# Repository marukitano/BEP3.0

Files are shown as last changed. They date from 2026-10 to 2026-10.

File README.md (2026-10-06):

# BEP3.0

**BEP3.0** is an electronics interface for classic BMW K-series motorcycles.

It was developed to make replacing the original instrument cluster ("Brotbox")
with an aftermarket speedometer easier while keeping the original wiring loom
as intact and reversible as possible.

This repository contains the **production and manufacturing files** for the
BEP3.0.

> **License notice:** The files in this repository may be copied, modified and
> used to build a BEP3.0 for **private, non-commercial purposes**.
> **Commercial use is prohibited.**
>
> The commercial right to sell BEP3.0 units is reserved exclusively to
> **Marcus Knop**. Third-party commercial manufacturing or sales require his
> explicit written permission.

## Supported motorcycles

The BEP3.0 was designed for the classic BMW K-series, including:

- BMW K75
- BMW K100
- BMW K1
- BMW K1100

Compatibility with a particular aftermarket instrument depends on the signals
and inputs supported by that instrument.

## What is in this repository?

The repository contains the files used to produce the BEP3.0 hardware, including
PCB/manufacturing data and related production files.

The files are published so that the project can be studied, preserved, repaired
and rebuilt by private users.

## License

### Allowed

- ✅ View and study the files
- ✅ Copy the files for private, non-commercial use
- ✅ Modify the files for private, non-commercial use
- ✅ Build your own BEP3.0 for private, non-commercial use
- ✅ Have a board manufactured for your own private, non-commercial use
- ✅ Share the files non-commercially if the license and attribution remain

### Not allowed

- ❌ Sell BEP3.0 units
- ❌ Sell bare PCBs based on the BEP3.0 design
- ❌ Sell kits based on the BEP3.0 design
- ❌ Offer paid manufacturing or assembly based on these files
- ❌ Use the BEP3.0 design, or substantial parts of it, in another commercial product
- ❌ Use the files for crowdfunding, pre-orders or other commercial fundraising

**All commercial rights remain reserved by Marcus Knop.**

Only Marcus Knop may offer BEP3.0 products for commercial sale. Commercial
manufacturing by third parties is only permitted with his explicit written
permission.

See [LICENSE](LICENSE) for the complete license terms.

> Because commercial use is restricted, this project is **source-available for
> private/non-commercial use** rather than open source in the OSI/open-hardware
> sense.

## Project page

More information about the BEP3.0:

https://maru-labs.com/portfolio/bep3-0-5/

## Contributions and issues

If you discover an error in the production files or documentation, please open
an issue before manufacturing a board.

## Disclaimer

The files are provided **as-is**, without warranty.

If you manufacture hardware from these files, you are responsible for checking
the design, component choices, manufacturing data, electrical safety and
suitability for your intended use.

---

**BEP3.0 / Maru Labs**  
Copyright © Marcus Knop

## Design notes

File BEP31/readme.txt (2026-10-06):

Hoi Fip

das einzige, was ich noch "mehr" habe ist die leiterbahn beim Blinker korrigieren, damit wir nichtmehr kratzen müssen. ansosnten hast du schon alles abgedeckt mit deiner liste.

Gruss Maru

Von: Philipp Gisler <pmgisler@gmx.ch>
Gesendet: Sonntag, 23. Oktober 2016 18:04
An: marcus.knop@outlook.com
Betreff: BEP änderungen brauche feedback
 
Hoi Marcus,
 
bin am layouten . kannst du mir deine Liste der Korrekturen noch schicken (asap)?
 
meine Änderungen umfassen:
1. die mittleren beiden Schrauben sollen keinen Kontakt auf Masse machen köönen
2. 78L10 footprint ändern und Masseverbindung herstellen die fehlte
3. Den Tiny switch footprint ändern dass man ihn auf die Platine runterlöten kann. IM 2. Schritt kommt er unter den BMW Stecker
4. Choke per default disabled
5. Bulb Test per default disabled
 
6. Reserve geht neu auf choke ODER einen switch unterhalb BMW Stecker zum Umschalten der Funktion (Reserve/Balkenanzeige) auf den Ausgang wie bisher (diese 2. Variante wird vom Platz vermutlich etwas eng)
7. neue Tachoschaltung gemäss BMW Original
8. einige Dioden auf Schottky Typ SS12 wechseln
9. Mosfet BSS138 am N Ausgang statt Darlington Array Ausgang
 
Gibt es sonst footprints die schlecht lötbar sind oder komische Beschriftungen?
 
Gruss
Philipp

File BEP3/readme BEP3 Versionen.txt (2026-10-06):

BEP3_RPM war ein erster Entwurf. Hier wird der BAR Graph Ausgang auf einen Lötpunkt gesetzt 
und der Reserve Ausgang ist wie bisher auf der Wago

BEP3_RPM_BAR wurde bei Seedstudion produziert. 
Hier wird die Idee umgesetzt, den BAR Graph Ausgang auf die Wago zu nehmen.
Achtung: dieses Layout hat Fehler:
1.10V Regler ist nicht auf GND verbunden
2. seitliche Schrauben berühren 12V und GND gleichzeitig.

BEP3_RPM_BAR_multi war bei Multi CB als Backup geplant, wurde aber nie bestellt. 
Der 78L10 Regler kann auf diesem Layout auch als Dreibein bestückt werden. Das Layout hat wohl auch Fehler

die komplette Historie befindet sich momentan im \Stücklisten Ordner

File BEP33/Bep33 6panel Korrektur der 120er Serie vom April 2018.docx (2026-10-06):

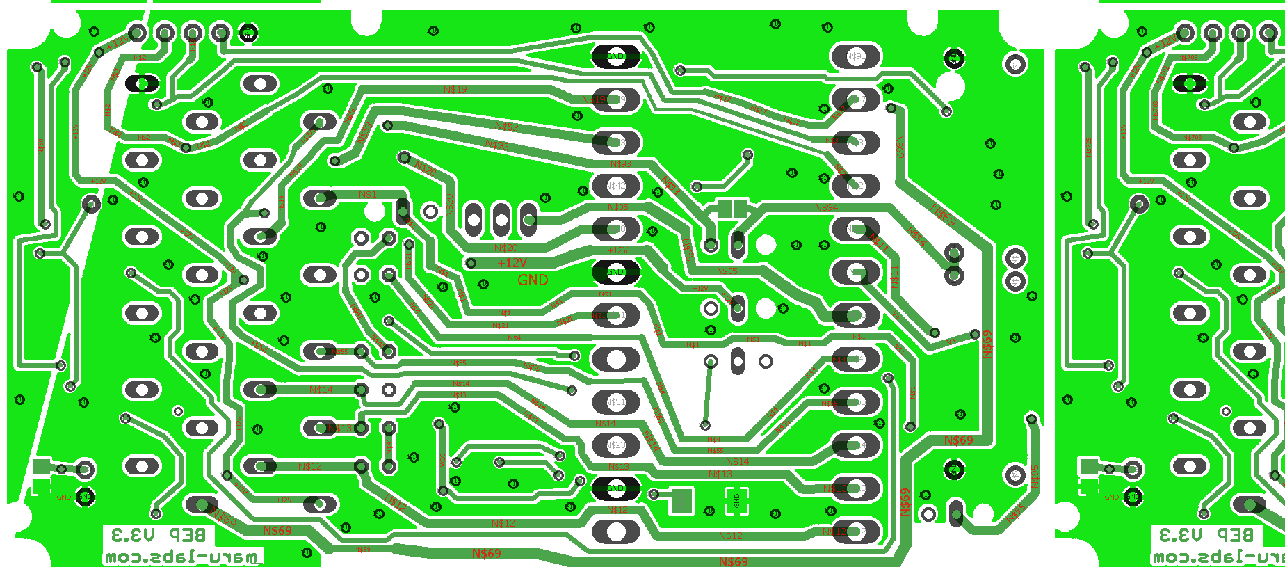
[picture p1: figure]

Hier mit Skalpell aufkratzen und Lötpunkt setzen. Es wird wohl auch ohne den Punkt funktionieren, würde das aber trotzdem tun zur Sicherheit und weil es hier sehr einfach ist

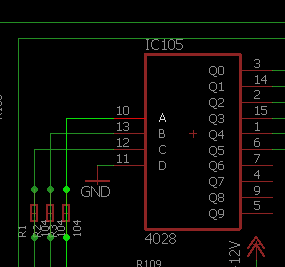
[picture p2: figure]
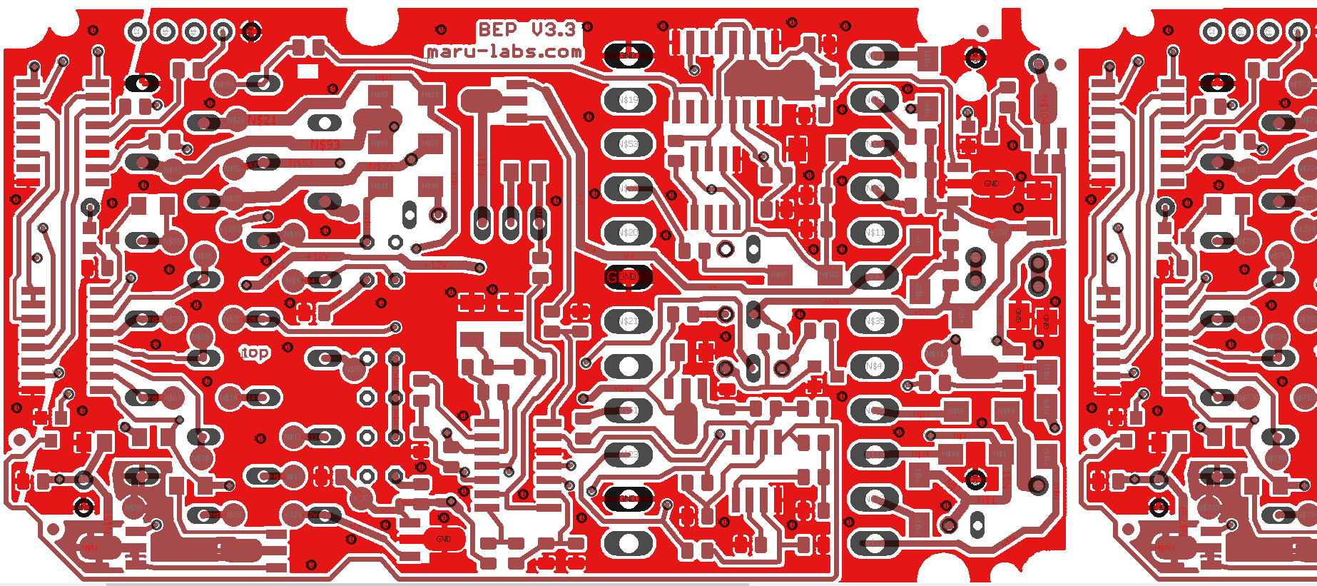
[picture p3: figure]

Das ist das Hauptproblem (pin 11):

Das Bein muss auf GND verbunden werden mit einem dünnen Draht. Wenn D nicht auf Masse ist, wird der BCD code um 2^3 zu viel dekodiert

Hier mit multimeter kurz checken ob das linke pad mit GND verbunden ist (es sollte eigentlich)→sonst würde stromquelle nicht laufen

Ev hier einen sicherheitsltötpunkt setzen, obwohl der Strom über das schwarze Pad fliessen sollte

Hier sieht man wie es orignal war

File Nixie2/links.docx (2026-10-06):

http://www.ebay.de/itm/QS30-1-Nixie-Rohren-NEU-Nanchang-V3-tube-tubes-Rohre-f-Uhr-Clock-NOS-ZM1022-/321815823694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

http://www.ebay.de/itm/new-13-pin-Nixie-Tube-Socket-for-GN4-ZM1020-B5092-B13B-PCB-monut-/391152356769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

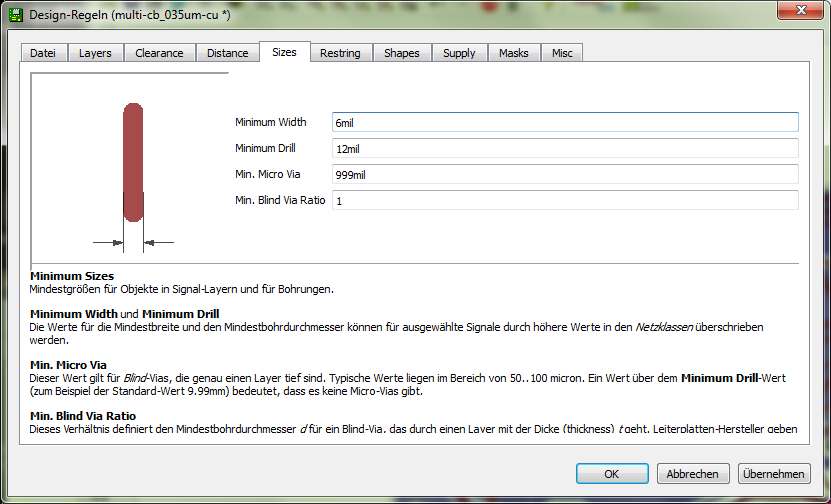
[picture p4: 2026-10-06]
design rules 2.png

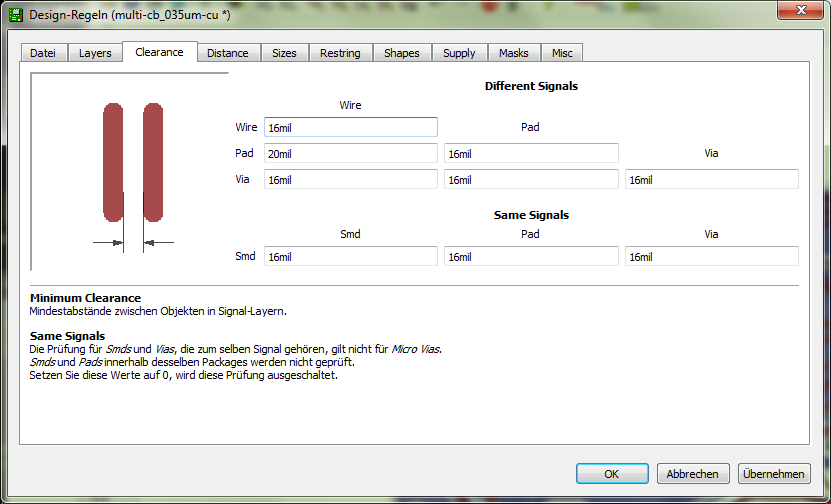
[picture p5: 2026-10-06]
design rules 1.png

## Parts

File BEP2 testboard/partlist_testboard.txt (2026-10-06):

Partlist

Exported from BMW_testboard.sch at 27.07.2015 17:11:16

EAGLE Version 6.4.0 Copyright (c) 1988-2013 CadSoft

Assembly variant: 

Part            Value          Device                   Package      Library             Sheet

öLDRUCK_SW2     TLLY4400       TLLY4400                 LED3MM       led                 1
12V             TPSPAD1-1.5MM  TPSPAD1-1.5MM            P1-13        testpin_BMW         1
12V_            TPSPAD1-1.5MM  TPSPAD1-1.5MM            P1-13        testpin_BMW         1
ABS_BLINK       TLLY4400       TLLY4400                 LED3MM       led                 1
BEIDE           TLLY4400       TLLY4400                 LED3MM       led                 1
BL              TPSPAD1-1.5MM  TPSPAD1-1.5MM            P1-13        testpin_BMW         1
BL-GR           TPSPAD1-1.5MM  TPSPAD1-1.5MM            P1-13        testpin_BMW         1
BL-RT           TPSPAD1-1.5MM  TPSPAD1-1.5MM            P1-13        testpin_BMW         1
BL-SW           TPSPAD1-1.5MM  TPSPAD1-1.5MM            P1-13        testpin_BMW         1
BR              TPSPAD1-1.5MM  TPSPAD1-1.5MM            P1-13        testpin_BMW         1
BR-GR           TPSPAD1-1.5MM  TPSPAD1-1.5MM            P1-13        testpin_BMW         1
BR-SW           TPSPAD1-1.5MM  TPSPAD1-1.5MM            P1-13        testpin_BMW         1
BR_             TPSPAD1-1.5MM  TPSPAD1-1.5MM            P1-13        testpin_BMW         1
C1              10u            C-EU025-024X044          C025-024X044 rcl                 1
C2              10u            C-EU025-024X044          C025-024X044 rcl                 1
C3              10n            C-EU025-024X044          C025-024X044 rcl                 1
CHOKE_SW1       TLLY4400       TLLY4400                 LED3MM       led                 1
DAUERPLUS       TLLY4400       TLLY4400                 LED3MM       led                 1
FERNLICHT_BLK   TLLY4400       TLLY4400                 LED3MM       led                 1
GANG_1          TLLY4400       TLLY4400                 LED3MM       led                 1
GANG_2          TLLY4400       TLLY4400                 LED3MM       led                 1
GANG_3          TLLY4400       TLLY4400                 LED3MM       led                 1
GANG_4          TLLY4400       TLLY4400                 LED3MM       led                 1
GANG_5          TLLY4400       TLLY4400                 LED3MM       led                 1
GB-SW           TPSPAD1-1.5MM  TPSPAD1-1.5MM            P1-13        testpin_BMW         1
GB-WS           TPSPAD1-1.5MM  TPSPAD1-1.5MM            P1-13        testpin_BMW         1
GE-BL           TPSPAD1-1.5MM  TPSPAD1-1.5MM            P1-13        testpin_BMW         1
GESCHW_WAGO_BLK TLLY4400       TLLY4400                 LED3MM       led                 1
GND_            TPSPAD1-1.5MM  TPSPAD1-1.5MM            P1-13        testpin_BMW         1
GR              TPSPAD1-1.5MM  TPSPAD1-1.5MM            P1-13        testpin_BMW         1
GR-SW           TPSPAD1-1.5MM  TPSPAD1-1.5MM            P1-13        testpin_BMW         1
IC1             4020N          4020N                    DIL16        40xx                1
IC2             NE555          NE555                    DIL-08       st-microelectronics 1
IC5             BTS141         BTS141                   TO220-3-45   optosonde_bruker    1
LADEKONTROL_BLK TLLY4400       TLLY4400                 LED3MM       led                 1
LAMPENTEST_SW4  TLLY4400       TLLY4400                 LED3MM       led                 1
LINKS           TLLY4400       TLLY4400                 LED3MM       led                 1
NEUTRAL         TLLY4400       TLLY4400                 LED3MM       led                 1
R1              390            R-EU_R0805               R0805        rcl                 1
R2              390            R-EU_R0805               R0805        rcl                 1
R3              390            R-EU_R0805               R0805        rcl                 1
R4              390            R-EU_R0805               R0805        rcl                 1
R5              390            R-EU_R0805               R0805        rcl                 1
R6              390            R-EU_R0805               R0805        rcl                 1
R7              390            R-EU_R0805               R0805        rcl                 1
R8              10k            R-EU_R0805               R0805        rcl                 1
R9              10k            R-EU_R0805               R0805        rcl                 1
R10             10k            R-EU_R0805               R0805        rcl                 1
R11             390            R-EU_R0805               R0805        rcl                 1
R12             10k            R-EU_R0805               R0805        rcl                 1
R13             10k            R-EU_0207/12             0207/12      rcl                 1
R14             20k            R-EU_0207/12             0207/12      rcl                 1
R15             390            R-EU_R0805               R0805        rcl                 1
R16             390            R-EU_R0805               R0805        rcl                 1
R17             10k            R-EU_R0805               R0805        rcl                 1
R18             390            R-EU_R0805               R0805        rcl                 1
R19             390            R-EU_R0805               R0805        rcl                 1
R20             390            R-EU_R0805               R0805        rcl                 1
R21             39             R-EU_0207/12             0207/12      rcl                 1
R22             100            R-EU_0207/12             0207/12      rcl                 1
R23             10k            R-EU_R0805               R0805        rcl                 1
R27             0              R-EU_0207/12             0207/12      rcl                 1
R28             390            R-EU_R0805               R0805        rcl                 1
R29             390            R-EU_R0805               R0805        rcl                 1
R30             390            R-EU_R0805               R0805        rcl                 1
R31             390            R-EU_R0805               R0805        rcl                 1
R32             10k            R-EU_0207/12             0207/12      rcl                 1
R33             10k            R-EU_0207/15             0207/15      rcl                 1
RECHT           TLLY4400       TLLY4400                 LED3MM       led                 1
S1              DTE6K          DTE6K                    DTE6K        switch              1
S2              DTE6K          DTE6K                    DTE6K        switch              1
S3              DTE6K          DTE6K                    DTE6K        switch              1
S4              DTE6K          DTE6K                    DTE6K        switch              1
START/NEUTRAL   TLLY4400       TLLY4400                 LED3MM       led                 1
SW-GR           TPSPAD1-1.5MM  TPSPAD1-1.5MM            P1-13        testpin_BMW         1
T1                             MMBTA42LT1-NPN-SOT23-BEC SOT23-BEC    transistor          1
T2                             MMBTA42LT1-NPN-SOT23-BEC SOT23-BEC    transistor          1
T3                             MMBTA42LT1-NPN-SOT23-BEC SOT23-BEC    transistor          1
TACHSIG_REL_BLK TLLY4400       TLLY4400                 LED3MM       led                 1
TANKGEB_SW1-4   TLLY4400       TLLY4400                 LED3MM       led                 1
TEMP...SW3      TLLY4400       TLLY4400                 LED3MM       led                 1
TP12            TPSPAD1-1.5MM  TPSPAD1-1.5MM            P1-13        testpin_BMW         1
TP13            TPSPAD1-1.5MM  TPSPAD1-1.5MM            P1-13        testpin_BMW         1
TP14            TPSPAD1-1.5MM  TPSPAD1-1.5MM            P1-13        testpin_BMW         1
TP15            TPSPAD1-1.5MM  TPSPAD1-1.5MM            P1-13        testpin_BMW         1
TP20            TPSPAD1-1.5MM  TPSPAD1-1.5MM            P1-13        testpin_BMW         1
TP27            TPSPAD1-1.5MM  TPSPAD1-1.5MM            P1-13        testpin_BMW         1
TP28            TPSPAD1-1.5MM  TPSPAD1-1.5MM            P1-13        testpin_BMW         1
TP29            TPSPAD1-1.5MM  TPSPAD1-1.5MM            P1-13        testpin_BMW         1
TP31            TPSPAD1-1.5MM  TPSPAD1-1.5MM            P1-13        testpin_BMW         1
TP32            TPSPAD1-1.5MM  TPSPAD1-1.5MM            P1-13        testpin_BMW         1
TP33            TPSPAD1-1.5MM  TPSPAD1-1.5MM            P1-13        testpin_BMW         1
TP34            TPSPAD1-1.5MM  TPSPAD1-1.5MM            P1-13        testpin_BMW         1
TP35            TPSPAD1-1.5MM  TPSPAD1-1.5MM            P1-13        testpin_BMW         1
TP36            TPSPAD1-1.5MM  TPSPAD1-1.5MM            P1-13        testpin_BMW         1
TP37            TPSPAD1-1.5MM  TPSPAD1-1.5MM            P1-13        testpin_BMW         1
TP38            TPSPAD1-1.5MM  TPSPAD1-1.5MM            P1-13        testpin_BMW         1
TP39            TPSPAD1-1.5MM  TPSPAD1-1.5MM            P1-13        testpin_BMW         1
TP40            TPSPAD1-1.5MM  TPSPAD1-1.5MM            P1-13        testpin_BMW         1
TP41            TPSPAD1-1.5MM  TPSPAD1-1.5MM            P1-13        testpin_BMW         1
TP42            TPSPAD1-1.5MM  TPSPAD1-1.5MM            P1-13        testpin_BMW         1
TP43            TPSPAD1-1.5MM  TPSPAD1-1.5MM            P1-13        testpin_BMW         1
TP44            TPSPAD1-1.5MM  TPSPAD1-1.5MM            P1-13        testpin_BMW         1
VI-SW           TPSPAD1-1.5MM  TPSPAD1-1.5MM            P1-13        testpin_BMW         1
VI-WS           TPSPAD1-1.5MM  TPSPAD1-1.5MM            P1-13        testpin_BMW         1
WARNLAMPE_SW4   TLLY4400       TLLY4400                 LED3MM       led                 1
WS              TPSPAD1-1.5MM  TPSPAD1-1.5MM            P1-13        testpin_BMW         1
WS-BL           TPSPAD1-1.5MM  TPSPAD1-1.5MM            P1-13        testpin_BMW         1
WS_             TPSPAD1-1.5MM  TPSPAD1-1.5MM            P1-13        testpin_BMW         1
ZüNDUNGSPLUS    TLLY4400       TLLY4400                 LED3MM       led                 1

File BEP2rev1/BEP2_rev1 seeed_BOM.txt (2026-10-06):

Bill of Material from BEP2_rev1 seeed.sch, 97 parts, as of 05.05.2016 11:49:22

Part		Description					Sheet
1		WAGO SREW CLAMP					1
2		WAGO SREW CLAMP					1
C1		CAPACITOR, European symbol			1
C2		302010183					1
C3		302010183					1
C4		302010165					1
C5		302010165					1
C6		CAPACITOR, European symbol			1
C7		CAPACITOR, European symbol			1
C8		302010146					1
D1		304010013					1
D2		304010013					1
D8		304010013					1
D10		304010013					1
D11		304010013					1
D12		304010013					1
D13		304010013					1
D14		304010013					1
D15		304010013					1
IC1		VOLTAGE REGULATOR				1
IC3		BCD to decimal DECODER				1
IC4		Positive VOLTAGE REGULATOR			1
IC6		DRIVER ARRAY					1
IC7		Low Power Low Offset Voltage Quad Comparators	1
J1		.100" (2.54mm) Center Header - 2 Pin		1
LED1		LED						1
LED2		LED						1
LED3		LED						1
LED4		LED						1
LED5		LED						1
LED6		LED						1
LED7		LED						1
Q1		305030010					1
Q2		305020006					1
Q3		 						1
R1		301010306					1
R2		301010361					1
R3		301010315					1
R4		301010319					1
R5		301010361					1
R6		301010361					1
R7		301010104					1
R8		301010104					1
R9		301010306					1
R10		301010196					1
R11		301010319					1
R12		301010196					1
R13		301010311					1
R14		301010196					1
R15		301010241					1
R16		301010361					1
R17		301010333					1
R18		301010405					1
R19		301010361					1
R20		301010405					1
R21		301010405					1
R22		RESISTOR, European symbol			1
R23		RESISTOR, European symbol			1
R24		RESISTOR, European symbol			1
R25		RESISTOR, European symbol			1
R26		RESISTOR, European symbol			1
R27		RESISTOR, European symbol			1
R28		RESISTOR, European symbol			1
R29		301010196					1
R30		301010196					1
R31		301010196					1
R32		RESISTOR, European symbol			1
R38		301010311					1
R39		RESISTOR, European symbol			1
T1		 						1
TACHO_BEL	TEST PIN					1
TP1		TEST PIN					1
TP2		TEST PIN					1
TP3		TEST PIN					1
TP4		TEST PIN					1
TP5		TEST PIN					1
TP6		TEST PIN					1
TP7		TEST PIN					1
TP8		TEST PIN					1
TP9		TEST PIN					1
TP10		TEST PIN					1
TP11		TEST PIN					1
TP12		TEST PIN					1
TP16		TEST PIN					1
TP17		TEST PIN					1
TP18		TEST PIN					1
TP19		TEST PIN					1
TP21		TEST PIN					1
TP22		TEST PIN					1
TP23		TEST PIN					1
TP24		TEST PIN					1
TP25		TEST PIN					1
TP26		TEST PIN					1
X1		BMW CONNECTOR					1
X2		.100" (2.54mm) Center Header - 2 Pin		1
X3		.100" (2.54mm) Center Header - 5 Pin		1
ZüNDSPULE	TEST PIN					1

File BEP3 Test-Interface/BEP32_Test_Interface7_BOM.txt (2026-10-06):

Stückliste exportiert aus D:/marulabs/Layout_Eagle/BEP3 Test-Interface/BEP32_Test_Interface7.sch am 18.02.2018 18:58

Part                        Value                Device                             Package          Description                                                             MF                   MPN      OC_FARNELL OC_NEWARK VALUE 
2.5VTOAD                                         1,6/0,9                            1,6/0,9          THROUGH-HOLE PAD                                                                                                                 
2.5VTOAD1                                        1,6/0,9                            1,6/0,9          THROUGH-HOLE PAD                                                                                                                 
2.5VTOAD2                                        1,6/0,9                            1,6/0,9          THROUGH-HOLE PAD                                                                                                                 
6V_OK_BOT                                        1,6/0,9                            1,6/0,9          THROUGH-HOLE PAD                                                                                                                 
6V_OK_TOP                                        1,6/0,9                            1,6/0,9          THROUGH-HOLE PAD                                                                                                                 
6V_VOLTAGE_BOT                                   1,6/0,9                            1,6/0,9          THROUGH-HOLE PAD                                                                                                                 
6V_VOLTAGE_TOP                                   1,6/0,9                            1,6/0,9          THROUGH-HOLE PAD                                                                                                                 
10V_OK_BOT                                       1,6/0,9                            1,6/0,9          THROUGH-HOLE PAD                                                                                                                 
10V_OK_TOP                                       1,6/0,9                            1,6/0,9          THROUGH-HOLE PAD                                                                                                                 
10V_VOLTAGE_BOT                                  1,6/0,9                            1,6/0,9          THROUGH-HOLE PAD                                                                                                                 
10V_VOLTAGE_TOP                                  1,6/0,9                            1,6/0,9          THROUGH-HOLE PAD                                                                                                                 
C1                          tbd                  C-EUC1206K                         C1206K           CAPACITOR, European symbol                                                                                                       
C2                          4.7uf                C-EU025_050-025X075                C025_050-025X075 CAPACITOR, European symbol                                                                                                       
C3                          100nF                C-EUC1206K                         C1206K           CAPACITOR, European symbol                                                                                                       
C4                          tbd                  C-EUC1206K                         C1206K           CAPACITOR, European symbol                                                                                                       
C5                          100nF                C-EUC1206K                         C1206K           CAPACITOR, European symbol                                                                                                       
CC_VOLTAGE_BOT                                   1,6/0,9                            1,6/0,9          THROUGH-HOLE PAD                                                                                                                 
CC_VOLTAGE_OK_BOT                                1,6/0,9                            1,6/0,9          THROUGH-HOLE PAD                                                                                                                 
CC_VOLTAGE_OK_TOP                                1,6/0,9                            1,6/0,9          THROUGH-HOLE PAD                                                                                                                 
CC_VOLTAGE_TOP                                   1,6/0,9                            1,6/0,9          THROUGH-HOLE PAD                                                                                                                 
D1                          1N4007               DIODE-GEN-PURPOSE-1KV-1A(DO-214AC) DO-214AC         304010013                                                                                    1N4007                        1N4007
D2                          4V7                  ZENER-DIODEF126-10                 F126Z10          Z-Diode                                                                                                                          
D3                          4V7                  ZENER-DIODEF126-10                 F126Z10          Z-Diode                                                                                                                          
D4                          1N4007               DIODE-GEN-PURPOSE-1KV-1A(DO-214AC) DO-214AC         304010013                                                                                    1N4007                        1N4007
DISABLE_MANUAL_BOT                               1,6/0,9                            1,6/0,9          THROUGH-HOLE PAD                                                                                                                 
DISABLE_MANUAL_TOP                               1,6/0,9                            1,6/0,9          THROUGH-HOLE PAD                                                                                                                 
IC1                         74HC595N             74HC595N                           DIL16            8-bit SHIFT REGISTER, output latch                                                                                               
IC3                         4532N                4532N                              DIL16            8-bit PRIORITY ENCODER                                                                                                           
IC5                         ULN2003              ULN2803A                           DIL18            DRIVER ARRAY                                                                                                                     
IC6                         74HC595N             74HC595N                           DIL16            8-bit SHIFT REGISTER, output latch                                                                                               
IC7                         ULN2003              ULN2803A                           DIL18            DRIVER ARRAY                                                                                                                     
IC8                         74HC165N             74HC165N                           DIL16            8-bit parallel load SHIFT REGISTER                                                                                               
IC9                         74HC165N             74HC165N                           DIL16            8-bit parallel load SHIFT REGISTER                                                                                               
IC10                        74HC165N             74HC165N                           DIL16            8-bit parallel load SHIFT REGISTER                                                                                               
IC11                        4046N                4046N                              DIL16            Micropower PLL                                                                                                                   
IC12                        4070N                4070N                              DIL14            Quad 2-input XOR                                                                                                                 
IC13                        LM358N               LM358N                             DIL08            OP AMP also LM158; LM258; LM2904                                                                                                 
IC14                        4053N                4053N                              DIL16            Triple 2-channel ANALOG MULTIPLEXER                                                                                              
IC15                        74HC132N             74HC132N                           DIL14            Quad 2-input NAND schmitt trigger                                                                                                
IC16                        LM358N               LM358N                             DIL08            OP AMP also LM158; LM258; LM2904                                                                                                 
IC18                        LM358N               LM358N                             DIL08            OP AMP also LM158; LM258; LM2904                                                                                                 
IC20                        4046N                4046N                              DIL16            Micropower PLL                                                                                                                   
IC21                        4070N                4070N                              DIL14            Quad 2-input XOR                                                                                                                 
JP1                                              JP2E                               JP2              JUMPER                                                                                                                           
JP2                                              JP2E                               JP2              JUMPER                                                                                                                           
JP3                                              JP2E                               JP2              JUMPER                                                                                                                           
JP4                                              JP1E                               JP1              JUMPER                                                                                                                           
JP5                                              JP1E                               JP1              JUMPER                                                                                                                           
LED_6V_HIGH                                      LED5MM                             LED5MM           LED                                                                                                                              
LED_6V_LOW                                       LED5MM                             LED5MM           LED                                                                                                                              
LED_6V_OK                                        LED5MM                             LED5MM           LED                                                                                                                              
LED_10V_HIGH                                     LED5MM                             LED5MM           LED                                                                                                                              
LED_10V_LOW                                      LED5MM                             LED5MM           LED                                                                                                                              
LED_10V_OK                                       LED5MM                             LED5MM           LED                                                                                                                              
LED_<                                            LED5MM                             LED5MM           LED                                                                                                                              
LED_<>                                           LED5MM                             LED5MM           LED                                                                                                                              
LED_>                                            LED5MM                             LED5MM           LED                                                                                                                              
LED_ABS                                          LED5MM                             LED5MM           LED                                                                                                                              
LED_ALT                                          LED5MM                             LED5MM           LED                                                                                                                              
LED_BT                                           LED5MM                             LED5MM           LED                                                                                                                              
LED_CC                                           LED5MM                             LED5MM           LED                                                                                                                              
LED_CC_HIGH                                      LED5MM                             LED5MM           LED                                                                                                                              
LED_CC_LOW                                       LED5MM                             LED5MM           LED                                                                                                                              
LED_CC_OK                                        LED5MM                             LED5MM           LED                                                                                                                              
LED_CHK                                          LED5MM                             LED5MM           LED                                                                                                                              
LED_DREHZAHL                                     LED5MM                             LED5MM           LED                                                                                                                              
LED_G1                                           LED5MM                             LED5MM           LED                                                                                                                              
LED_G2                                           LED5MM                             LED5MM           LED                                                                                                                              
LED_G3                                           LED5MM                             LED5MM           LED                                                                                                                              
LED_G4                                           LED5MM                             LED5MM           LED                                                                                                                              
LED_G5                                           LED5MM                             LED5MM           LED                                                                                                                              
LED_HIB                                          LED5MM                             LED5MM           LED                                                                                                                              
LED_N                                            LED5MM                             LED5MM           LED                                                                                                                              
LED_OIL                                          LED5MM                             LED5MM           LED                                                                                                                              
LED_RES                                          LED5MM                             LED5MM           LED                                                                                                                              
LED_SPD                                          LED5MM                             LED5MM           LED                                                                                                                              
LED_START                                        LED5MM                             LED5MM           LED                                                                                                                              
LED_SWP                                          LED5MM                             LED5MM           LED                                                                                                                              
LED_TMP                                          LED5MM                             LED5MM           LED                                                                                                                              
LED_WRN                                          LED5MM                             LED5MM           LED                                                                                                                              
PAD1                                             1,6/0,9                            1,6/0,9          THROUGH-HOLE PAD                                                                                                                 
PAD_2_RPM_FREQUENZZäHLER2                        1,6/0,9                            1,6/0,9          THROUGH-HOLE PAD                                                                                                                 
PAD_2_SPEED_FREQUENZZäHLER1                      1,6/0,9                            1,6/0,9          THROUGH-HOLE PAD                                                                                                                 
PAD_6V_TEST                                      1,6/0,9                            1,6/0,9          THROUGH-HOLE PAD                                                                                                                 
PAD_10V_TEST                                     1,6/0,9                            1,6/0,9          THROUGH-HOLE PAD                                                                                                                 
PAD_12V_IN                                       1,6/0,9                            1,6/0,9          THROUGH-HOLE PAD                                                                                                                 
PAD_GND                                          1,6/0,9                            1,6/0,9          THROUGH-HOLE PAD                                                                                                                 
PAD_RESERVE_SPANNUNG                             1,6/0,9                            1,6/0,9          THROUGH-HOLE PAD                                                                                                                 
Q1                          BSP452T1             BSP452T1                           SOT223                                                                                                                                            
Q2                          BSP452T1             BSP452T1                           SOT223                                                                                                                                            
Q3                          BSP452T1             BSP452T1                           SOT223                                                                                                                                            
Q4                          BSP452T1             BSP452T1                           SOT223                                                                                                                                            
Q5                          IRF540               IRF540                             TO220BV          HEXFET Power MOSFET                                                                                                              
Q6                          IRF540               IRF540                             TO220BV          HEXFET Power MOSFET                                                                                                              
Q7                          IRF540               IRF540                             TO220BV          HEXFET Power MOSFET                                                                                                              
Q8                          BC548                BC548                              TO92-EBC         NPN Transistor                                                                                                                   
Q9                          BSS138               BSS138                             SOT23            BSS138 N-Channel Logic Level Enhancement Mode Field Effect Transistor   Fairchild            BSS138   9845330    67R2009         
Q10                         BSS138               BSS138                             SOT23            BSS138 N-Channel Logic Level Enhancement Mode Field Effect Transistor   Fairchild            BSS138   9845330    67R2009         
Q12                         BSS138               BSS138                             SOT23            BSS138 N-Channel Logic Level Enhancement Mode Field Effect Transistor   Fairchild            BSS138   9845330    67R2009         
Q13                         BSS138               BSS138                             SOT23            BSS138 N-Channel Logic Level Enhancement Mode Field Effect Transistor   Fairchild            BSS138   9845330    67R2009         
R1                          100                  R-EU_0207/10                       0207/10          RESISTOR, European symbol                                                                                                        
R2                          39                   R-EU_0207/10                       0207/10          RESISTOR, European symbol                                                                                                        
R3                          10k                  R-EU_0207/10                       0207/10          RESISTOR, European symbol                                                                                                        
R4                          22k                  R-EU_0207/10                       0207/10          RESISTOR, European symbol                                                                                                        
R5                          100k                 R-EU_0207/10                       0207/10          RESISTOR, European symbol                                                                                                        
R6                          100k                 R-EU_0207/10                       0207/10          RESISTOR, European symbol                                                                                                        
R7                          2.2k                 R-EU_0207/10                       0207/10          RESISTOR, European symbol                                                                                                        
R11                         R_fmax               R-EU_0207/10                       0207/10          RESISTOR, European symbol                                                                                                        
R12                         R_fmin=inf           R-EU_0207/10                       0207/10          RESISTOR, European symbol                                                                                                        
R13                         100k                 R-EU_0207/10                       0207/10          RESISTOR, European symbol                                                                                                        
R14                         10k                  R-EU_0207/10                       0207/10          RESISTOR, European symbol                                                                                                        
R15                         39                   R-EU_0207/10                       0207/10          RESISTOR, European symbol                                                                                                        
R16                         1.05k                R-EU_0207/10                       0207/10          RESISTOR, European symbol                                                                                                        
R17                         210                  R-EU_0207/10                       0207/10          RESISTOR, European symbol                                                                                                        
R18                         10k                  R-EU_0207/10                       0207/10          RESISTOR, European symbol                                                                                                        
R19                         10k                  R-EU_0207/10                       0207/10          RESISTOR, European symbol                                                                                                        
R20                         10k                  R-EU_0207/10                       0207/10          RESISTOR, European symbol                                                                                                        
R21                         10k                  R-EU_0207/10                       0207/10          RESISTOR, European symbol                                                                                                        
R22                         10k                  R-EU_0207/10                       0207/10          RESISTOR, European symbol                                                                                                        
R23                         3k                   R-EU_0207/10                       0207/10          RESISTOR, European symbol                                                                                                        
R24                         1k                   R-EU_0207/10                       0207/10          RESISTOR, European symbol                                                                                                        
R25                         2.8k                 R-EU_0207/10                       0207/10          RESISTOR, European symbol                                                                                                        
R26                         2k                   R-EU_0207/10                       0207/10          RESISTOR, European symbol                                                                                                        
R30                         10k                  R-EU_0207/10                       0207/10          RESISTOR, European symbol                                                                                                        
R31                         10k                  R-EU_0207/10                       0207/10          RESISTOR, European symbol                                                                                                        
R32                         10k                  R-EU_0207/10                       0207/10          RESISTOR, European symbol                                                                                                        
R33                         10k                  R-EU_0207/10                       0207/10          RESISTOR, European symbol                                                                                                        
R34                         10k                  R-EU_0207/10                       0207/10          RESISTOR, European symbol
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

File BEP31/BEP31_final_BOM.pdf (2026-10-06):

Dimensionen:
Board: | 96mmx50mm. FR4 1.6mm, HASL verzinnt (lead free)
Stückzahl | 500 und 1000

BOM:
Qty | Value | Package | Device | Parts | Description MPN
6 100nF | C0805 | CERAMIC-100NF-50V-10%-X7R(0805) C4, C5, C7, C9, C10, C11 | 302010165 CC0805KRX7R9BB104
1 2.2nF | C0805 | CERAMIC-100NF-50V-10%-X7R(0805) C1 | 302010165 CC0805KRX7R9BB104
1 4.7u | C0805 | CERAMIC-4.7UF-25V-10%-X5R(0805) C8 | 302010146 CC0805KKX5R8BB475
2 100u | C1206 | CERAMIC-100UF-6.3V-20%-X5R(1206) C2, C3 | 302010183 GRM31CR60J107ME39L
6 1N4007 | DO-214AC | DIODE-GEN-PURPOSE-1KV-1A(DO-214AC) D1, D3, D8, D10, D11, D15 | 304010013 1N4007
| 4 1N5817 | DO-214AC | Schottky Diode | D2, D12, D13, D14 | 304010013
| 1 NE555D | SO08 | NE555D | IC5 | TIMER
| 1 LM2904 | SO08 | LM358D | IC10 | OP AMP also LM158; LM258; LM2904
| 1 LM339 | SO14 | LM339D | IC7 | Low Power Quad Comparators
| 1 4028 | SO16 | 4028D | IC3 | BCD to decimal DECODER
| 1 4538 | SO16 | 4538D | IC8 | Dual monostable MULTIVIBRATOR
| 1 ULN2004 | SO16 | ULN2004AD | IC6 | DRIVER ARRAY
2 J1 BSS-138 | SOT-23 | SMD-MOSFET-N-CH-50V-200MA-BSS138W-7-F(SOT-23) Q10, Q11 | 305030000 BSS138W-7-F
4 BA | SOT89 | PNP-TRANSISTOR_SOT89 Q1, Q2, Q7, Q8 | PNP TRANSISTOR
1 MY | SOT89 | NPN-TRANSISTOR_SOT89 Q9 | NPN TRANSISTOR
| 1 10V pos | SOT89 | 78L10 | IC2 | VOLTAGE REGULATOR
| 1 6V pos | SOT89 | 78L06 | IC1 | VOLTAGE REGULATOR
| 2 100 | R0805 | 10R | R3,R7 | 301010315 RC0805JR-07220RL
| 5 1002 | R0805 | 10k | R2, R5, R16, R19, R42 | 301010361 RC0805FR-0710KL
| 5 102 | R0805 | 1k | R13, R38, R43, R45, R46 | 301010311 RC0805JR-071KL
7 104 | R0805 | 100k | R10, R12, R22, R24, R29, R30, R31 301010361 RC0805FR-0710KL
| 2 1502 | R0805 | 15k | R6, R15 | 301010361 RC0805FR-0710KL
| 2 2201 | R0805 | 2k2 | R17, R23 | 301010333 RC0805JR-072K2L
| 5 2702 | R0805 | 27k | R8, R25, R44,R33,R34 | 301010306 RC0805JR-074K7L
| 3 4701 | R0805 | 4k7 | R1, R9, R32 | 301010306 RC0805JR-074K7L
| 3 13 | R1206 | 13R | R18, R20, R21 | 301010405 RC1206JR-0713RL
Optionale Teile
1 NUP4304SOT457_RSOT457R_PHILIPS | NUP4304SOT457_R U$3
| 1 SM6T | DO214AA | SM6T | D4 | Z DIODE
| 1 SM6T | DO214AA | SM6T | D5 | Z DIODE

BOM Zusammenfassung:
Anzahl Bauteile | Anzahl unterschiedliche Werte | Package | Anzahl Pads/Bauteil | totale Anzahl Pads
Resistors | 31 3 | 8 1 | 805 1206 | 2 2 | 62 6
Kond | 10 | 4 | 0805/1206 | 2 | 20
Diodes | 10 | 2 | DO-214AC | 2 | 20
IC | 2 1 3 | 2 1 3 | SO08 SO14 SO16 | 8 14 16 | 16 14 48
Transistors & Regler | 2 7 | 1 4 | SOT-23 SOT89 | 3 4 | 6 28
Total count | 69 | 26 | 8 | | 220
optional | 1 | 1 | SOT457 | 6 | 6
| 1 | 1 | DO214AA | 2 | 2
| 1 | 1 | DO214AA | 2 | 2
Total count | 3 | 3 | 2 | | 10

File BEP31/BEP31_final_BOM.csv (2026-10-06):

Qty | Value | Device | Package | Parts | Description | MF | MPN | OC_FARNELL | OC_NEWARK | TP | TP_SIGNAL_NAME | VALUE
2 |  | 2081-1132 | 12-PIN | 1, 2 | WAGO SREW CLAMP
2 |  | 78LXXSOT89_ROUND | SOT89_ROUND | IC2, IC9
1 |  | CON_BMWV2 | 24-PIN_V2 | X1 | BMW CONNECTOR
4 |  | JP2EJP2_SMALLPADS | JP2_SMALLPADS | JP1, JP2, JP3, JP4 | JUMPER
6 |  | LEDLD260 | LD260 | LED1, LED2, LED3, LED4, LED6, LED7 | LED
4 |  | PNP-TRANSISTOR_SOT89 | SOT89 | Q1, Q2, Q7, Q8 | PNP TRANSISTOR
1 | (1000) | SMD-RES-100R-5%-1/8W(0805) | R0805 | R11 | 301010319 |  | RC0805JR-07100RL |  |  |  |  | 100R
1 | (1002) | SMD-RES-4.7K-5%-1/8W(0805) | R0805 | R35 | 301010306 |  | RC0805JR-074K7L |  |  |  |  | 4.7K
1 | (101) | SMD-RES-100R-5%-1/8W(0805) | R0805 | R4 | 301010319 |  | RC0805JR-07100RL |  |  |  |  | 100R
1 | (101) | SMD-RES-2.2K-5%-1/8W(0805) | R0805 | R14 | 301010333 |  | RC0805JR-072K2L |  |  |  |  | 2.2K
1 | 100 | SMD-RES-2.2K-5%-1/8W(0805) | R0805 | R7 | 301010333 |  | RC0805JR-072K2L |  |  |  |  | 2.2K
1 | 100 | SMD-RES-220R-5%-1/8W(0805) | R0805 | R3 | 301010315 |  | RC0805JR-07220RL |  |  |  |  | 220R
5 | 1002 | SMD-RES-10K-1%-1/8W(0805) | R0805 | R2, R5, R16, R19, R42 | 301010361 |  | RC0805FR-0710KL |  |  |  |  | 10K
6 | 100nF | CERAMIC-100NF-50V-10%-X7R(0805) | C0805 | C4, C5, C7, C9, C10, C11 | 302010165 |  | CC0805KRX7R9BB104 |  |  |  |  | 100nf
2 | 100u | CERAMIC-100UF-6.3V-20%-X5R(1206) | C1206 | C2, C3 | 302010183 |  | GRM31CR60J107ME39L |  |  |  |  | 100uf
5 | 102 | SMD-RES-1K-5%-1/8W(0805) | R0805 | R13, R38, R43, R45, R46 | 301010311 |  | RC0805JR-071KL |  |  |  |  | 1K
7 | 104 | SMD-RES-10K-1%-1/8W(0805) | R0805 | R10, R12, R22, R24, R29, R30, R31 | 301010361 |  | RC0805FR-0710KL |  |  |  |  | 10K
3 | 13 | SMD-RES-13R-5%-1/4W(1206) | R1206 | R18, R20, R21 | 301010405 |  | RC1206JR-0713RL |  |  |  |  | 13R
2 | 1502 | SMD-RES-10K-1%-1/8W(0805) | R0805 | R6, R15 | 301010361 |  | RC0805FR-0710KL |  |  |  |  | 10K
6 | 1N4007 | DIODE-GEN-PURPOSE-1KV-1A(DO-214AC) | DO-214AC | D1, D3, D8, D10, D11, D15 | 304010013 |  | 1N4007 |  |  |  |  | 1N4007
4 | 1N4007 | DIODE-GEN-PURPOSE-1KV-1A(DO-214AC)DO-214AC/1206 | DO-214AC-1206MOUNT | D2, D12, D13, D14 | 304010013
1 | 2.2nF | CERAMIC-100NF-50V-10%-X7R(0805) | C0805 | C1 | 302010165 |  | CC0805KRX7R9BB104 |  |  |  |  | 100nf
1 | 22-23-2021 | 22-23-2021 | 22-23-2021 | X2 | .100 (2.54mm) Center Header - 2 Pin" | MOLEX | 22-23-2021 | 1462926 | 25C3832
1 | 22-23-2051 | 22-23-2051 | 22-23-2051 | X3 | .100 (2.54mm) Center Header - 5 Pin" | MOLEX | 22-23-2051 | 1462952 | 38C9178
2 | 2201 | SMD-RES-2.2K-5%-1/8W(0805) | R0805 | R17, R23 | 301010333 |  | RC0805JR-072K2L |  |  |  |  | 2.2K
1 | 2702 | SMD-RES-10K-1%-1/8W(0805) | R0805 | R33 | 301010361 |  | RC0805FR-0710KL |  |  |  |  | 10K
3 | 2702 | SMD-RES-4.7K-5%-1/8W(0805) | R0805 | R8, R25, R44 | 301010306 |  | RC0805JR-074K7L |  |  |  |  | 4.7K
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

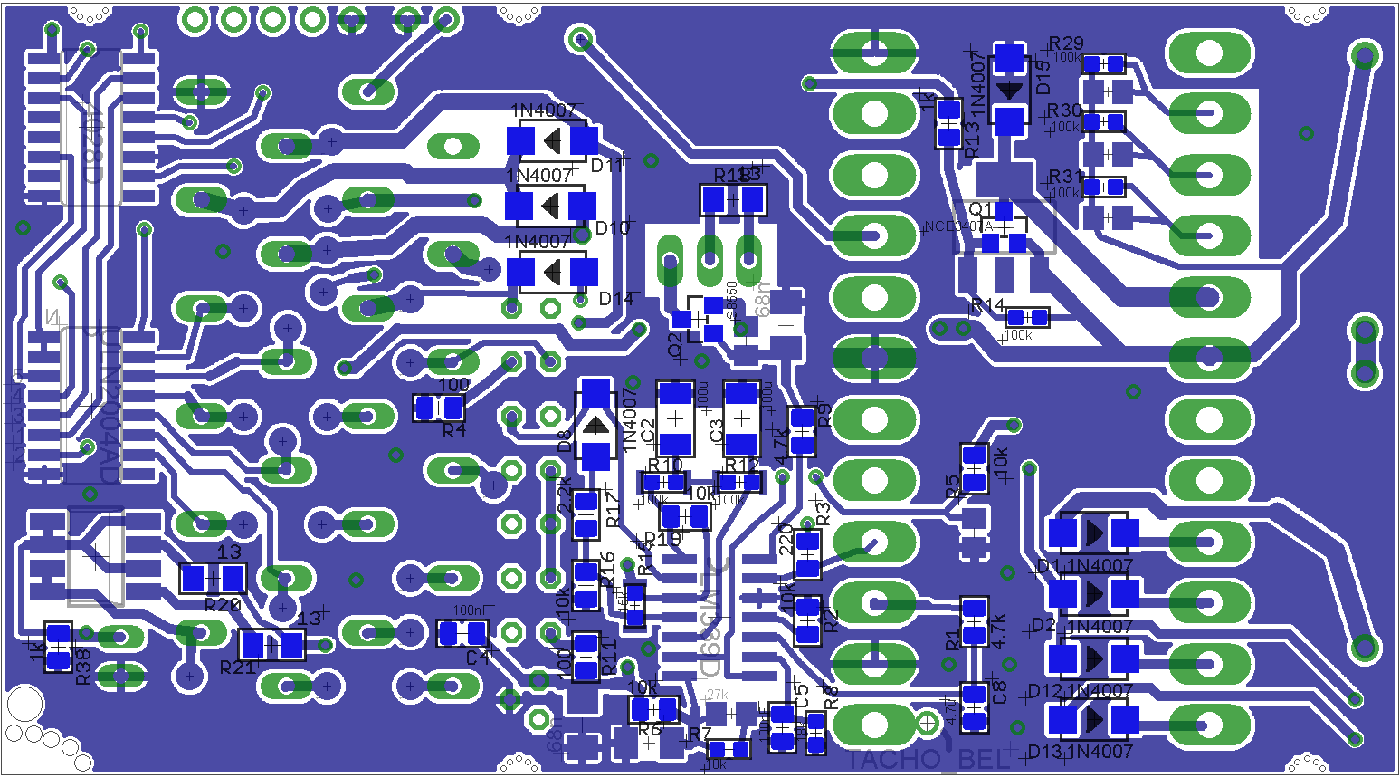
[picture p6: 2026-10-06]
BEP2rev1/Seeed Components Placements highlighted on Bottom.png

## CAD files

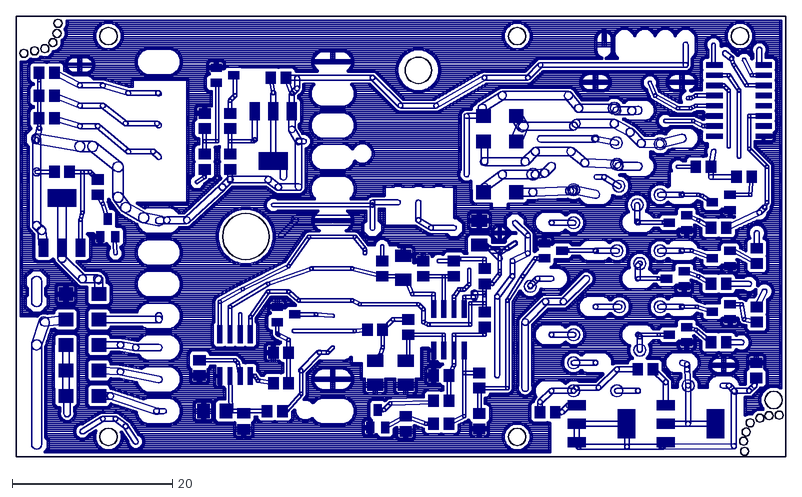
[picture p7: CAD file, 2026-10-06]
BEP2 final/dxf/BMW_final_Bottom_LeiterundGND_ohnepads.dxf
96.0 x 55.0

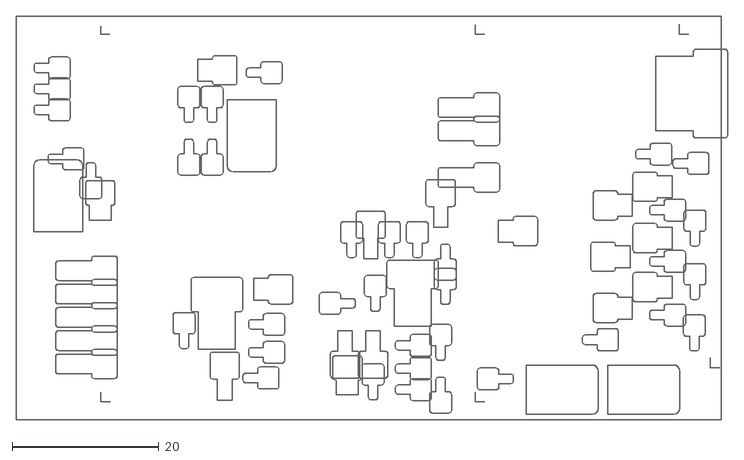
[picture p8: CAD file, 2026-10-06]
BEP2 FräsMaske/BMW_final.dxf
96.9 x 55.0

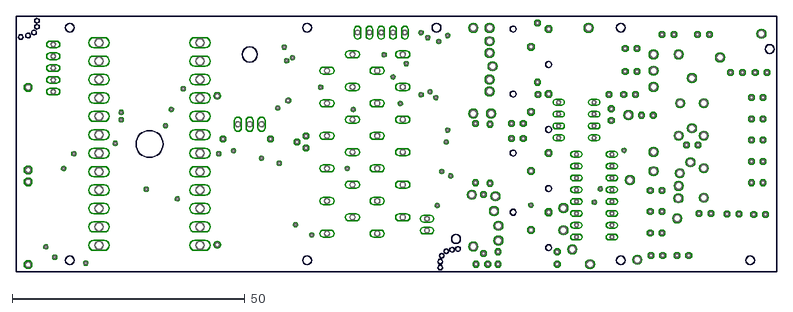
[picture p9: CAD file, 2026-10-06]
BEP2_prototyp_und_testboard/BMW_variante_holesandvias.dxf
163.4 x 55.0

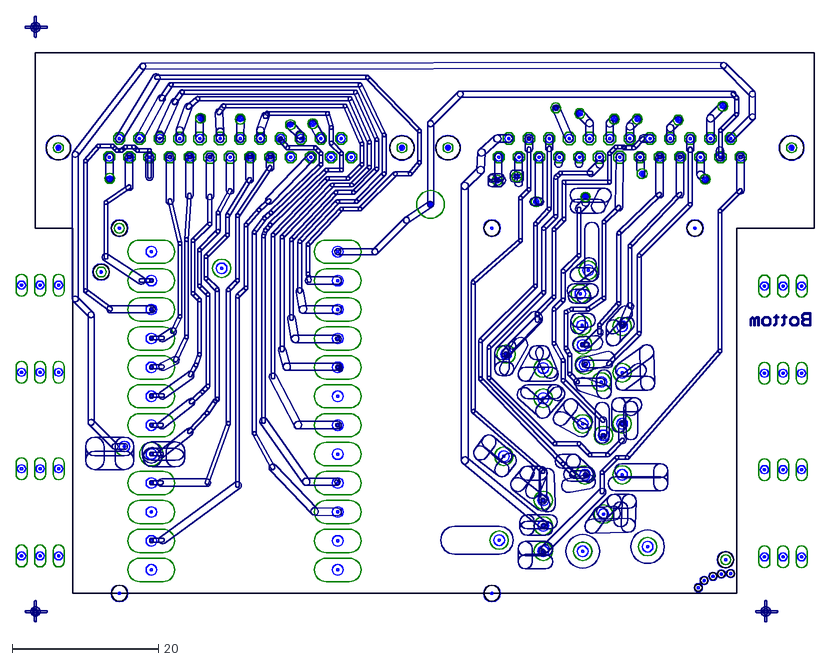
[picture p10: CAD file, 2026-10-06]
BEP3 Test-Interface/BEP31_Test_Interface4_bot.dxf
109.3 x 82.9

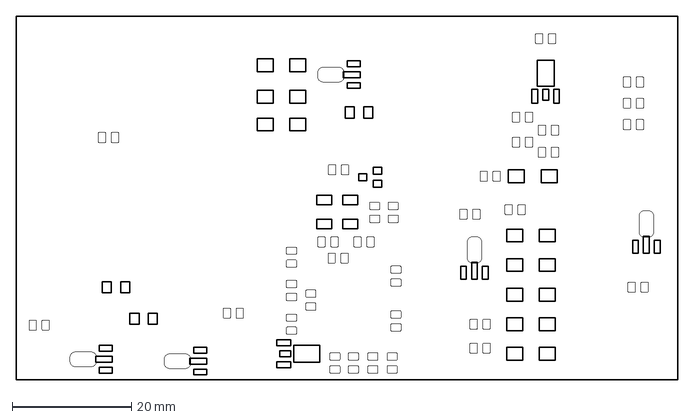
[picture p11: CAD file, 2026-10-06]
BEP3/BEP3 stencil no ICs.dxf
110.8 x 61.0 mm

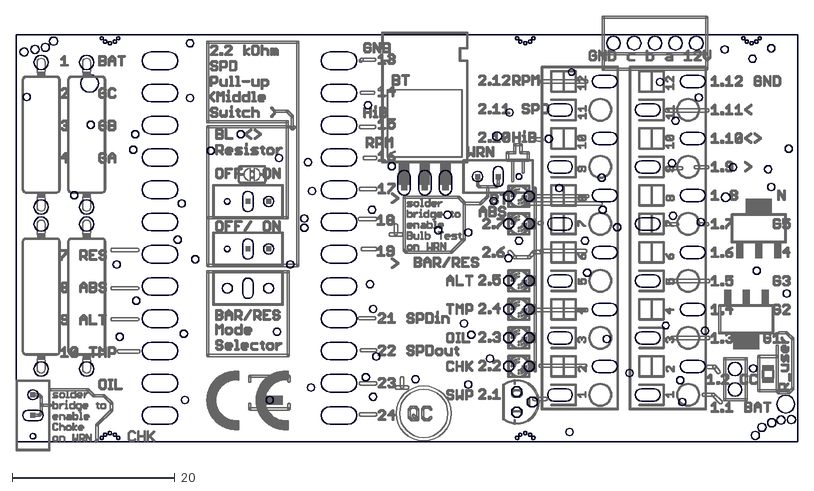
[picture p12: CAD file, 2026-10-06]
BEP31/BEP31_final_top_VorlageHalterung.dxf
96.0 x 53.3

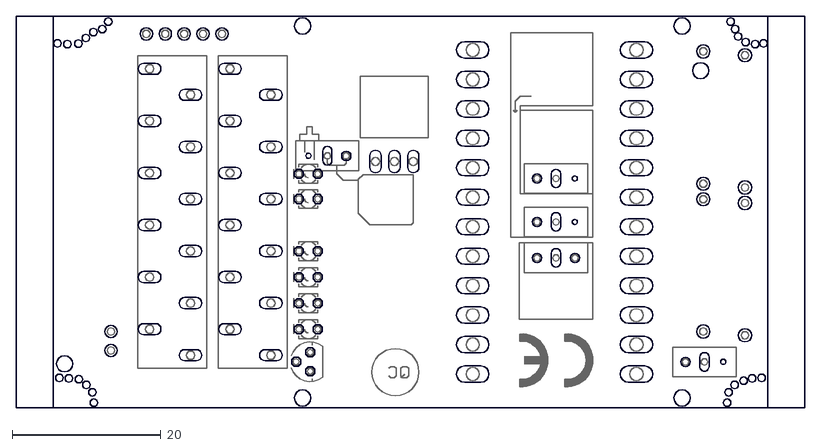
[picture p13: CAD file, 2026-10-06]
BEP32/BEP32_Schalterpositionen.dxf
106.0 x 52.6

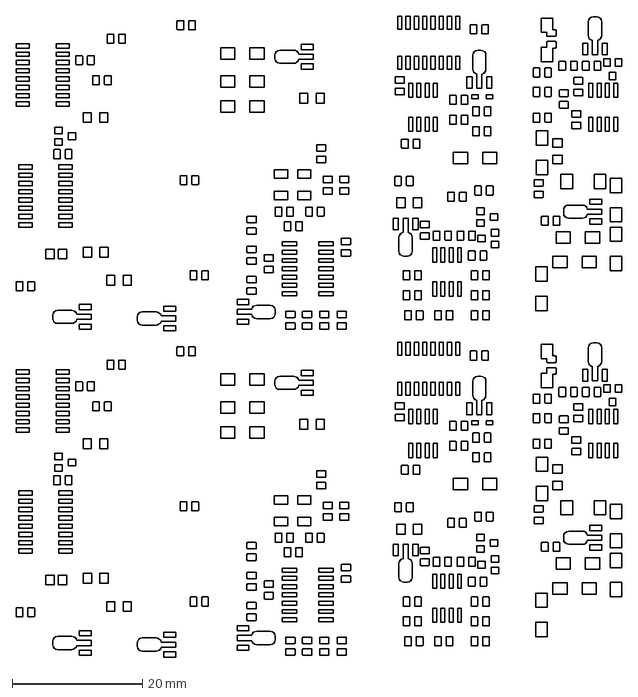
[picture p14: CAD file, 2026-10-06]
BEP33/BEP33_2panel_test_maske_bearb.dxf
92.9 x 98.3 mm

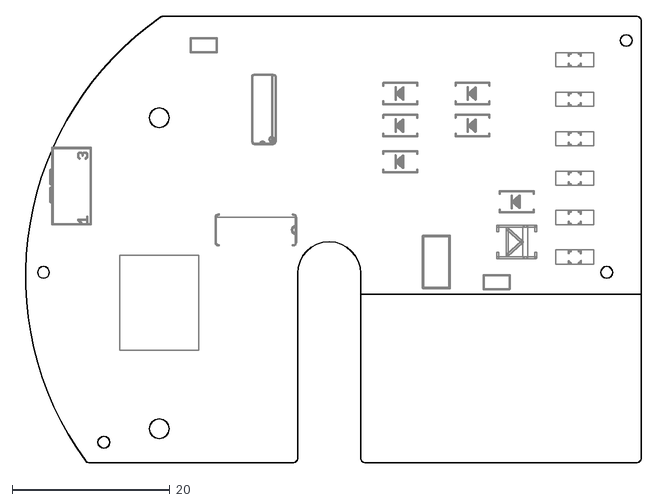
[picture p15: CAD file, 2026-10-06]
Brotbox original/Ganganzeige/Ganganzeige.dxf
79.1 x 56.5

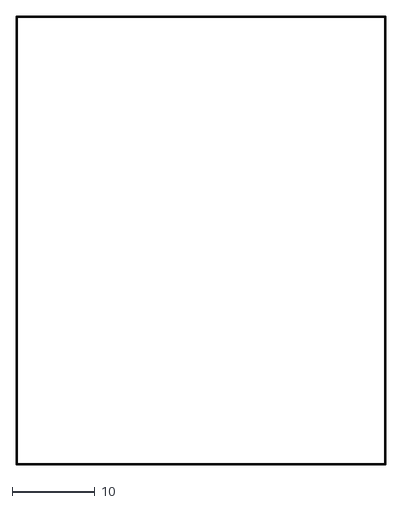
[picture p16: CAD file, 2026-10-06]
Nixie1_kicad/Ganganzeige-Edge_Cuts.dxf
44.6 x 54.1

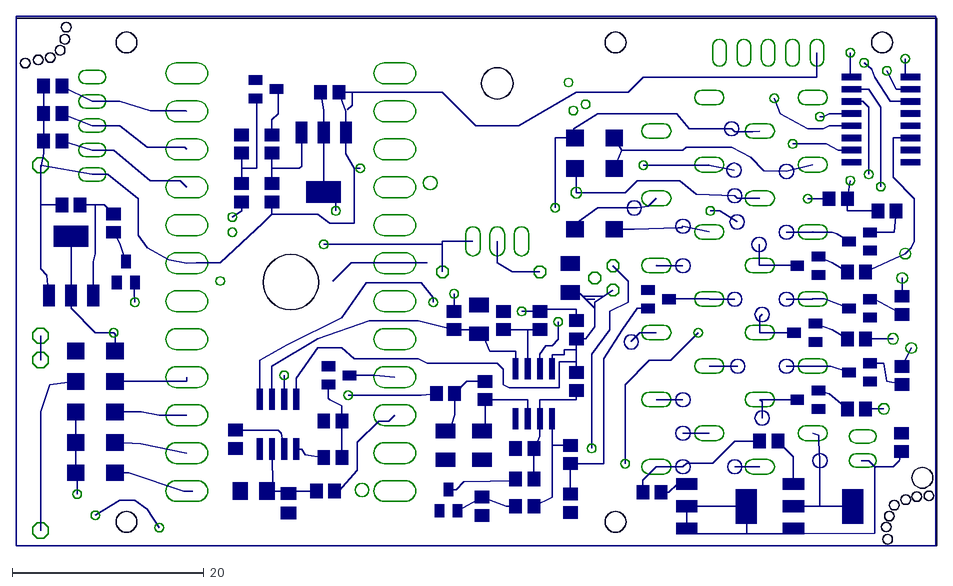
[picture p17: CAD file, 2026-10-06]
BEP2 final/dxf/BMW_final_bottom_ohneLinienbreite.dxf
96.0 x 55.2

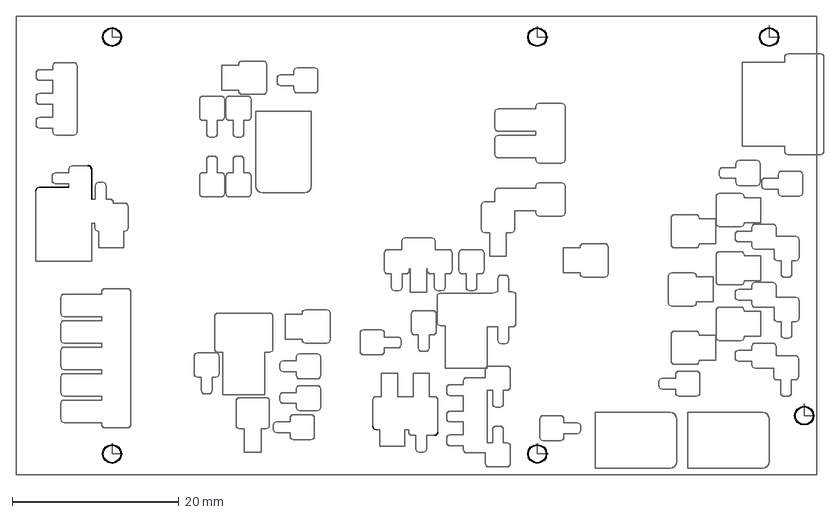
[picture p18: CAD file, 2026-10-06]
BEP2 FräsMaske/BMW_final_bearbeitet.dxf
96.9 x 55.0 mm

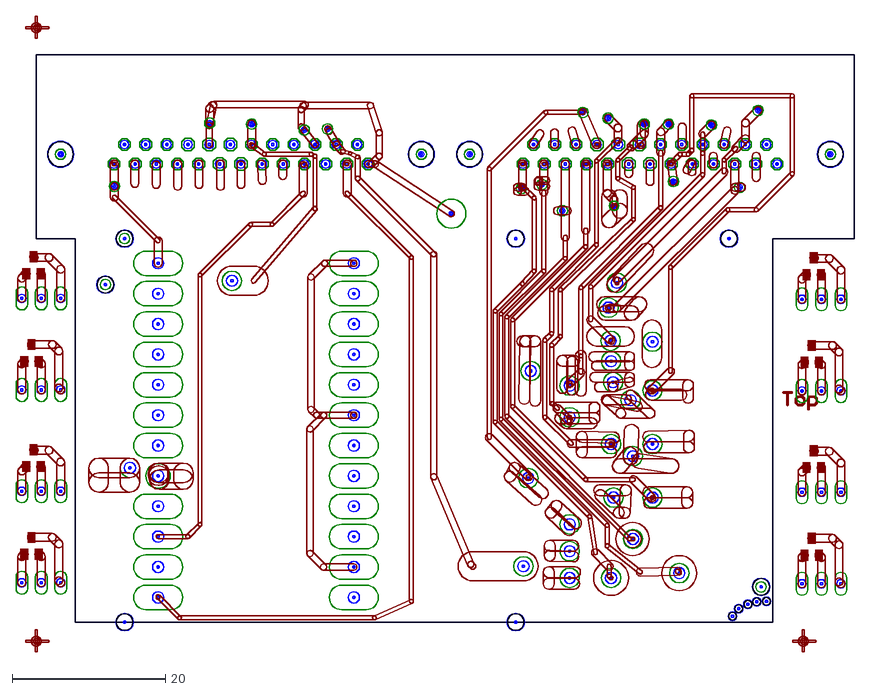
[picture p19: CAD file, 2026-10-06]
BEP3 Test-Interface/BEP31_Test_Interface4_top.dxf
109.3 x 82.9

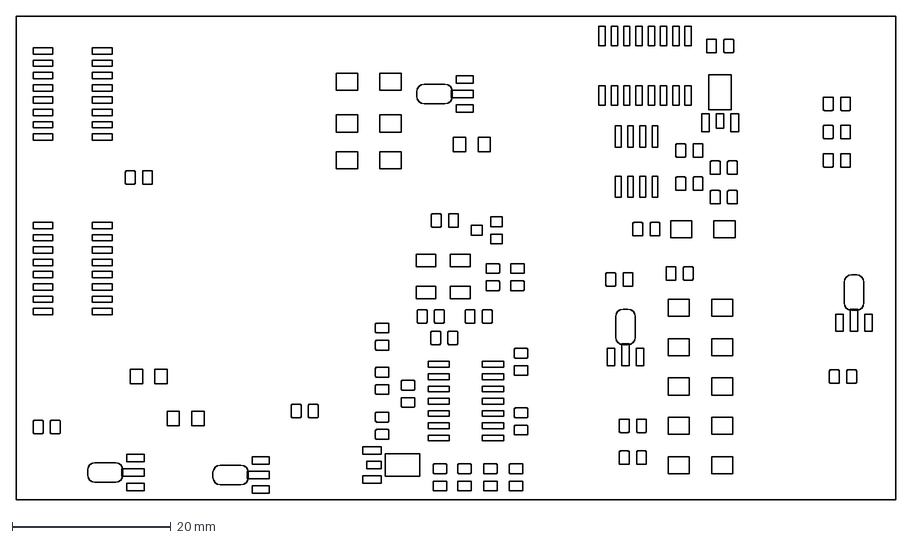
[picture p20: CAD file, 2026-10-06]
BEP3/BEP3 stencil with ICs.dxf
110.8 x 61.0 mm

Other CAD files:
BEP33/BEP33_2panel_test.dxf
Brotbox original/Ganganzeige/Ganganzeige_nutzen_maske.dxf
Nixie1_kicad/Ganganzeige-B_Cu.dxf
BEP2 final/dxf/BMW_final_Bohrlöcher.dxf
BEP2 final/dxf/BMW_final_bottom_MittelpunktederBauteile.dxf
BEP2 final/dxf/BMW_final_bottom_mitLinienbreite.dxf
BEP2 final/dxf/BMW_final_mitLinienbreite.dxf
BEP2 final/dxf/BMW_final_ohneLInienbreite.dxf
BEP2 final/dxf/BMW_final_pads.dxf
BEP2 final/dxf/BMW_final_vias.dxf
BEP2 final/dxf/BMW_final_vias_fläche anstatt drill.dxf
BEP3 Test-Interface/BEP3_Test_Interface2.dxf
BEP3 Test-Interface/BEP3_Test_Interface3.dxf
BEP3/BEP3_RPM_BAR.dxf
BEP33/BEP33_2panel_test_maske.dxf
BEP33/BEP33_2panel_test_plus Ganganzeige_maske_bearb.dxf
BEP33/Ganganzeige_maske_bearb .dxf
Brotbox original/Ganganzeige/Ganganzeige_nutzen_maske_bearb.dxf
Nixie1_kicad/Ganganzeige-B_Mask.dxf
Nixie1_kicad/Ganganzeige-F_Cu.dxf
Nixie1_kicad/Ganganzeige-F_Mask.dxf

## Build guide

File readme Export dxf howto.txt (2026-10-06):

Flächen nicht gefüllt, linienbreite verwenden, so geht der export nach dxf von einer Eagle Vorlage

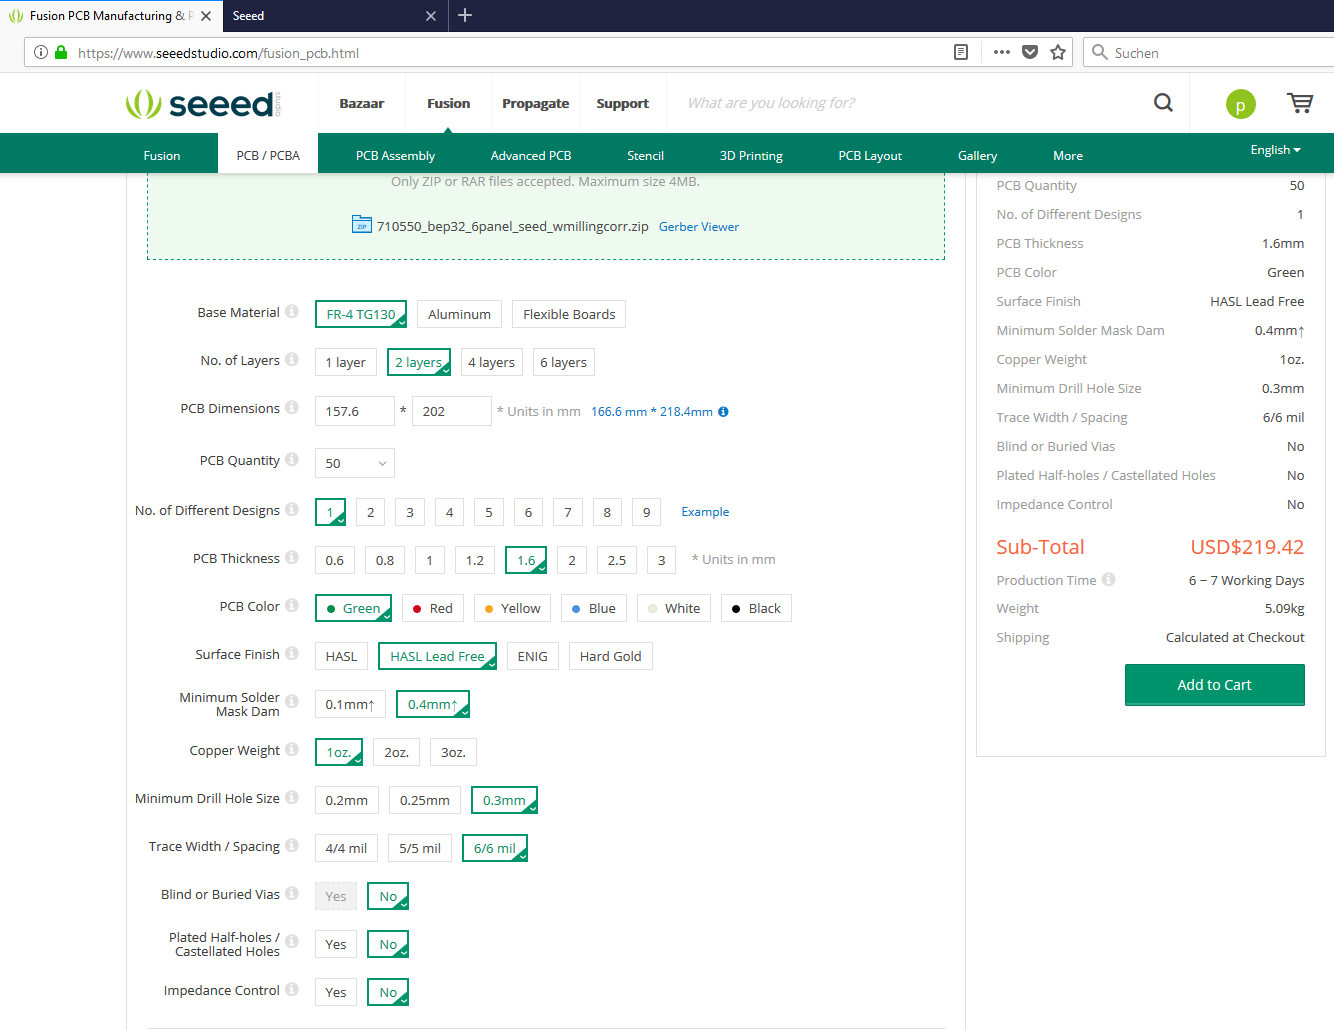
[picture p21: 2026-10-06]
BEP32/BEP32 how to order with seeedstudio.PNG

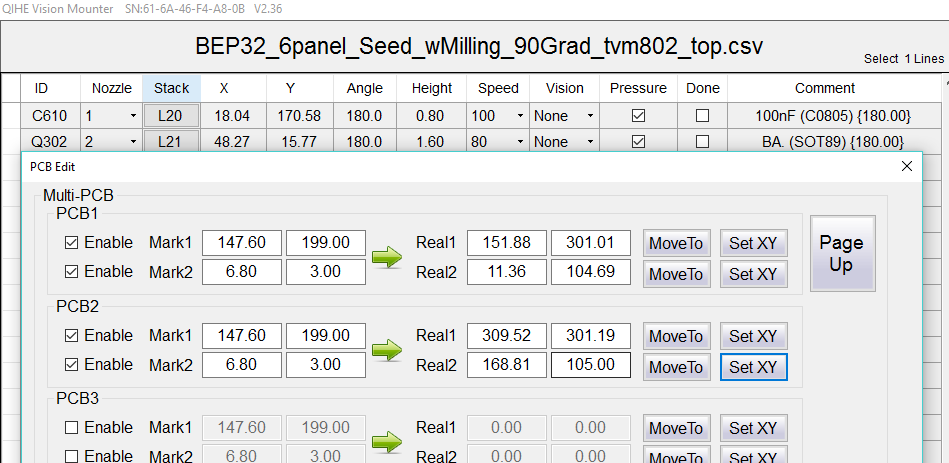
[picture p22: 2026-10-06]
BEP32/BEP32 6 panel Fiducial setup on TVM802B.PNG

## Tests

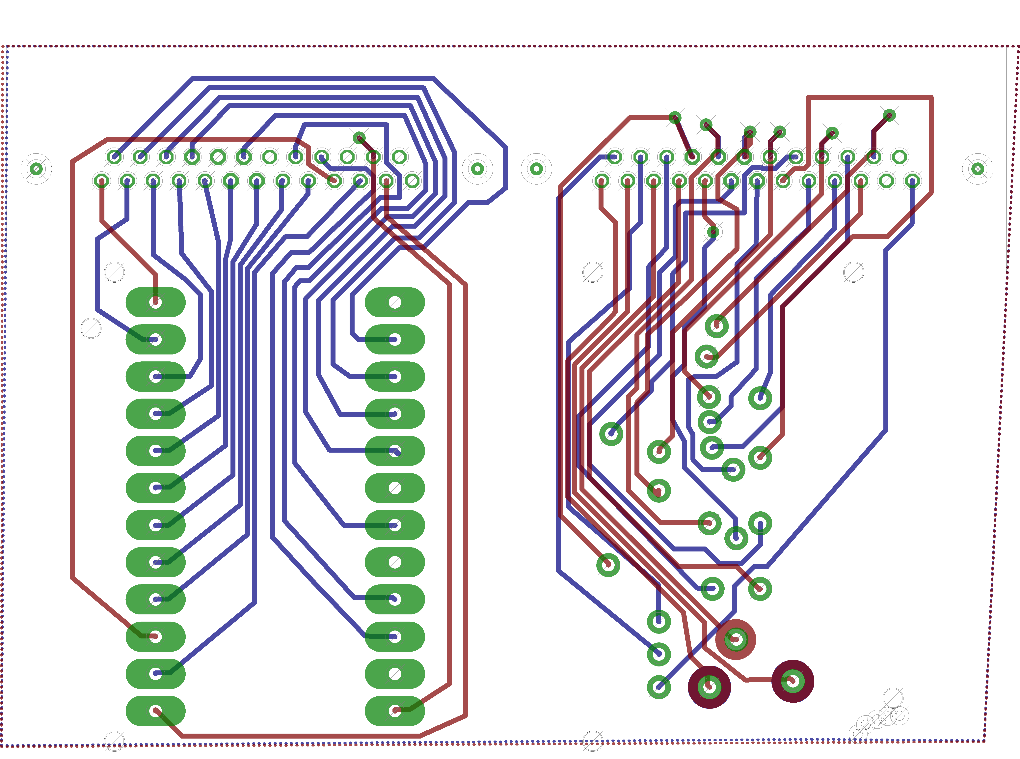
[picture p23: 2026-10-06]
BEP3 Test-Interface/Interface3.png

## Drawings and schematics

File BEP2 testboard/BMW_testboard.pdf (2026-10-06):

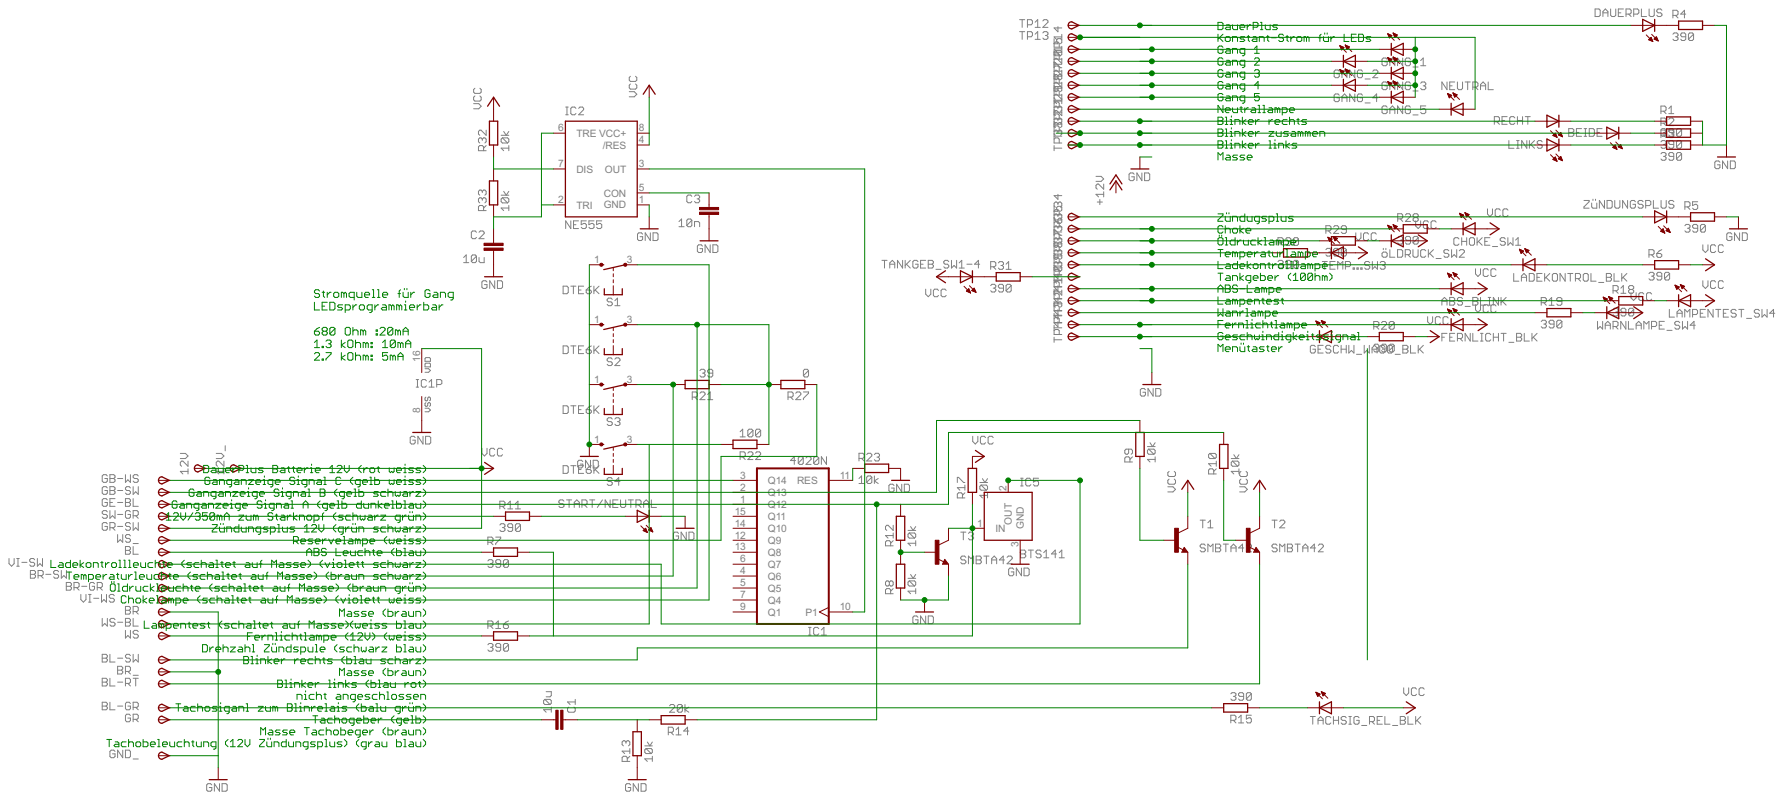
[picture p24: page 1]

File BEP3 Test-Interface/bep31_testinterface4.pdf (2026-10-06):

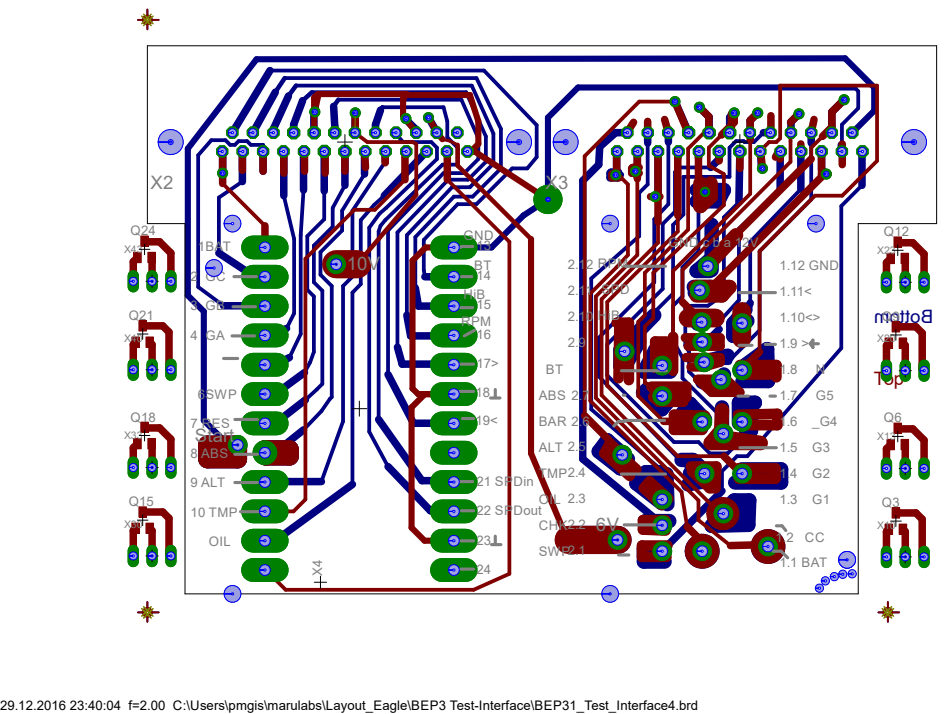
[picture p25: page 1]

29.12.2016 23:40:04 f=2.00 C:\Users\pmgis\marulabs\Layout_Eagle\BEP3 Test-Interface\BEP31_Test_Interface4.brd

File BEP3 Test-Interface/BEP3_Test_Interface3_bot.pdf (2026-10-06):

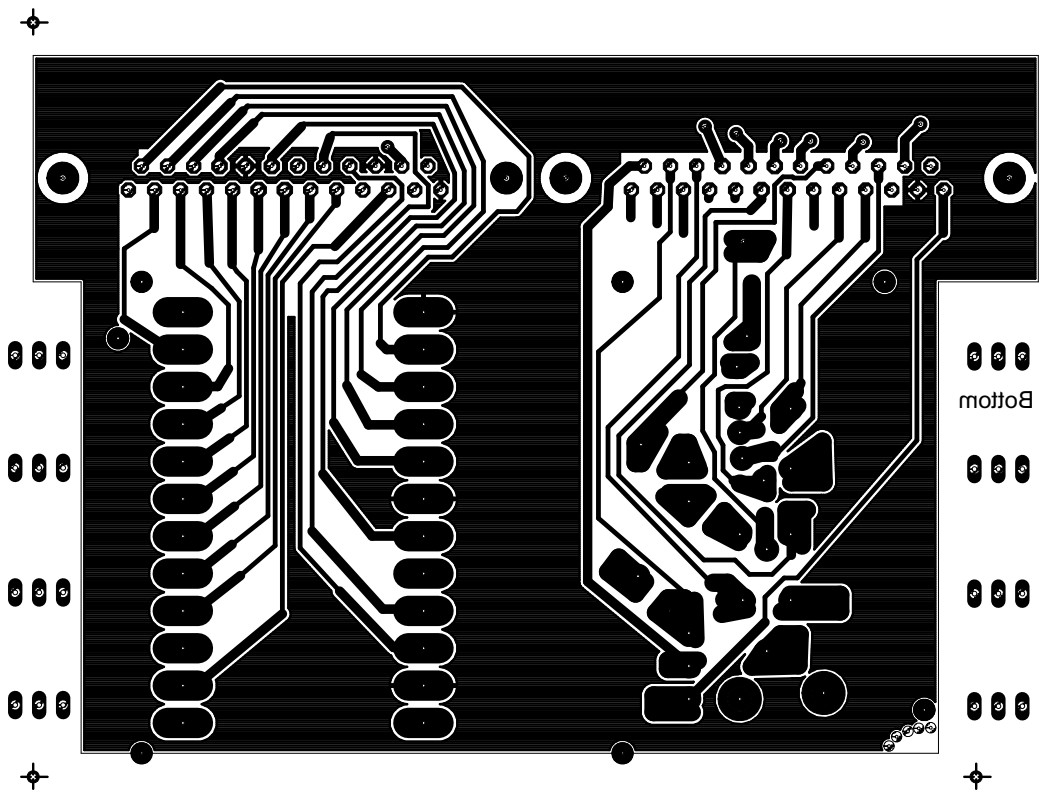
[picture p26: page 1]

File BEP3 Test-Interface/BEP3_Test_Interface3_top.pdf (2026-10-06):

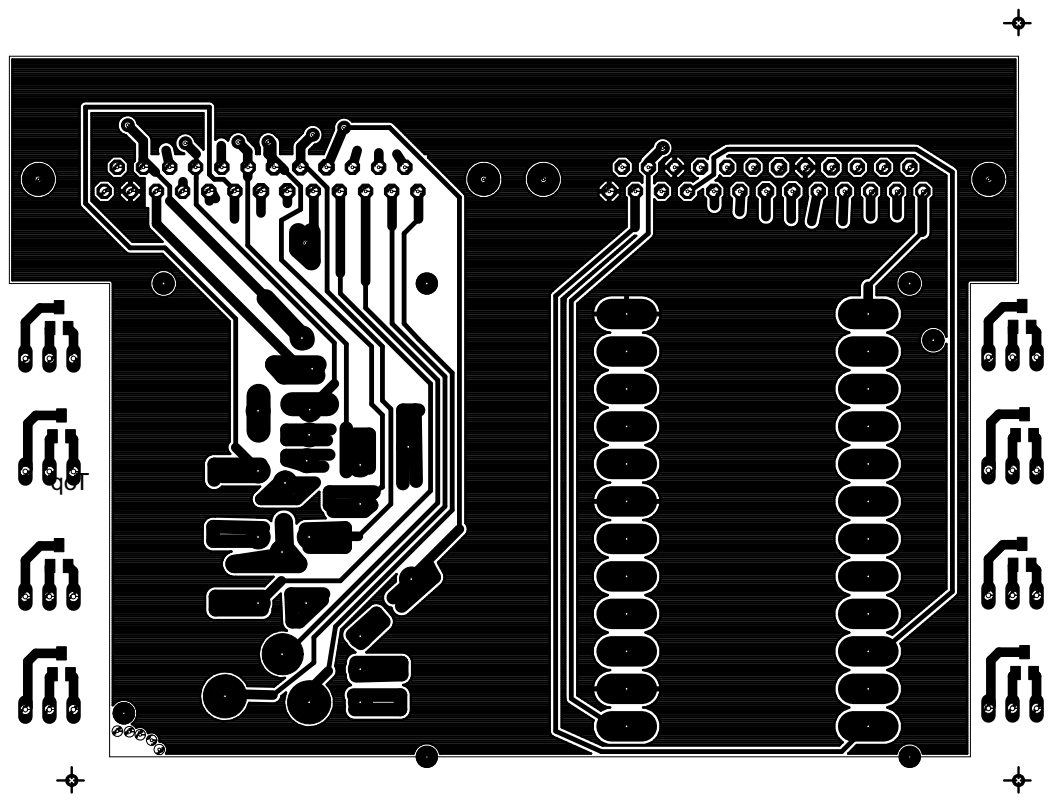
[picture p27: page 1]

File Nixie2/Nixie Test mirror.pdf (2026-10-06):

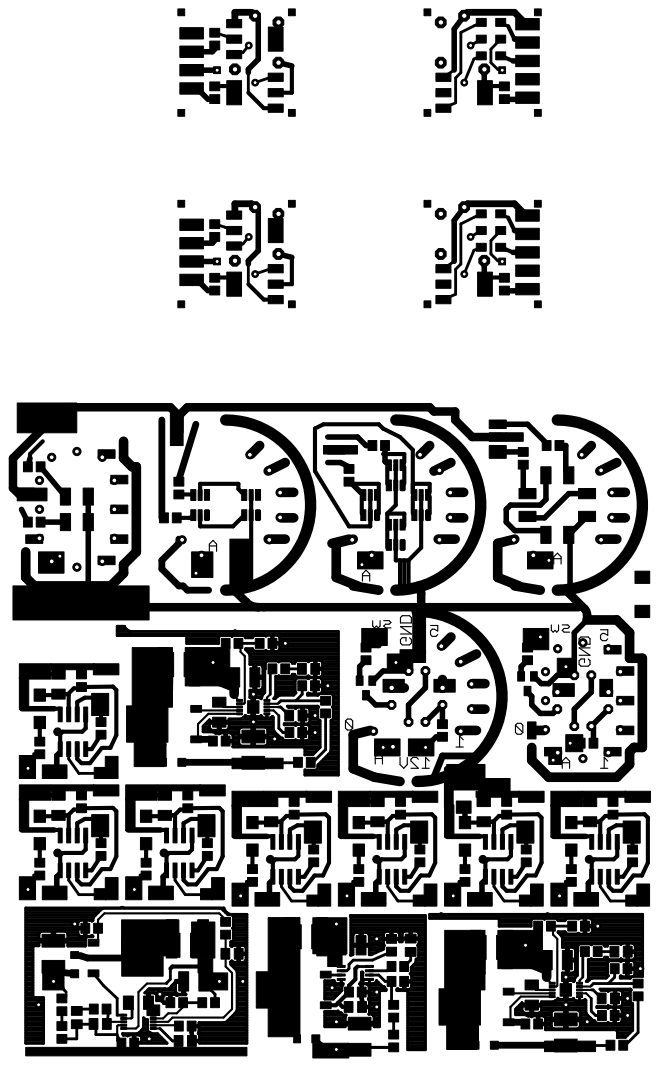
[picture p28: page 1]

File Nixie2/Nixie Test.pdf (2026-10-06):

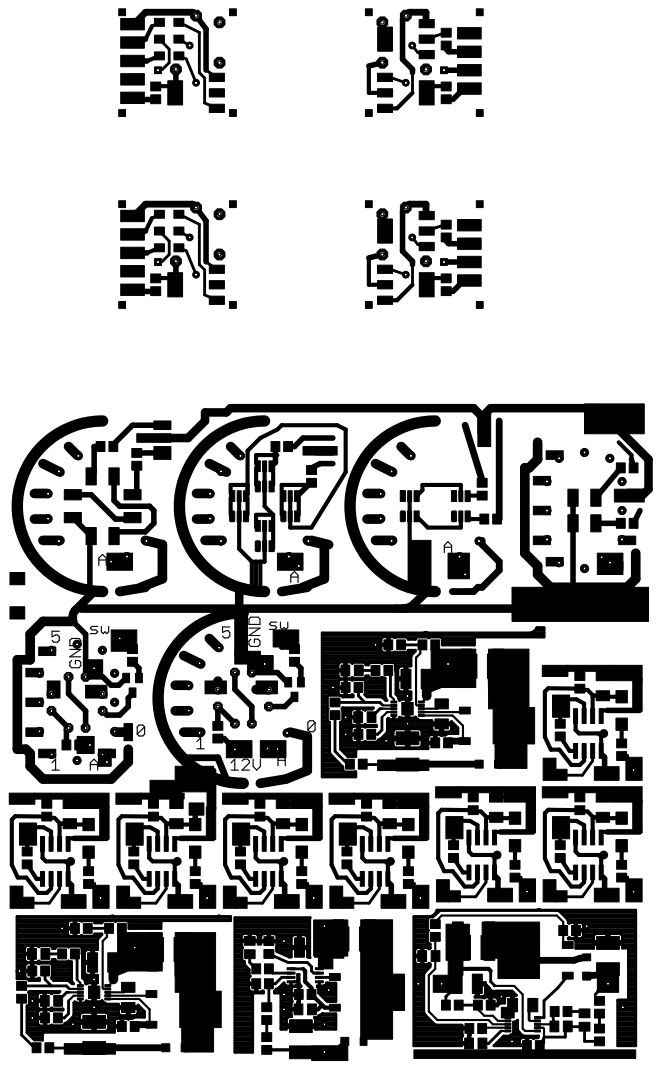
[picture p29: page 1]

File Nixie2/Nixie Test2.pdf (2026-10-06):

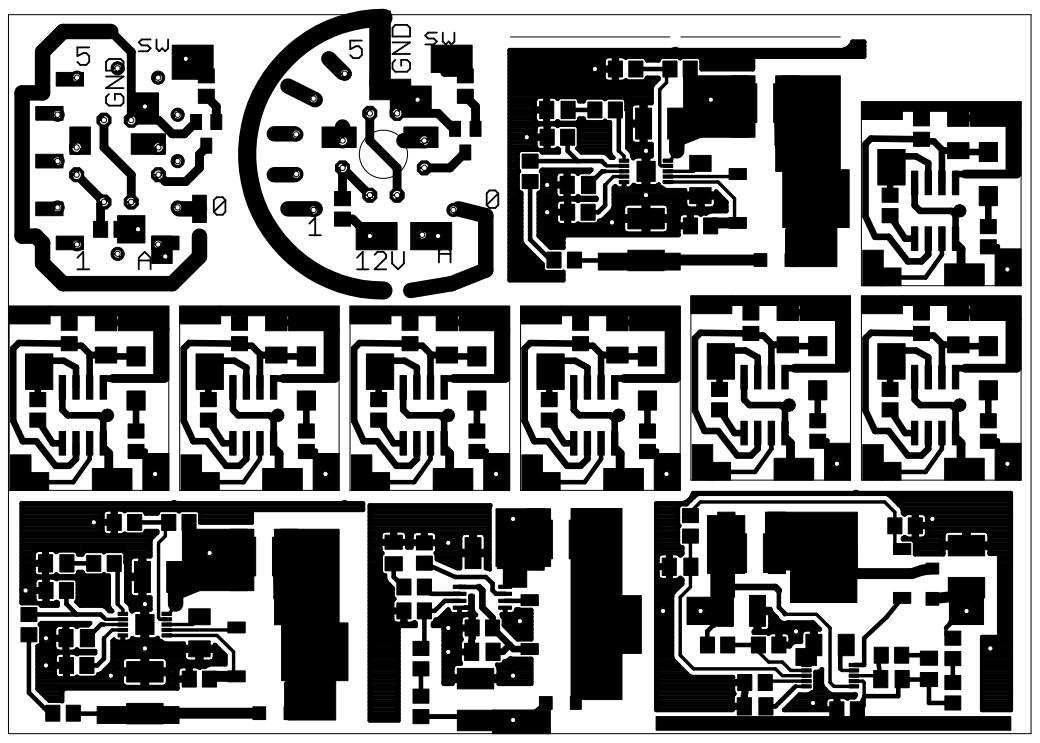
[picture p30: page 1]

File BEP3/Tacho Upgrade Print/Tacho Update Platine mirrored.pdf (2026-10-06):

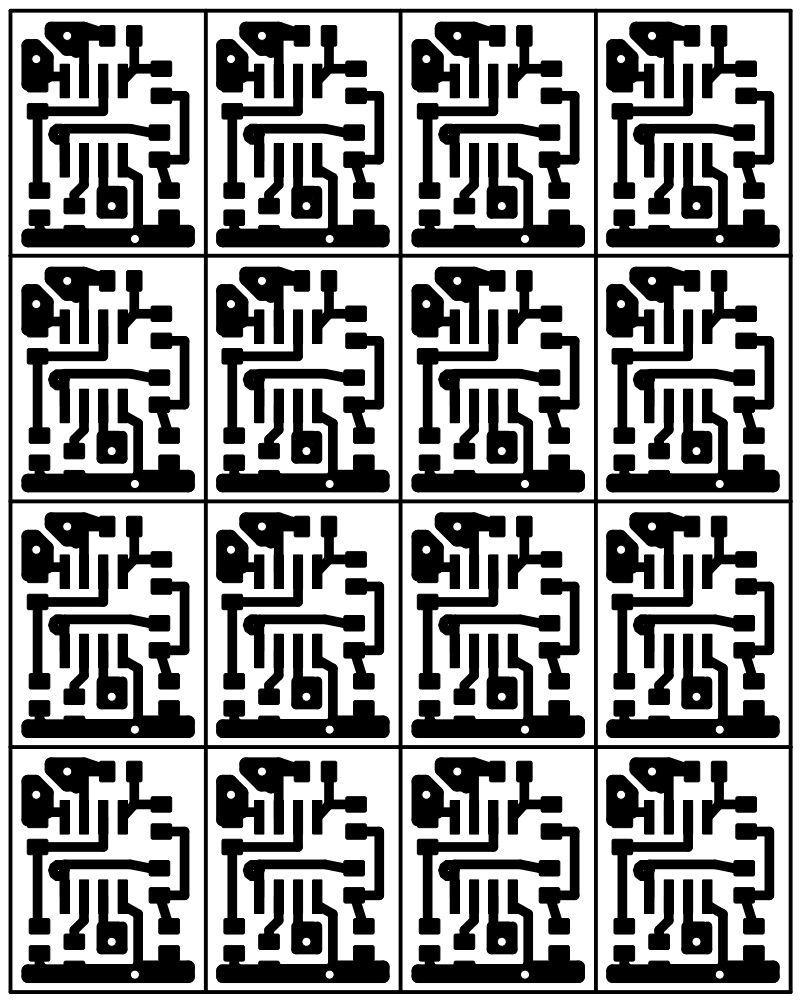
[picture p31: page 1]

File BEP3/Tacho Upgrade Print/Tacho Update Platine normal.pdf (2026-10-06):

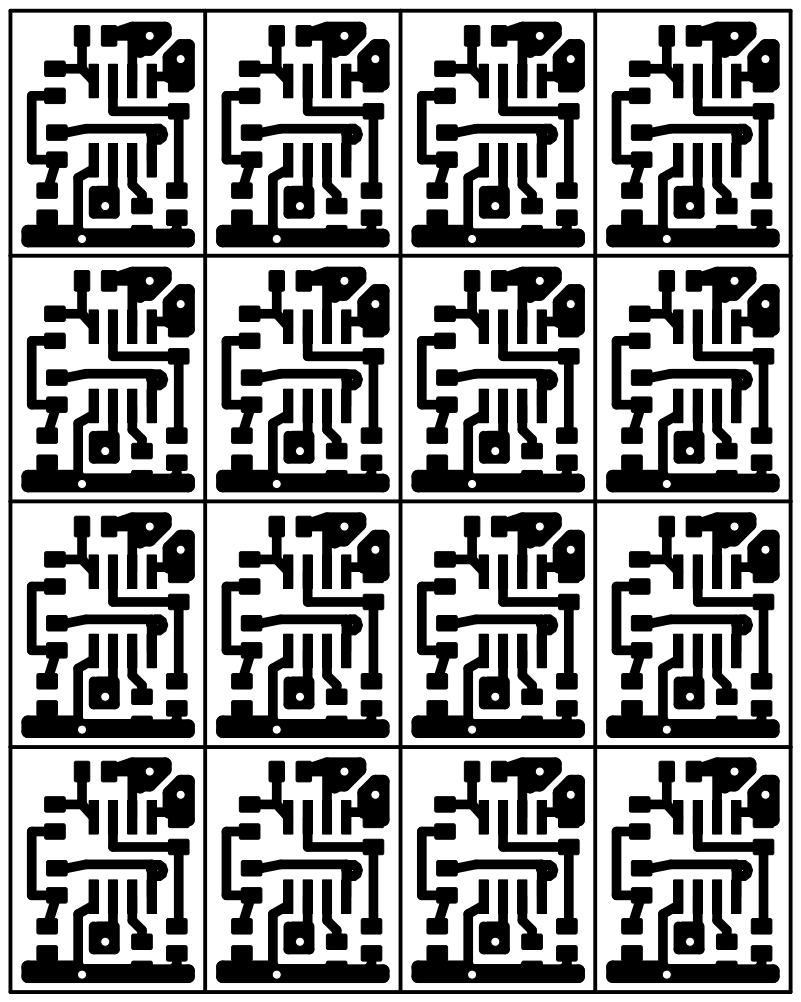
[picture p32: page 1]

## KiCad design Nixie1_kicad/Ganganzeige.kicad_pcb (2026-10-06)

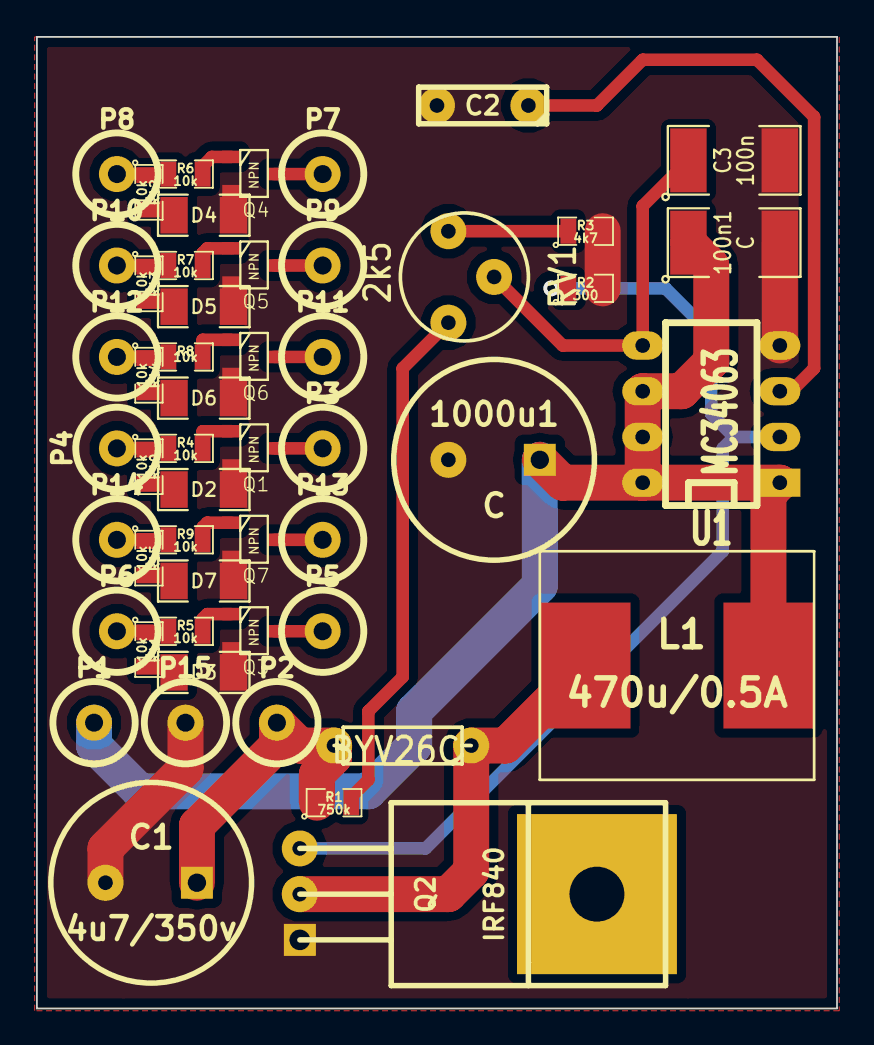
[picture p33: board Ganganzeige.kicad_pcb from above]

Board: 2 copper layers, 44.4 x 54.0 mm, 52 parts (0 on the bottom side), 33 nets.

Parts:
100n1: C; SM1812L
1000u1: C; C2V10
C1: 4u7/350v; C2V10
C2: 1n; C2
C3: 100n; SM1812L
D1: BYV26C; R3
D2, D3, D4, D5, D6, D7: BYV26C; SM1206
L1: 470u/0.5A; BUZZER
P1, P2, P3, P4, P5, P6, P7, P8, P9, P10, P11, P12, P13, P14, P15: CONN_1; 1pin
Q1, Q3, Q4, Q5, Q6, Q7: NPN; SOT23_INV
Q2: IRF840; TO220
R1: 750k; SM0805
R2: 300; SM0805
R3: 4k7; SM0805
R4, R5, R6, R7, R8, R9, R10, R11, R12, R13, R14, R15: 10k; SM0805
RV1: 2k5; RV2
U1: MC34063; DIP-8__300_ELL

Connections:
GND: 100n1.2, 1000u1.2, C1.2, C2.2, C3.2, D2.2, D3.2, D4.2, D5.2, D6.2, D7.2, P15.1, Q1.1, Q2.1, Q3.1, Q4.1, Q5.1, Q6.1, Q7.1, R2.2, R3.2, U1.4
unnamed: R1.2, RV1.3
unnamed: D1.1, L1.1, Q2.3
unnamed: Q2.2, R2.1, U1.2
unnamed: R3.1, RV1.1
unnamed: C2.1, U1.3
unnamed: C3.1, RV1.2, U1.5
unnamed: D6.1, R14.2
unnamed: D4.1, R12.2
unnamed: P10.1, R7.1, R13.1
unnamed: D5.1, R13.2
unnamed: P12.1, R8.1, R14.1
unnamed: P14.1, R9.1, R15.1
unnamed: D7.1, R15.2
unnamed: D2.1, R10.2
unnamed: D3.1, R11.2
unnamed: P8.1, R6.1, R12.1
unnamed: Q1.2, R4.2
unnamed: P6.1, R5.1, R11.1
unnamed: Q3.2, R5.2
unnamed: Q4.2, R6.2
unnamed: Q5.2, R7.2
unnamed: Q6.2, R8.2
unnamed: Q7.2, R9.2
unnamed: P13.1, Q7.3
unnamed: P4.1, R4.1, R10.1
unnamed: P3.1, Q1.3
unnamed: P5.1, Q3.3
unnamed: P7.1, Q4.3
unnamed: P9.1, Q5.3
unnamed: P11.1, Q6.3
unnamed: 100n1.1, 1000u1.1, L1.2, P1.1, U1.1, U1.6, U1.7, U1.8
unnamed: C1.1, D1.2, P2.1, R1.1

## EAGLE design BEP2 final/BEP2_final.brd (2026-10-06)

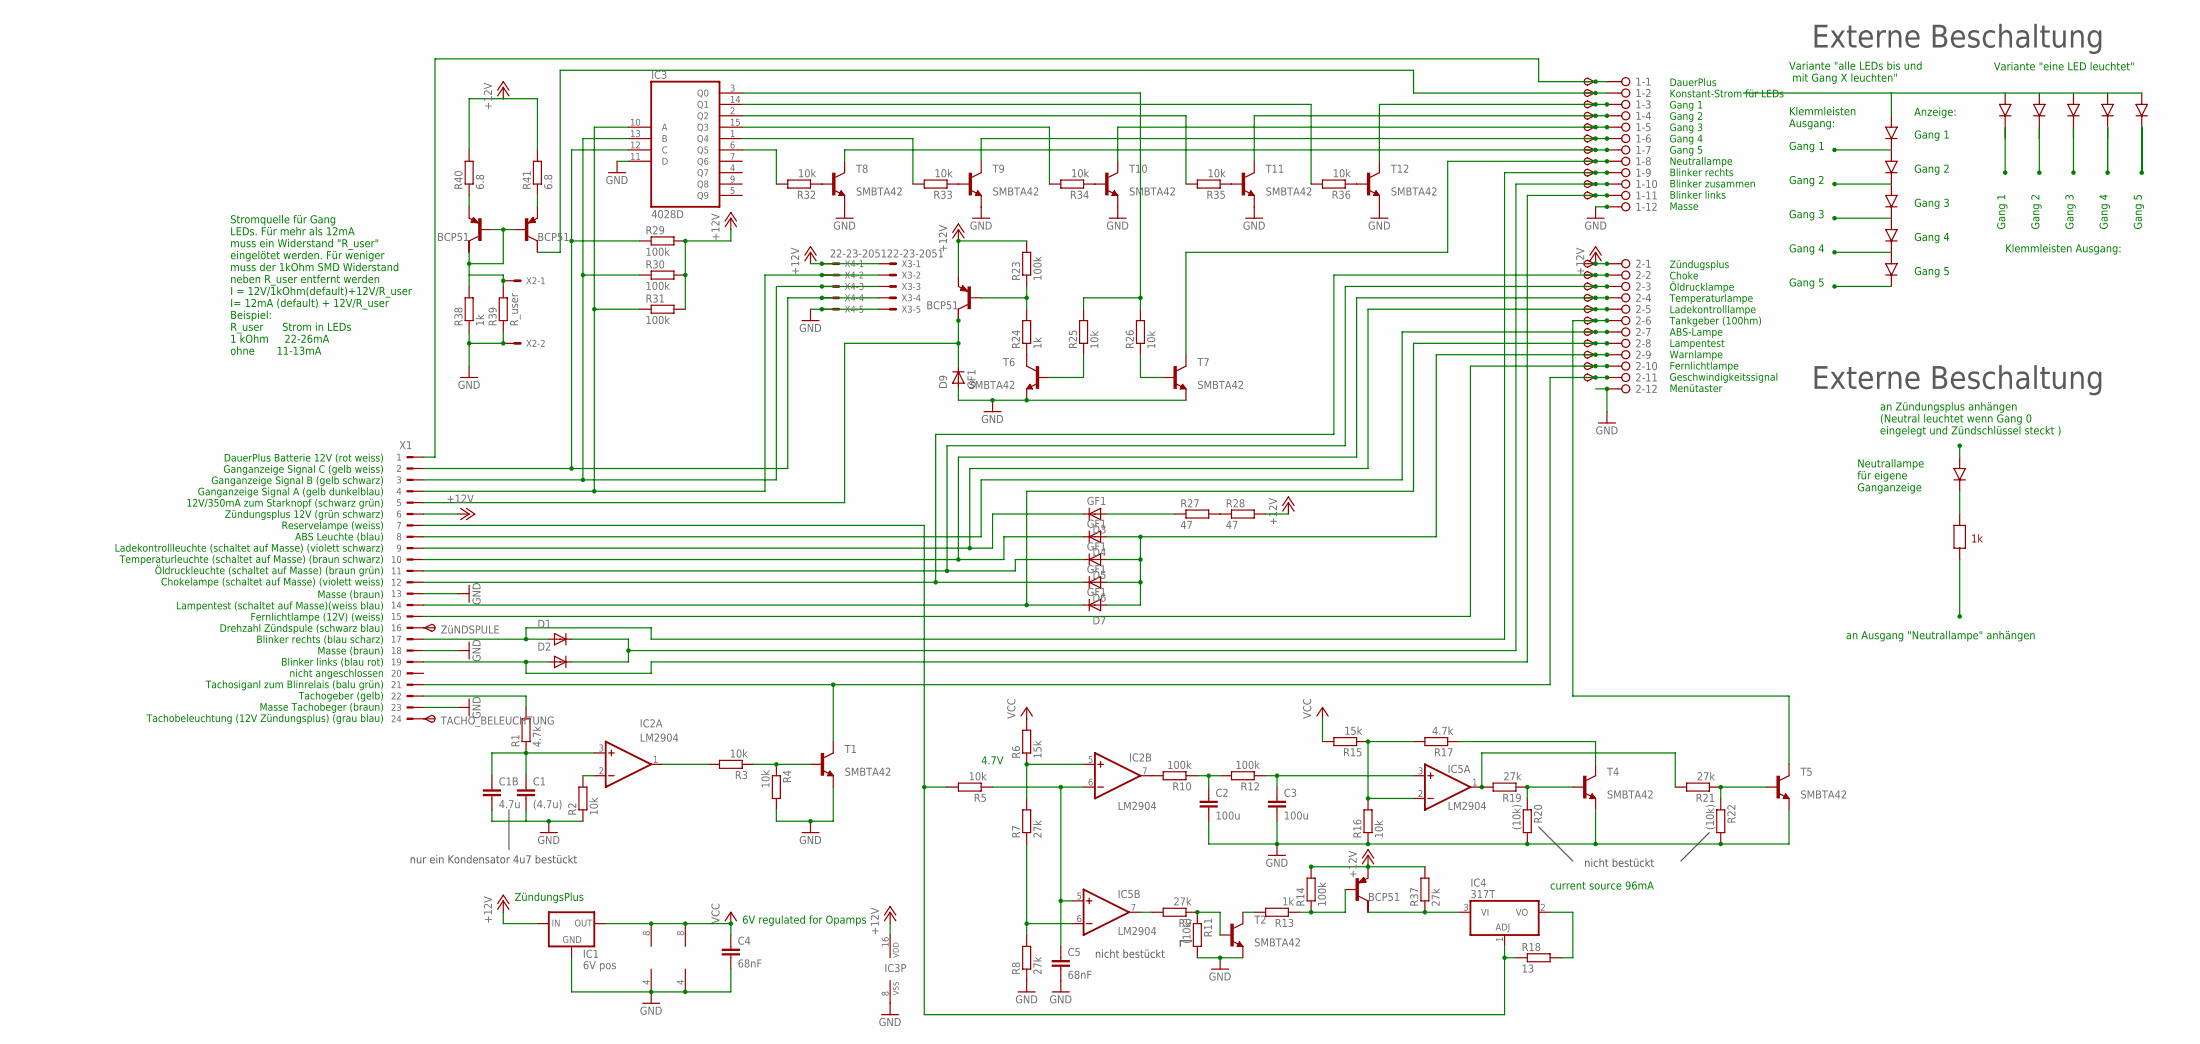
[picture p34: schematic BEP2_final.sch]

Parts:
1, 2: 2081-1132; 12-PIN
C1: (4.7u); C1206
C1B: 4.7u; C0805K
C2, C3: 100u; C1206K
C4, C5: 68nF; C1206K
D1, D2, D3, D4, D5, D6, D7, D9: GF1; SMA-DO214AC
IC1: 6V pos; 78LXX
IC2, IC5: LM2904; SO08
IC3: 4028D; SO16
IC4: 317T; TO220H
R1, R17: 4.7k; R0805
R2, R3, R4, R5, R16, R25, R26, R32, R33, R34, R35, R36: 10k; R0805
R6, R15: 15k; R0805
R7, R8, R9, R19, R21, R37: 27k; R0805
R10, R12, R14, R23, R29, R30, R31: 100k; R0805
R11, R20, R22: (10k); R0805
R13, R24, R38: 1k; R0805
R18: 13; 0207/10
R27, R28: 47; V235/17
R39: R_user; R0805
R40, R41: 6.8; R0805
T, T3, T13, T14: BCP53T1; SOT223
T1, T2, T4, T5, T6, T7, T8, T9, T10, T11, T12: MMBTA42LT1-NPN-SOT23-BEC; SOT23-BEC
TACHO_BELEUCHTUNG: TPSP1_1MM; P1_1.0MM
TP1, TP2, TP3, TP4, TP5, TP6, TP7, TP8, TP9, TP10, TP11, TP12, TP16, TP17, TP18, TP19, TP21, TP22, TP23, TP24, TP25, TP26: TPSB1,27; B1,27
X1: CON_BMW; 24-PIN
X2: 22-23-2021
X3, X4: 22-23-2051
ZüNDSPULE: TPSP1_1MM; P1_1.0MM

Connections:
+12V: 2.1, IC1.IN, IC3.16 (VDD), R14.2, R23.2, R28.2, R29.2, R30.2, R31.2, R37.2, R40.2, R41.2, T.3 (E), T3.3 (E), TP12.TP, X1.6, X3.1, X4.1
GND: 1.12, 2.12, C1.2, C1B.2, C2.2, C3.2, C4.2, C5.2, D9.A, IC1.GND, IC2.4 (V-), IC3.8 (VSS), IC3.11 (D), IC5.4 (V-), R2.1, R4.2, R8.1, R11.2, R16.1, R20.2, R22.2, R38.1, R39.1, T1.E, T2.E, T4.E, T5.E, T6.E, T7.E, T8.E, T9.E, T10.E, T11.E, T12.E, X1.13, X1.18, X1.23, X2.2, X3.5, X4.5
unnamed: 2.9, D4.A, D5.A, D6.A, D7.A, TP24.TP
unnamed: IC3.10 (A), R31.1, X1.4, X3.2, X4.2
unnamed: IC3.13 (B), R30.1, X1.3, X3.3, X4.3
unnamed: 2.7, TP22.TP, X1.8
unnamed: R25.1, T6.B
unnamed: IC3.3 (Q0), R25.2, R26.2
unnamed: R24.1, T6.C
unnamed: R27.2, R28.1
unnamed: R23.1, R24.2, T.1 (B)
unnamed: R26.1, T7.B
unnamed: D9.K (C), T.2 (C), X1.5
unnamed: 2.2, D6.K (C), TP16.TP, X1.12
unnamed: 2.3, D5.K (C), TP17.TP, X1.11
unnamed: 2.4, D4.K (C), TP18.TP, X1.10
unnamed: IC4.1 (ADJ), R5.2, R18.1, X1.7
unnamed: C5.1, IC2.6 (-IN), IC5.5 (+IN), R5.1
unnamed: IC3.12 (C), R29.1, X1.2, X3.4, X4.4
unnamed: R32.1, T8.B
unnamed: 2.8, D7.K (C), TP23.TP, X1.14
unnamed: 1.9, D1.A, TP9.TP, X1.17
unnamed: 1.11, D2.A, TP11.TP, X1.19
unnamed: 1.10, D1.K (C), D2.K (C), TP10.TP
unnamed: R1.2, X1.22
unnamed: C1.1, C1B.1, IC2.3 (+IN), R1.1
unnamed: IC2.2 (-IN), R2.2
unnamed: 2.11, T1.C, TP26.TP, X1.21
unnamed: IC2.1 (OUT), R3.2
unnamed: R3.1, R4.1, T1.B
unnamed: IC4.2 (VO), R18.2
unnamed: IC5.6 (-IN), R7.1, R8.2
unnamed: IC5.7 (OUT), R9.2
unnamed: R13.2, T2.C
unnamed: R9.1, R11.1, T2.B
unnamed: IC4.3 (VI), R37.1, T3.2 (C)
unnamed: R13.1, R14.1, T3.1 (B)
unnamed: IC3.14 (Q1), R36.2
unnamed: IC3.2 (Q2), R35.2
unnamed: 1.5, T10.C, TP5.TP
unnamed: IC2.5 (+IN), R6.1, R7.2
unnamed: IC2.7 (OUT), R10.2
unnamed: X1.16, ZüNDSPULE.TP
unnamed: IC5.1 (OUT), R19.2, R21.2
unnamed: R19.1, R20.1, T4.B
unnamed: C2.1, R10.1, R12.2
unnamed: C3.1, IC5.3 (+IN), R12.1
unnamed: IC5.2 (-IN), R15.1, R16.2, R17.2
unnamed: R21.1, R22.1, T5.B
unnamed: R17.1, T4.C
unnamed: 1.6, T9.C, TP6.TP
unnamed: R34.1, T10.B
unnamed: 1.8, T7.C, TP8.TP
unnamed: 2.10, TP25.TP, X1.15
unnamed: D3.A, R27.1
unnamed: 2.5, D3.K (C), TP19.TP, X1.9
unnamed: R33.1, T9.B
unnamed: R35.1, T11.B
unnamed: TACHO_BELEUCHTUNG.TP, X1.24
unnamed: 1.2, T14.2 (C), TP2.TP
unnamed: 2.6, T5.C, TP21.TP
unnamed: IC3.6 (Q5), R32.2
unnamed: R36.1, T12.B
unnamed: 1.7, T8.C, TP7.TP
unnamed: IC3.1 (Q4), R33.2
unnamed: IC3.15 (Q3), R34.2
unnamed: 1.4, T11.C, TP4.TP
unnamed: 1.3, T12.C, TP3.TP
unnamed: R38.2, R39.2, T13.1 (B), T13.2 (C), T14.1 (B), X2.1
unnamed: 1.1, TP1.TP, X1.1
unnamed: R40.1, T13.3 (E)
unnamed: R41.1, T14.3 (E)
VCC: C4.1, IC1.OUT, IC2.8 (V+), IC5.8 (V+), R6.2, R15.2

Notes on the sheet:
6V regulated for Opamps
current source 96mA
ZündungsPlus
Zündugsplus Choke Öldrucklampe Temperaturlampe Ladekontrolllampe Tankgeber (100hm) ABS-Lampe Lampentest Warnlampe Fernlichtlampe Geschwindigkeitssignal Menütaster
DauerPlus Konstant-Strom für LEDs Gang 1 Gang 2 Gang 3 Gang 4 Gang 5 Neutrallampe Blinker rechts Blinker zusammen Blinker links Masse
DauerPlus Batterie 12V (rot weiss) Ganganzeige Signal C (gelb weiss) Ganganzeige Signal B (gelb schwarz) Ganganzeige Signal A (gelb dunkelblau) 12V/350mA zum Starknopf (schwarz grün) Zündungsplus 12V (grün schwarz) Reservelampe (weiss) ABS Leuchte (blau) Ladekontrollleuchte (schaltet auf Masse) (vi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
Masse (braun) Lampentest (schaltet auf Masse)(weiss blau) Fernlichtlampe (12V) (weiss) Drehzahl Zündspule (schwarz blau) Blinker rechts (blau scharz) Masse (braun) Blinker links (blau rot) nicht angeschlossen Tachosiganl zum Blinrelais (balu grün) Tachogeber (gelb) Masse Tachobeger (braun) Tachobel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
4.7V
Stromquelle für Gang LEDs. Für mehr als 12mA muss ein Widerstand "R_user" eingelötet werden. Für weniger muss der 1kOhm SMD Widerstand neben R_user entfernt werden I = 12V/1kOhm(default)+12V/R_user I= 12mA (default) + 12V/R_user Beispiel: R_user Strom in LEDs 1 kOhm 22-26mA ohne 11-13mA
Gang 1
Gang 2
Gang 3
Gang 4
Gang 5
Variante "eine LED leuchtet"
Variante "alle LEDs bis und mit Gang X leuchten"
Klemmleisten Ausgang:
Klemmleisten Ausgang:
an Zündungsplus anhängen (Neutral leuchtet wenn Gang 0 eingelegt und Zündschlüssel steckt )
an Ausgang "Neutrallampe" anhängen
Neutrallampe für eigene Ganganzeige
Externe Beschaltung
Anzeige:
nicht bestückt
nur ein Kondensator 4u7 bestückt

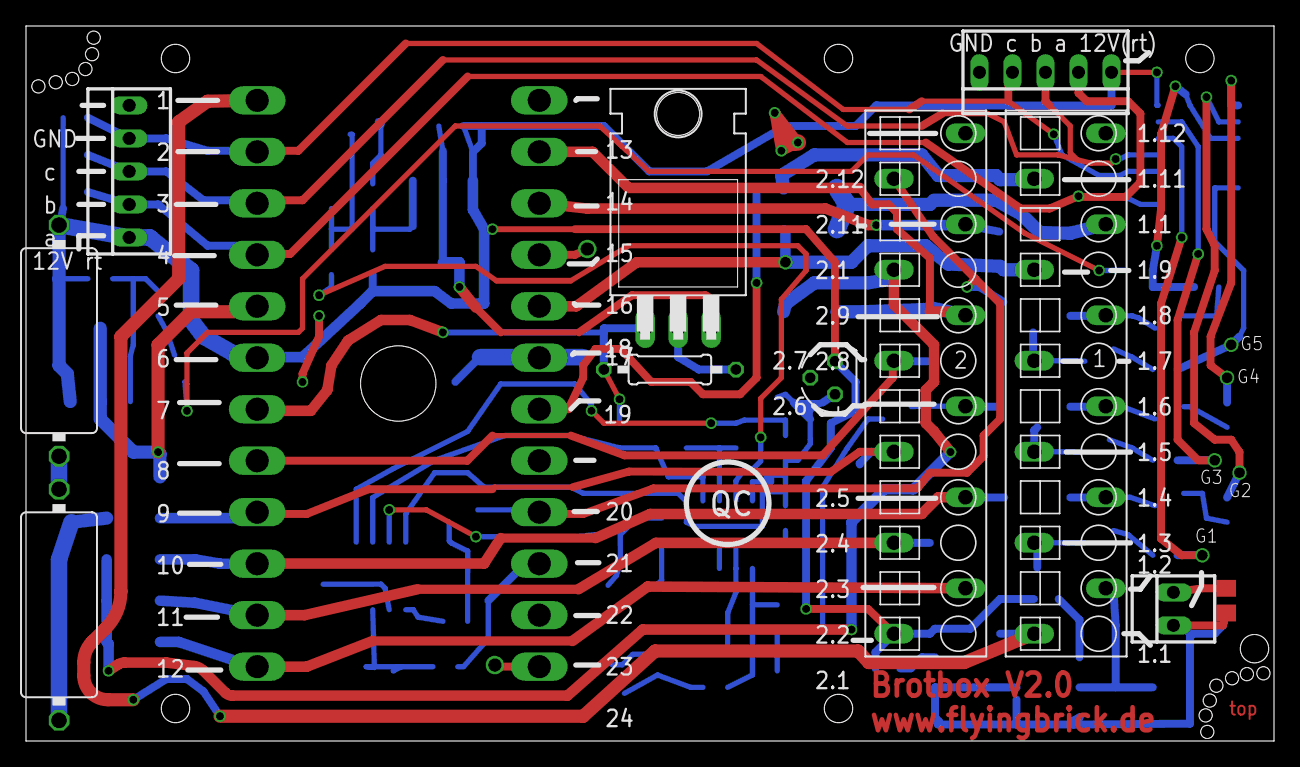
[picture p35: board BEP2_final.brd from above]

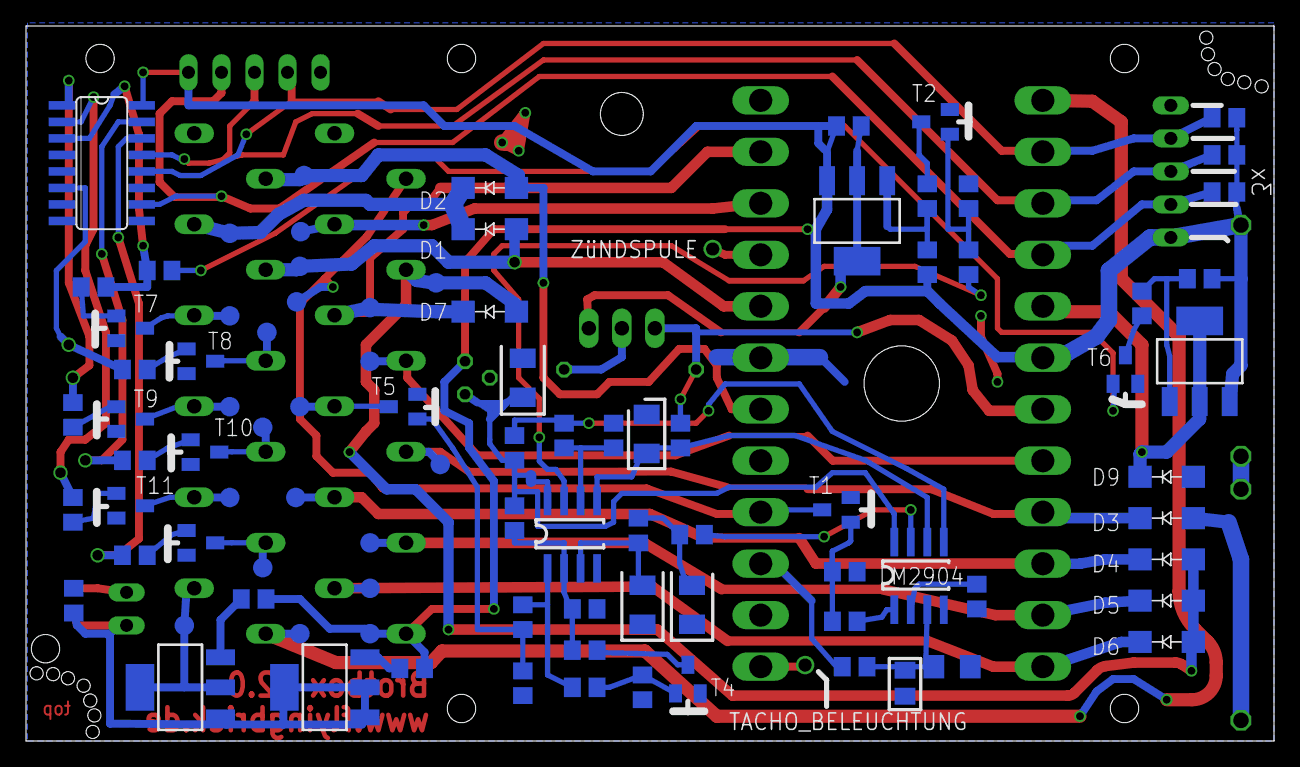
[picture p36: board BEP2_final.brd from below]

Board: 2 copper layers, 96.0 x 55.0 mm, 105 parts (93 on the bottom side), 73 nets.

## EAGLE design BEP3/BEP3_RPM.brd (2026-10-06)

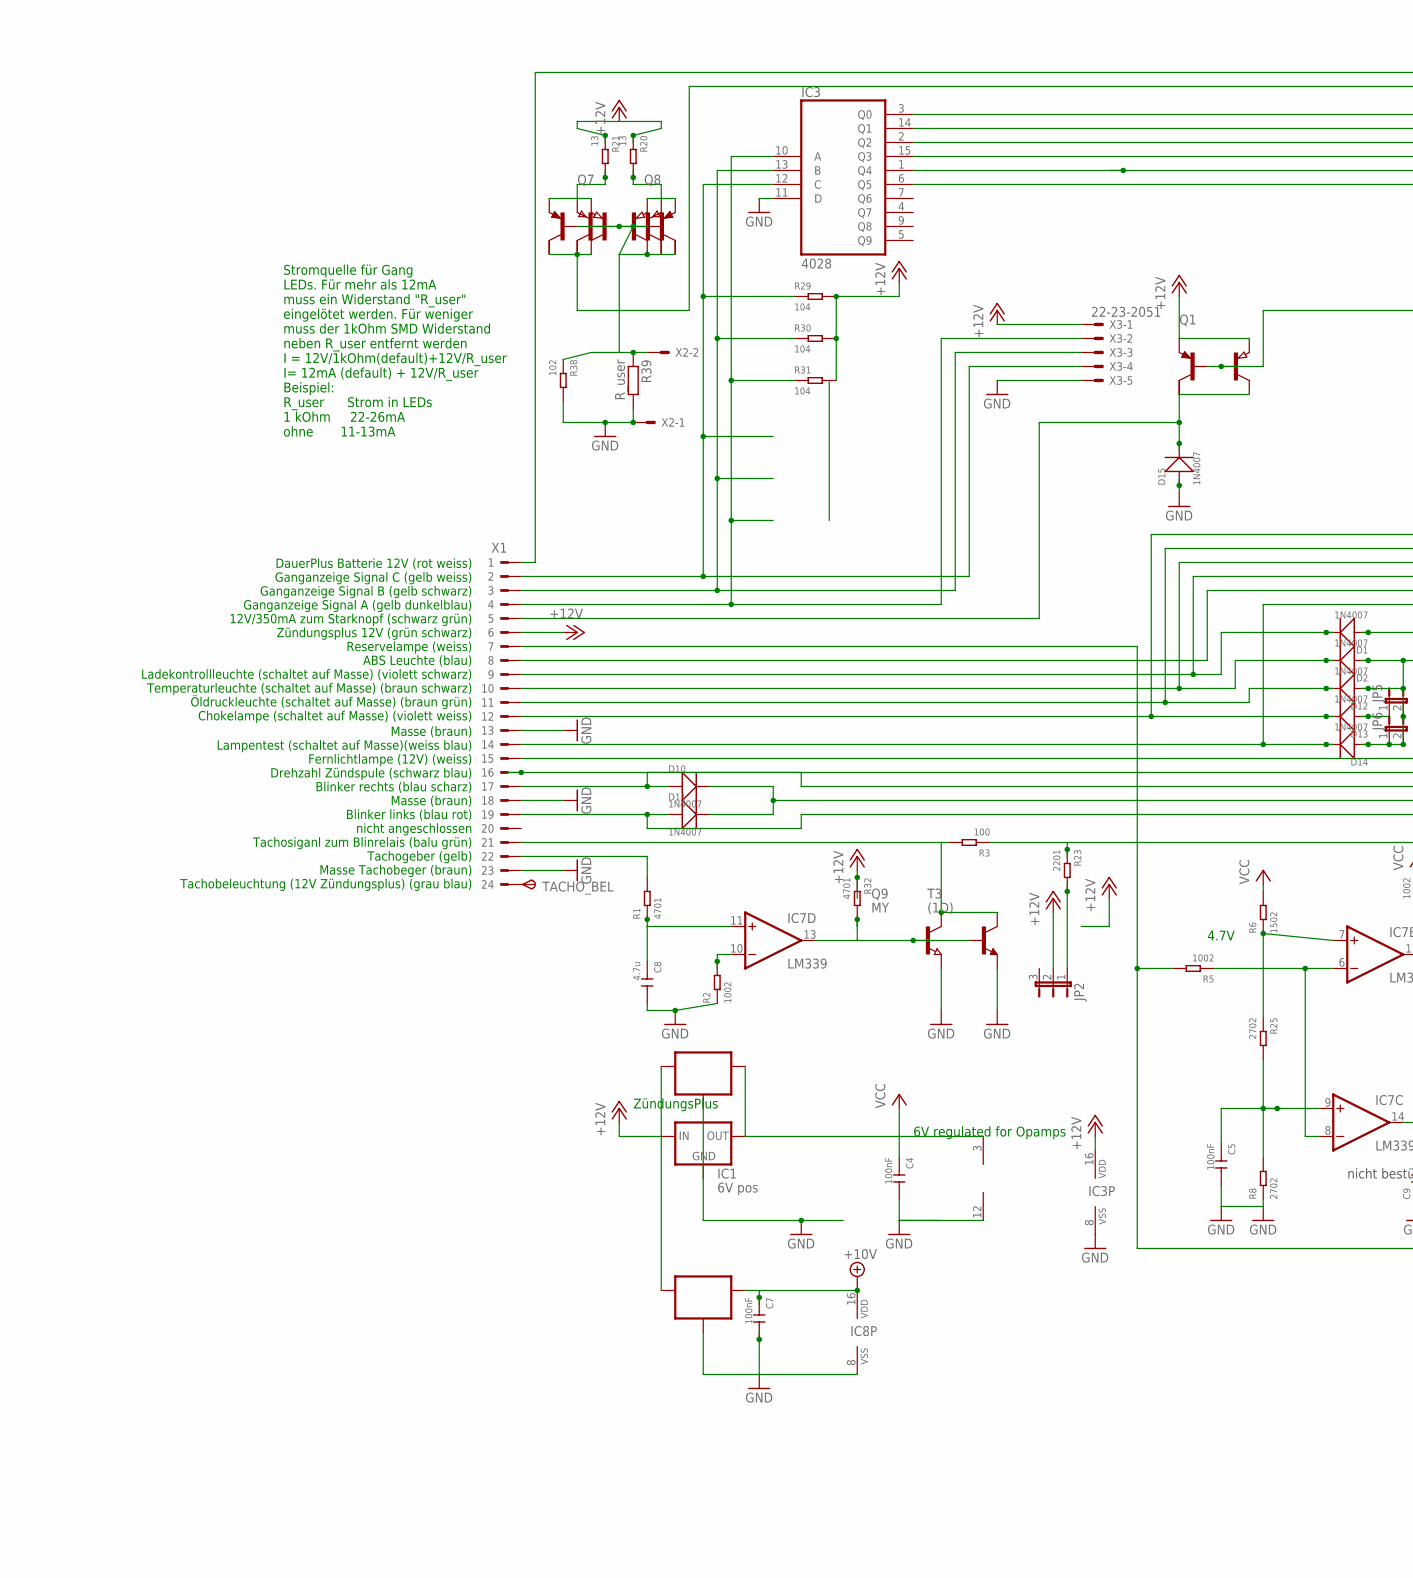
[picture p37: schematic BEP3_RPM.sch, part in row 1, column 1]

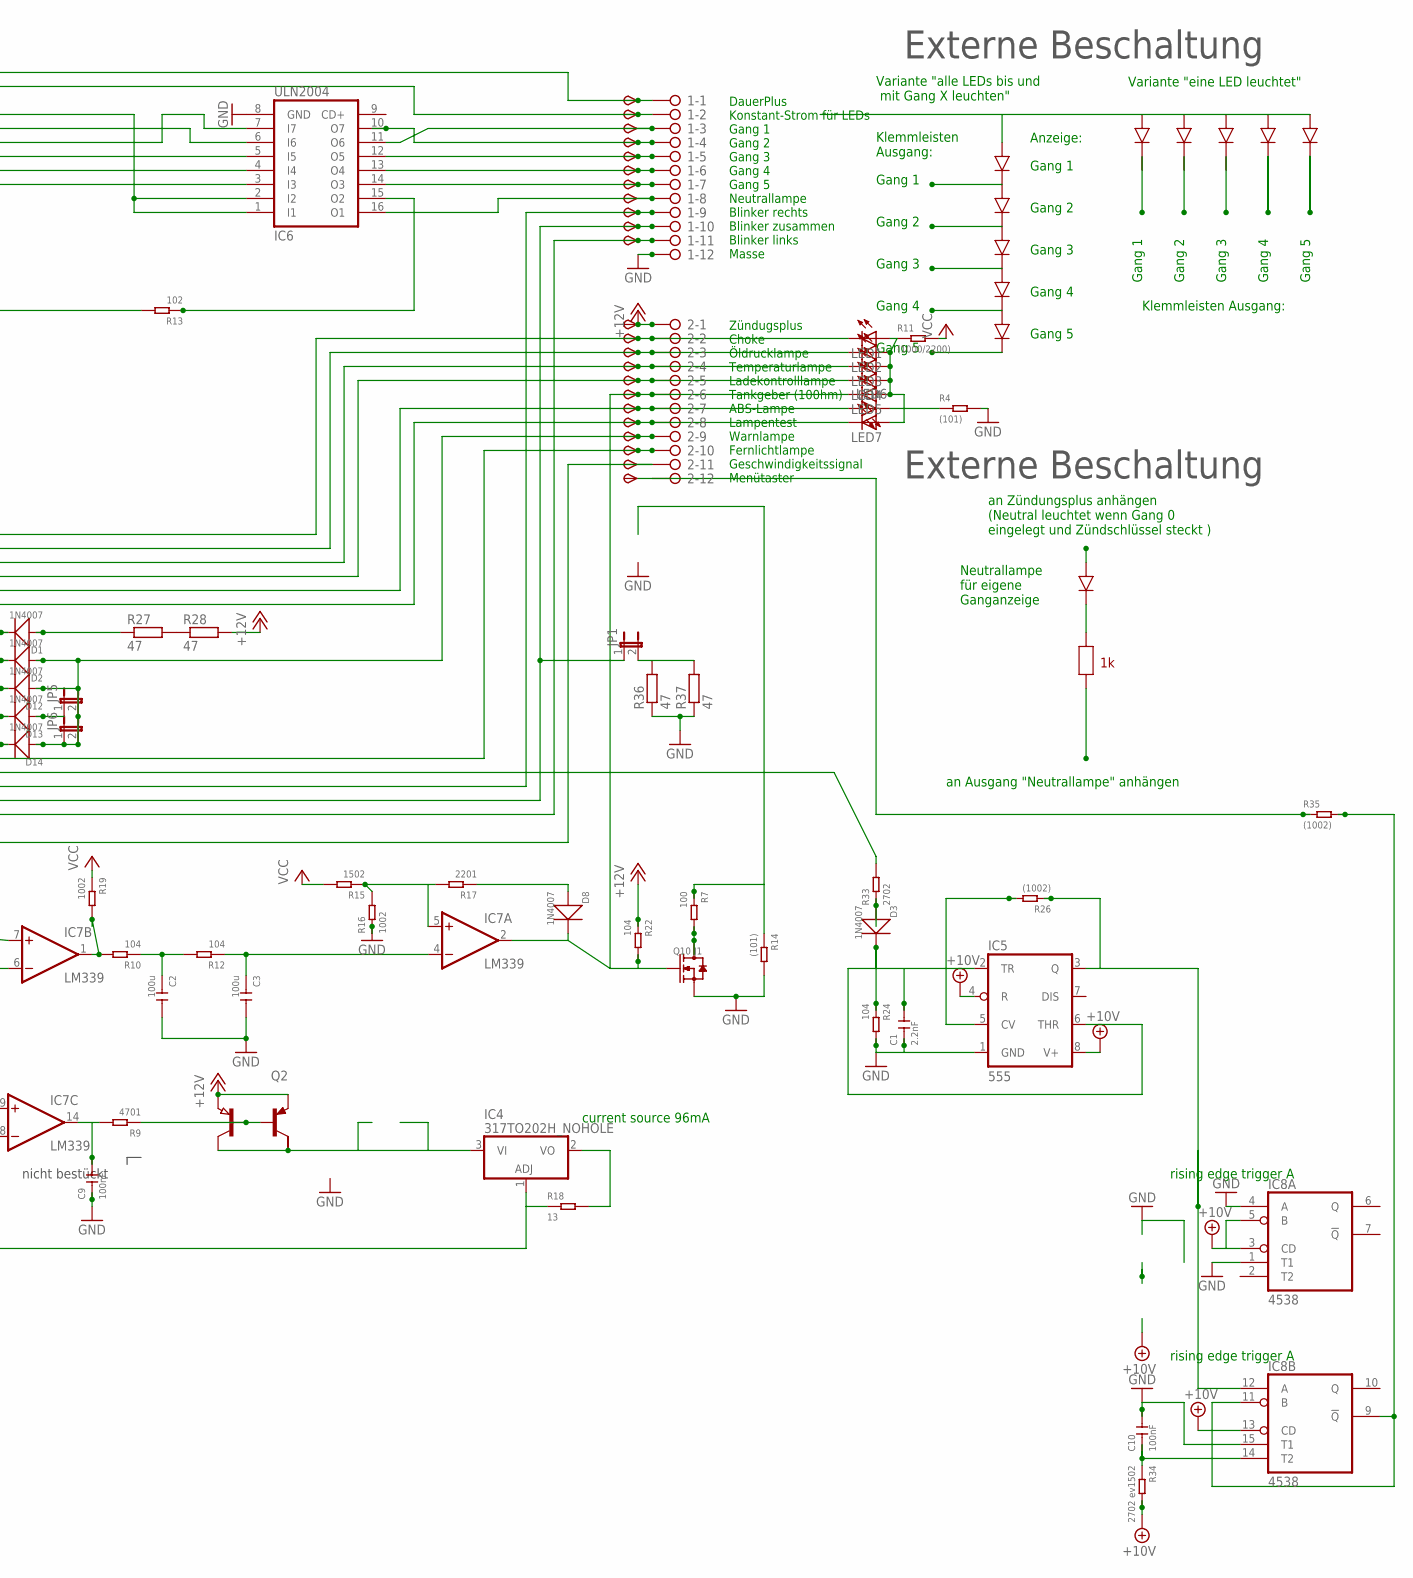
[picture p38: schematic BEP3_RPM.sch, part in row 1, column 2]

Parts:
1, 2: 2081-1132; 12-PIN
C1: 2.2nF; C0805
C2, C3: 100u; C1206
C4, C5, C7, C9, C10: 100nF; C0805
C8: 4.7u; C0805
D1, D3, D10, D11, D15: 1N4007; DO-214AC
D2, D8, D12, D13, D14: 1N4007; DO-214AC-1206MOUNT
IC1: 6V pos; 78LXX
IC2, IC9: 78LXX-SOT89; SOT89
IC3: 4028; SO16
IC4: 317TO202H_NOHOLE; TO220H_NOHOLE
IC5: 555; SO08
IC6: ULN2004; SO16
IC7: LM339; SO14
IC8: 4538; SO16
JP1, JP5, JP6: JP1E; JP1
JP2: JP2E; JP2
LED1, LED2, LED3, LED4, LED5, LED6, LED7: LEDLD260; LD260
Q1, Q2, Q7, Q8: PNP-TRANSISTOR_SOT89; SOT89
Q3: AH-16; SOT223
Q4, Q5, Q6: (AH-16); SOT223
Q9: MY; SOT89
Q10: J1; SOT-23
R1, R9, R32: 4701; R0805
R2, R5, R16, R19: 1002; R0805
R3, R7: 100; R0805
R4, R14: (101); R0805
R6, R15: 1502; R0805
R8, R25, R33: 2702; R0805
R10, R12, R22, R24, R29, R30, R31: 104; R0805
R11: (1000/2200); R0805
R13, R38: 102; R0805
R17, R23: 2201; R0805
R18, R20, R21: 13; R1206
R26, R35: (1002); R0805
R27, R28, R36, R37: 47; V235/17_1MM
R34: 2702 ev1502; R0805
R39: R_user; R0805
T1: PNP2SM8; SM8
T3: (1D); SOT23-BEC
TACHO_BEL: TPSP1_1MM; P1_1.0MM
TP1, TP2, TP3, TP4, TP5, TP6, TP7, TP8, TP9, TP10, TP11, TP12, TP16, TP17, TP18, TP19, TP21, TP22, TP23, TP25, TP26: TPSB1.8; B1.8
TP13, TP24: TPSB1,27; B1,27
X1: CON_BMWV2; 24-PIN_V2
X2: 22-23-2021
X3: 22-23-2051

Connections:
+10V: C7.1, IC5.4 (R), IC5.8 (V+), IC8.3 (CD), IC8.5 (B), IC8.13 (CD), IC8.16 (VDD), IC9.1 (OUT), R34.2
+12V: 2.1, IC1.IN, IC2.3 (IN), IC3.16 (VDD), IC9.3 (IN), JP2.2, Q1.3 (E), Q2.3 (E), Q3.3 (E), Q4.3 (E), R20.1, R21.1, R22.1, R28.2, R29.2, R30.2, R31.2, R32.1, TP12.TP, X1.6, X3.1
GND: 1.12, C1.1, C2.2, C3.2, C4.2, C5.2, C7.2, C8.2, C9.1, C10.2, D15.1 (+), IC1.GND, IC2.2 (GND), IC2.4 (GND), IC3.8 (VSS), IC3.11 (D), IC5.1 (GND), IC6.8 (GND), IC7.12 (GND), IC8.1 (T1), IC8.4 (A), IC8.8 (VSS), IC8.15 (T1), Q9.3 (E), Q10.2 (S), R2.1, R4.2, R8.1, R14.2, R16.1, R24.2, R36.1, R37.1, R38.2, R39.2, T3.E, X1.13, X1.18, X1.23, X2.1, X3.5
unnamed: 2.9, D2.1 (+), D12.1 (+), D14.1 (+), JP5.2, JP6.1, JP6.2, TP24.TP
unnamed: IC3.10 (A), R31.1, X1.4, X3.2
unnamed: IC3.13 (B), R30.1, X1.3, X3.3
unnamed: 2.7, LED6.A, TP22.TP, X1.8
unnamed: Q5.3 (E), Q8.3 (E), R21.2, T1.1 (E)
unnamed: IC7.10 (-IN), R2.2
unnamed: R27.2, R28.1
unnamed: Q6.3 (E), Q7.3 (E), R20.2, T1.3 (E)
unnamed: D15.2 (-), Q1.2 (C), Q3.2 (C), X1.5
unnamed: 2.2, D13.2 (-), LED1.K (C), TP16.TP, X1.12
unnamed: 2.3, D12.2 (-), LED2.K (C), TP17.TP, X1.11
unnamed: 2.4, D2.2 (-), LED3.K (C), TP18.TP, X1.10
unnamed: IC4.3 (VI), Q2.2 (C), Q4.2 (C)
unnamed: IC7.6 (-IN), IC7.8 (-IN), R5.1
unnamed: IC3.12 (C), R29.1, X1.2, X3.4
unnamed: IC3.15 (Q3), IC6.5 (I5)
unnamed: 2.8, D14.2 (-), LED7.K (C), TP23.TP, X1.14
unnamed: 1.9, D10.1 (+), TP9.TP, X1.17
unnamed: 1.11, D11.1 (+), TP11.TP, X1.19
unnamed: IC8.9 (!Q), IC8.11 (B), R35.2
unnamed: R1.2, X1.22
unnamed: C8.1, IC7.11 (+IN), R1.1
unnamed: 1.6, IC6.13 (O4), TP6.TP
unnamed: 1.7, IC6.14 (O3), TP7.TP
unnamed: 2.11, R3.1, R23.1, TP26.TP
unnamed: R7.1, R14.1
unnamed: JP2.1, R23.2
unnamed: C5.1, IC7.9 (+IN), R8.2, R25.2
unnamed: C9.2, IC7.14 (OUT), R9.2
unnamed: C1.2, D3.2 (-), IC5.2 (TR), IC5.6 (THR), R24.1
unnamed: LED6.K (C), R4.1
unnamed: IC4.1 (ADJ), R5.2, R18.1, X1.7
unnamed: Q2.1 (B), Q4.1 (B), R9.1
unnamed: IC3.2 (Q2), IC6.7 (I7)
unnamed: 1.3, IC6.11 (O6), TP3.TP
unnamed: 1.5, IC6.12 (O5), TP5.TP
unnamed: LED1.A, LED2.A, LED3.A, LED4.A, LED5.A, LED7.A, R11.1
unnamed: R33.2, X1.16
unnamed: Q1.1 (B), Q3.1 (B), R13.2
unnamed: IC3.3 (Q0), IC6.1 (I1), IC6.2 (I2)
unnamed: C2.1, R10.1, R12.2
unnamed: C3.1, IC7.4 (-IN), R12.1
unnamed: IC7.5 (+IN), R15.1, R16.2, R17.2
unnamed: Q10.3 (D), R7.2
unnamed: D8.1 (+), R17.1
unnamed: IC3.1 (Q4), IC6.4 (I4)
unnamed: 1.8, IC6.16 (O1), TP8.TP
unnamed: 2.10, TP25.TP, X1.15
unnamed: D1.1 (+), R27.1
unnamed: 2.5, D1.2 (-), LED4.K (C), TP19.TP, X1.9
unnamed: IC3.14 (Q1), IC6.6 (I6)
unnamed: Q5.1 (B), Q6.1 (B), Q6.2 (C), Q7.1 (B), Q7.2 (C), Q8.1 (B), R38.1, R39.1, T1.2 (B), T1.4 (B), T1.6 (C1), X2.2
unnamed: TACHO_BEL.TP, X1.24
unnamed: 1.2, Q5.2 (C), Q8.2 (C), T1.8 (C1), TP2.TP
unnamed: 2.6, D8.2 (-), IC7.2 (OUT), LED5.K (C), Q10.1 (G), R22.2, TP21.TP
unnamed: IC3.6 (Q5), IC6.3 (I3)
unnamed: IC4.2 (VO), R18.2
unnamed: IC5.5 (CV), R26.2
unnamed: 1.4, IC6.10 (O7), TP4.TP
unnamed: 1.1, TP1.TP, X1.1
unnamed: IC7.7 (+IN), R6.1, R25.1
unnamed: Q9.2 (C), R3.2, T3.C, X1.21
unnamed: IC7.13 (OUT), Q9.1 (B), R32.2, T3.B
unnamed: IC5.3 (Q), IC8.12 (A), R26.1
unnamed: D3.1 (+), R33.1
unnamed: IC6.15 (O2), R13.1
unnamed: C10.1, IC8.14 (T2), R34.1
unnamed: 2.12, R35.1, TP13.TP
unnamed: 1.10, D10.2 (-), D11.2 (-), JP1.1, TP10.TP
unnamed: JP1.2, R36.2, R37.2
unnamed: D13.1 (+), JP5.1
unnamed: IC7.1 (OUT), R10.2, R19.2
VCC: C4.1, IC1.OUT, IC2.1 (OUT), IC7.3 (V+), R6.2, R11.2, R15.2, R19.1

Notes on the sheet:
6V regulated for Opamps
current source 96mA
ZündungsPlus
Zündugsplus Choke Öldrucklampe Temperaturlampe Ladekontrolllampe Tankgeber (100hm) ABS-Lampe Lampentest Warnlampe Fernlichtlampe Geschwindigkeitssignal Menütaster
DauerPlus Konstant-Strom für LEDs Gang 1 Gang 2 Gang 3 Gang 4 Gang 5 Neutrallampe Blinker rechts Blinker zusammen Blinker links Masse
DauerPlus Batterie 12V (rot weiss) Ganganzeige Signal C (gelb weiss) Ganganzeige Signal B (gelb schwarz) Ganganzeige Signal A (gelb dunkelblau) 12V/350mA zum Starknopf (schwarz grün) Zündungsplus 12V (grün schwarz) Reservelampe (weiss) ABS Leuchte (blau) Ladekontrollleuchte (schaltet auf Masse) (vi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
Masse (braun) Lampentest (schaltet auf Masse)(weiss blau) Fernlichtlampe (12V) (weiss) Drehzahl Zündspule (schwarz blau) Blinker rechts (blau scharz) Masse (braun) Blinker links (blau rot) nicht angeschlossen Tachosiganl zum Blinrelais (balu grün) Tachogeber (gelb) Masse Tachobeger (braun) Tachobel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
4.7V
Stromquelle für Gang LEDs. Für mehr als 12mA muss ein Widerstand "R_user" eingelötet werden. Für weniger muss der 1kOhm SMD Widerstand neben R_user entfernt werden I = 12V/1kOhm(default)+12V/R_user I= 12mA (default) + 12V/R_user Beispiel: R_user Strom in LEDs 1 kOhm 22-26mA ohne 11-13mA
Gang 1
Gang 2
Gang 3
Gang 4
Gang 5
Variante "eine LED leuchtet"
Variante "alle LEDs bis und mit Gang X leuchten"
Klemmleisten Ausgang:
Klemmleisten Ausgang:
an Zündungsplus anhängen (Neutral leuchtet wenn Gang 0 eingelegt und Zündschlüssel steckt )
an Ausgang "Neutrallampe" anhängen
Neutrallampe für eigene Ganganzeige
Externe Beschaltung
Anzeige:
nicht bestückt
rising edge trigger A

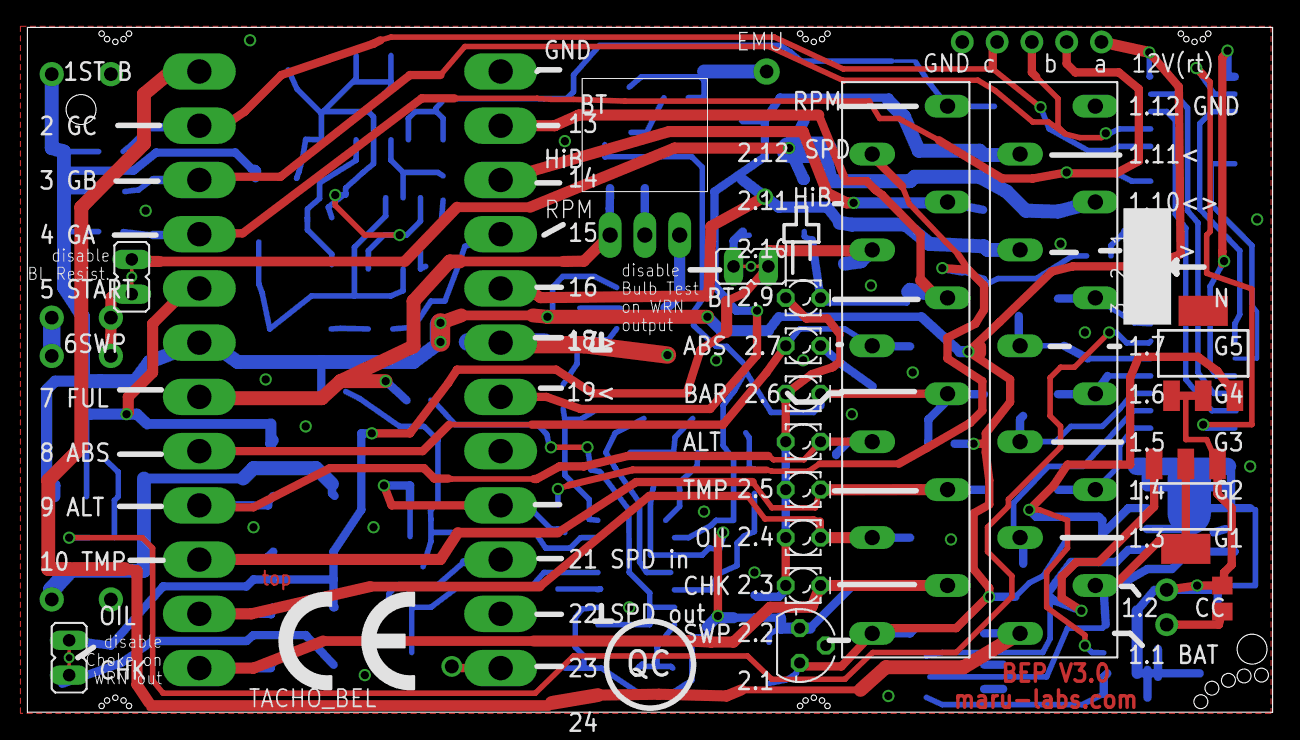
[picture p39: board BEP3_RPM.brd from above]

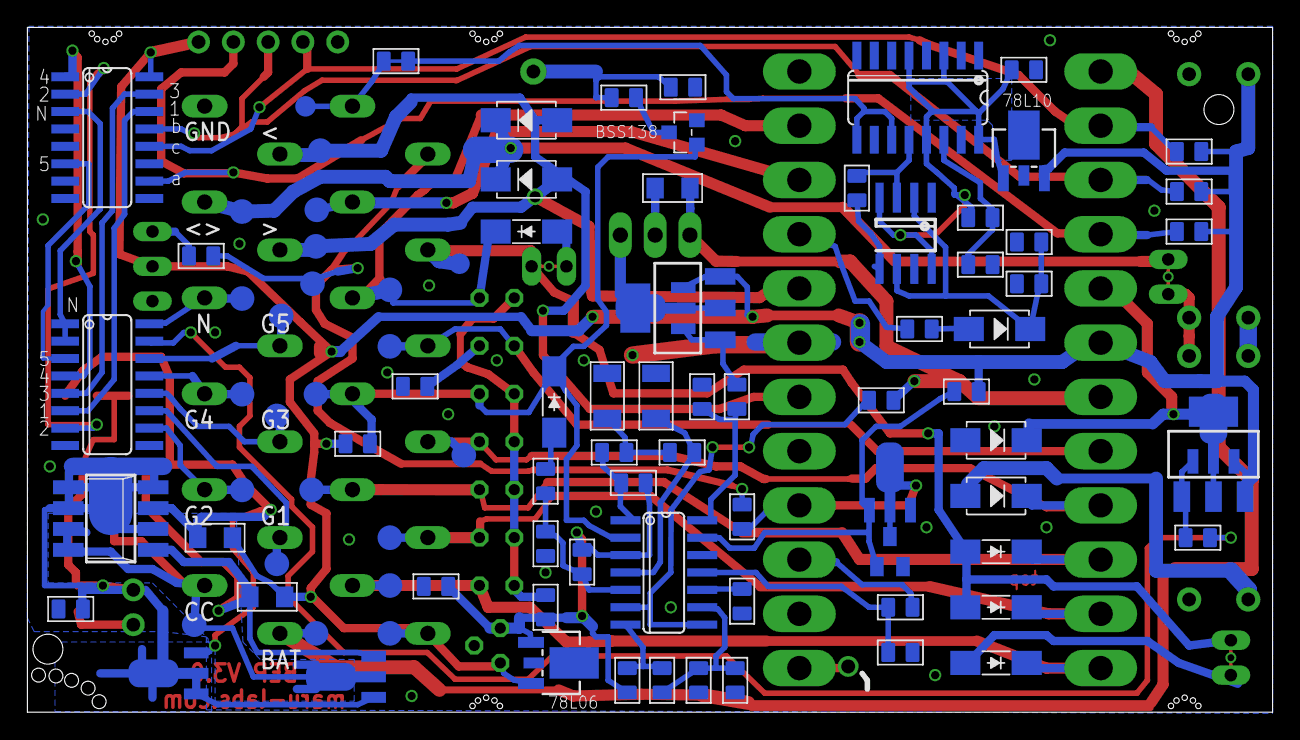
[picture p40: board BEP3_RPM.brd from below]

Board: 2 copper layers, 90.9 x 50.0 mm, 120 parts (94 on the bottom side), 76 nets.

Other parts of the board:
U$1: CE_10.00

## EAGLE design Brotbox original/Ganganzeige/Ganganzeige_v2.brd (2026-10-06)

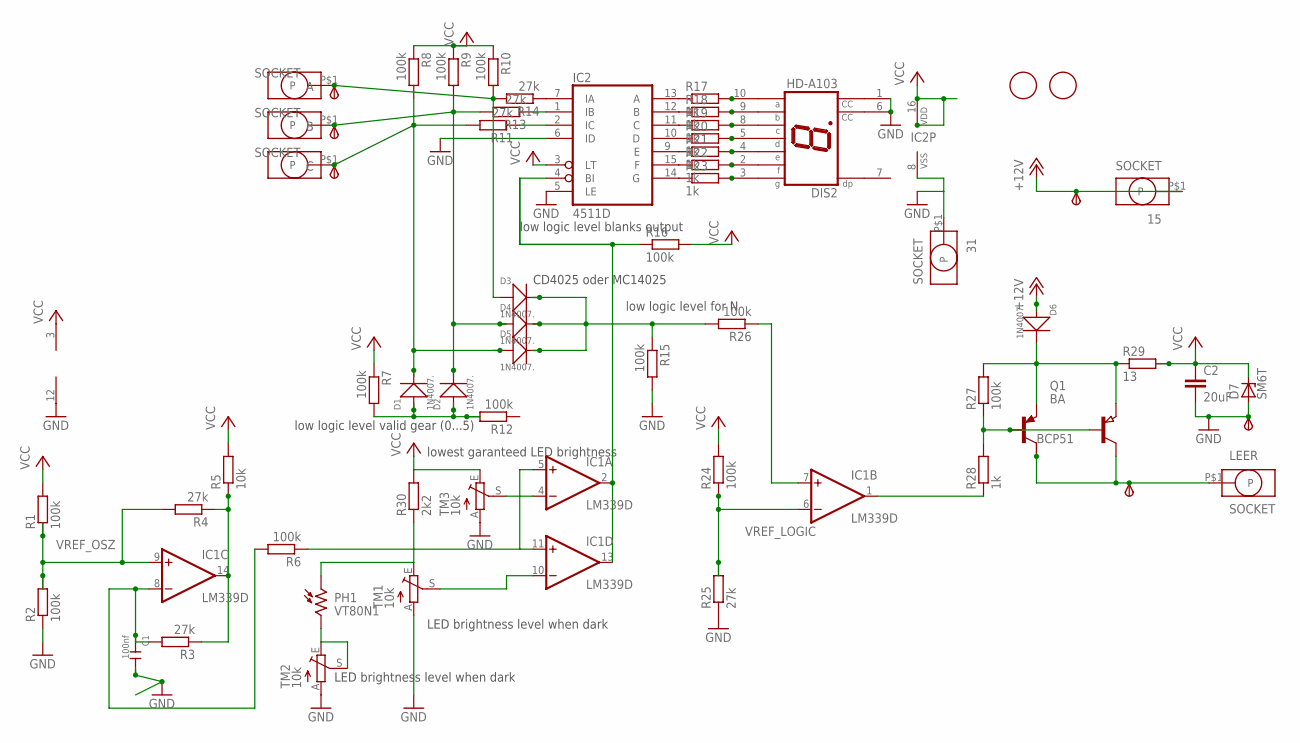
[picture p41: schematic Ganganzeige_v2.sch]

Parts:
15, 31: SOCKET; ID2.5MM
15_: TPSB2.0; B2.0
A: SOCKET; ID2.5MM
A_: TPSB2.0; B2.0
B: SOCKET; ID2.5MM
B_: TPSB2.0; B2.0
C: SOCKET; ID2.5MM
C1: 100nf; C0805
C2: 20uF; C1206K
C_: TPSB2.0; B2.0
D1, D2, D3, D4, D5, D6: 1N4007.; DO-214AC
D7: SM6T; DO214AA
DIS2: HD-A103; HDSP-A
FID1, FID2: FIDUCIAL; FIDUCIAL_1MM
GND_: TPSB2.0; B2.0
IC1: LM339D; SO14
IC2: 4511D; SO16
LEER: SOCKET; ID2.5MM
LEER_: TPSB2.0; B2.0
PH1: VT80N1; VT800
Q1: BA; SOT89
R1, R2, R6, R7, R8, R9, R10, R12, R15, R16, R24, R26, R27: 100k; R0805
R3, R4, R11, R13, R14, R25: 27k; R0805
R5: 10k; R0805
R17, R18, R19, R20, R21, R22, R23, R28: 1k; R0805
R29: 13; R1206
R30: 2k2; R0805
T: BCP53T1; SOT223
TM1, TM2, TM3: 10k; S63X

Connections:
+12V: 15.P$1, 15_.TP, D6.1 (+)
GND: 31.P$1, C1.2, C2.2, D7.A, DIS2.1 (CC), DIS2.6 (CC), GND_.TP, IC1.12 (GND), IC2.5 (LE), IC2.6 (ID), IC2.8 (VSS), R2.1, R15.2, R25.1, TM1.A, TM2.A, TM3.A
unnamed: IC2.13 (A), R17.1
unnamed: DIS2.10 (A), R17.2
unnamed: IC2.12 (B), R18.1
unnamed: DIS2.9 (B), R18.2
unnamed: IC2.11 (C), R19.1
unnamed: DIS2.8 (C), R19.2
unnamed: IC2.10 (D), R20.1
unnamed: DIS2.5 (D), R20.2
unnamed: IC2.9 (E), R21.1
unnamed: PH1.1, R30.1, TM1.E
unnamed: DIS2.4 (E), R21.2
unnamed: IC2.15 (F), R22.1
unnamed: DIS2.2 (F), R22.2
unnamed: IC2.14 (G), R23.1
unnamed: DIS2.3 (G), R23.2
unnamed: A.P$1, A_.TP, D3.1 (+), R10.2, R14.2
unnamed: B.P$1, B_.TP, D2.2 (-), D4.1 (+), R9.2, R13.2
unnamed: C.P$1, C_.TP, D1.2 (-), D5.1 (+), R8.2, R11.2
unnamed: IC1.1 (OUT), R28.1
unnamed: Q1.1 (B), R27.1, R28.2, T.1 (B)
unnamed: PH1.2, TM2.E, TM2.S
unnamed: C1.1, IC1.8 (-IN), R3.2, R6.2
unnamed: IC1.14 (OUT), R3.1, R4.1, R5.1
unnamed: D1.1 (+), D2.1 (+), R7.2, R12.2
unnamed: IC1.2 (OUT), IC1.13 (OUT), IC2.4 (BI), R16.1
unnamed: IC1.5 (+IN), IC1.11 (+IN), R6.1
unnamed: IC1.10 (-IN), TM1.S
unnamed: IC1.4 (-IN), TM3.S
unnamed: IC1.7 (+IN), R26.1
unnamed: IC2.7 (IA), R14.1
unnamed: D3.2 (-), D4.2 (-), D5.2 (-), R15.1, R26.2
unnamed: IC2.2 (IC), R11.1
unnamed: IC2.1 (IB), R13.1
VCC: C2.1, D7.C, IC1.3 (V+), IC2.3 (LT), IC2.16 (VDD), R1.2, R5.2, R7.1, R8.1, R9.1, R10.1, R16.2, R24.2, R29.2, R30.2, TM3.E
VREF_LOGIC: IC1.6 (-IN), R24.1, R25.2
VREF_OSZ: IC1.9 (+IN), R1.1, R2.2, R4.2
ZUENDPLUS_OUT: LEER.P$1, LEER_.TP, Q1.2 (C), T.2 (C)
ZUEND_EIN: D6.2 (-), Q1.3 (E), R27.2, R29.1, T.3 (E)

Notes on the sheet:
CD4025 oder MC14025
low logic level for N
low logic level valid gear (0...5)
low logic level blanks output
LED brightness level when dark
lowest garanteed LED brightness

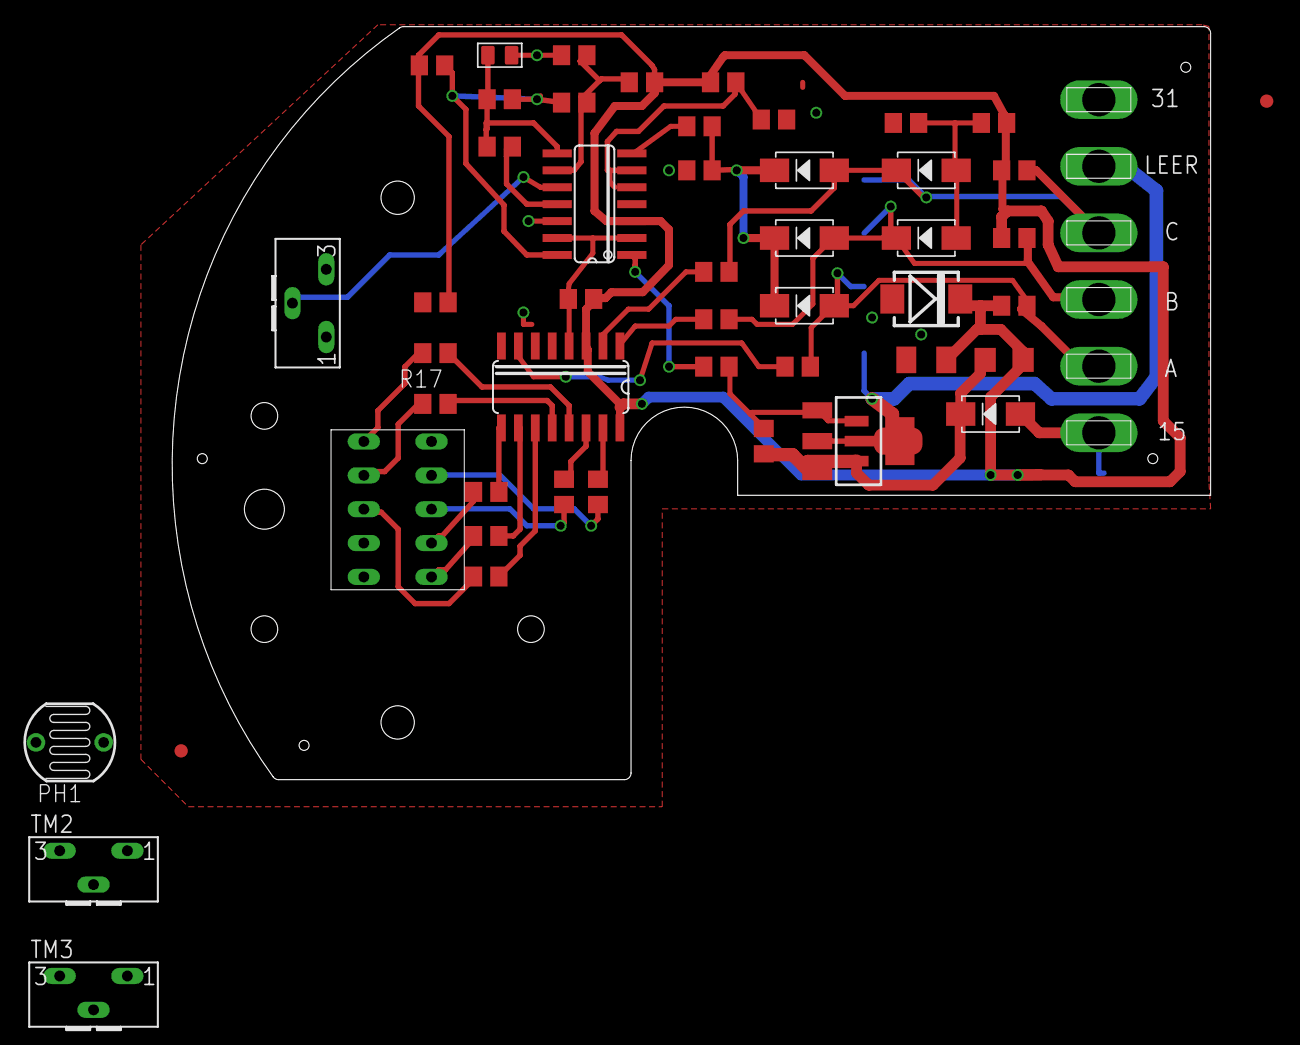
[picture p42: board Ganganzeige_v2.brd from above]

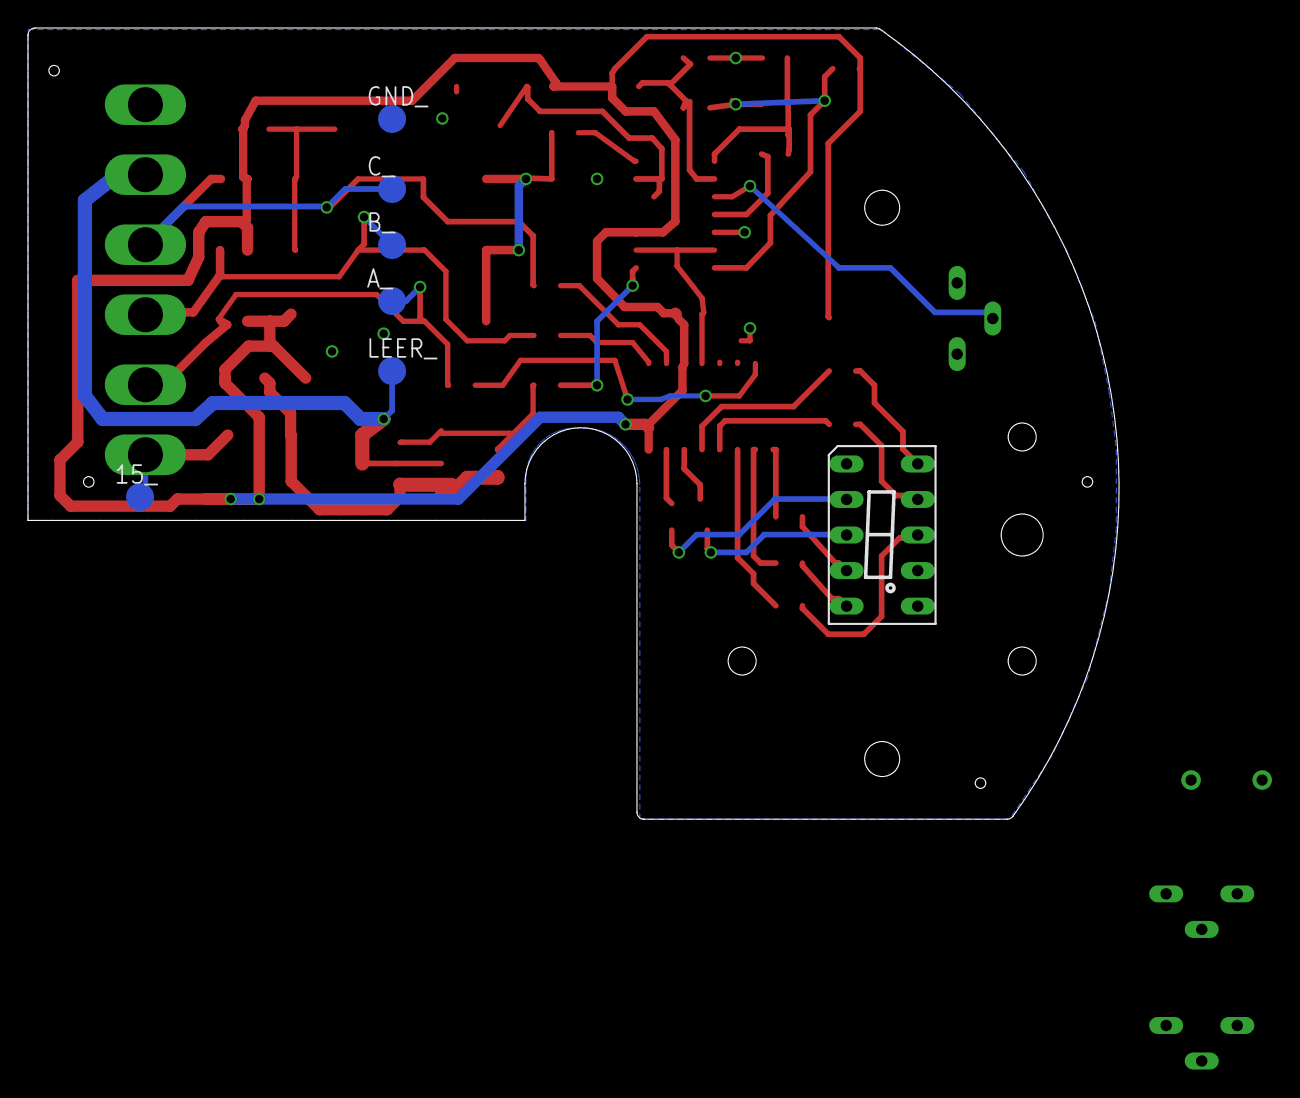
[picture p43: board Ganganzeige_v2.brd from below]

Board: 2 copper layers, 77.9 x 56.5 mm, 62 parts (7 on the bottom side), 40 nets.

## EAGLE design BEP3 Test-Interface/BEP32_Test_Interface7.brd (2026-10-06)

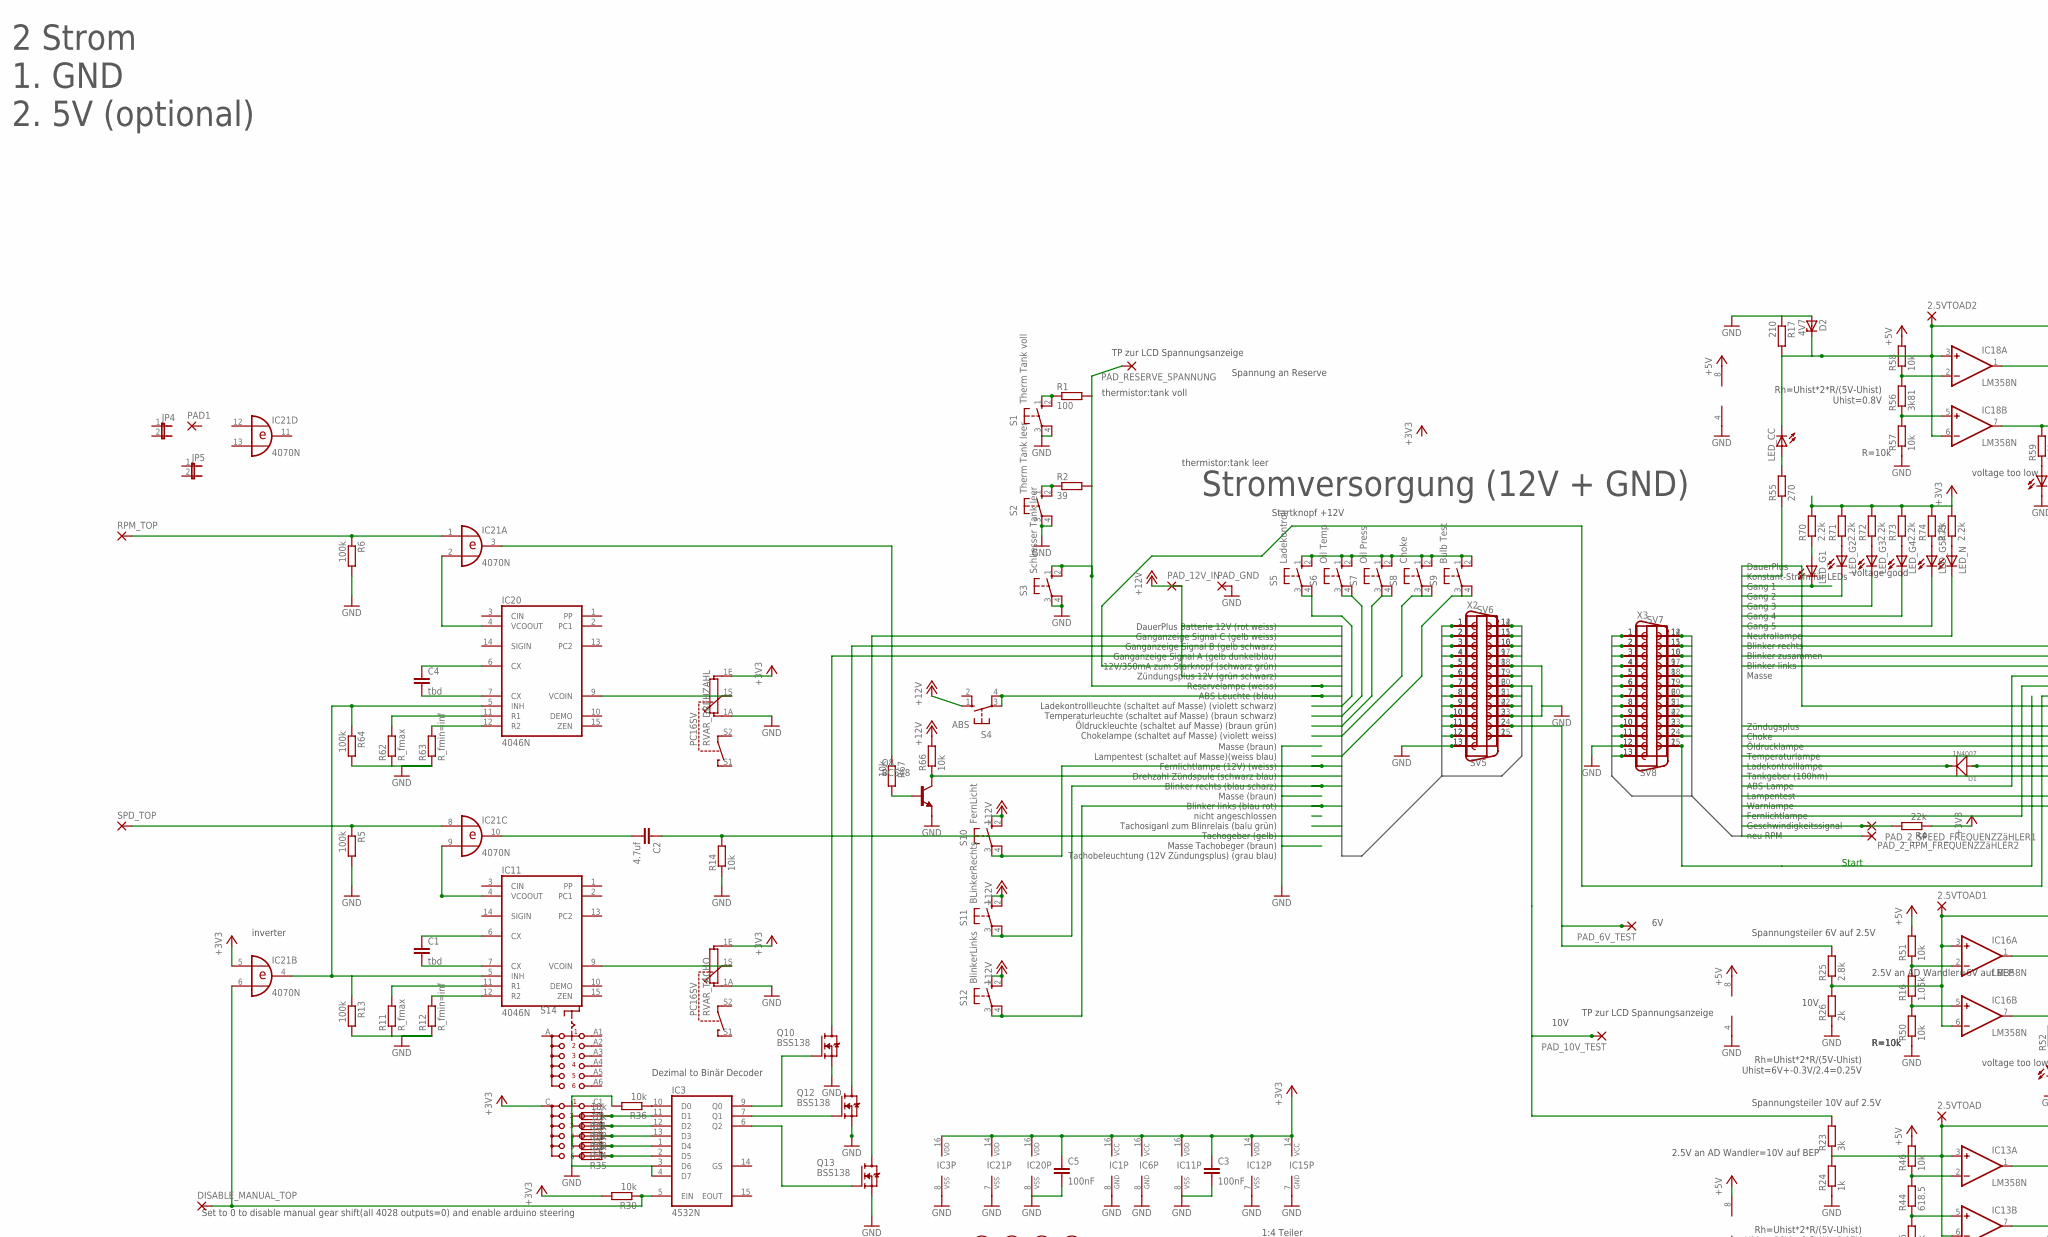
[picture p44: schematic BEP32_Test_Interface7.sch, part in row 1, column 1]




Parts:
2.5VTOAD, 2.5VTOAD1, 2.5VTOAD2, 6V_OK_BOT, 6V_OK_TOP, 6V_VOLTAGE_BOT, 6V_VOLTAGE_TOP, 10V_OK_BOT, 10V_OK_TOP, 10V_VOLTAGE_BOT, 10V_VOLTAGE_TOP: 1,6/0,9
C1, C4: tbd; C1206K
C2: 4.7uf; C025_050-025X075
C3, C5: 100nF; C1206K
CC_VOLTAGE_BOT: 1,6/0,9
CC_VOLTAGE_OK_BOT: 1,6/0,9
CC_VOLTAGE_OK_TOP: 1,6/0,9
CC_VOLTAGE_TOP: 1,6/0,9
D1, D4: 1N4007; DO-214AC
D2, D3: 4V7; F126Z10
DISABLE_MANUAL_BOT: 1,6/0,9
DISABLE_MANUAL_TOP: 1,6/0,9
IC1, IC6: 74HC595N; DIL16
IC3: 4532N; DIL16
IC5, IC7: ULN2003; DIL18
IC8, IC9, IC10: 74HC165N; DIL16
IC11, IC20: 4046N; DIL16
IC12, IC21: 4070N; DIL14
IC13, IC16, IC18: LM358N; DIL08
IC14: 4053N; DIL16
IC15: 74HC132N; DIL14
JP1, JP2, JP3: JP2E; JP2
JP4, JP5: JP1E; JP1
LED_6V_HIGH, LED_6V_LOW, LED_6V_OK, LED_10V_HIGH, LED_10V_LOW, LED_10V_OK: LED5MM
LED_<: LED5MM
LED_<>: LED5MM
LED_>: LED5MM
LED_ABS: LED5MM
LED_ALT: LED5MM
LED_BT: LED5MM
LED_CC: LED5MM
LED_CC_HIGH: LED5MM
LED_CC_LOW: LED5MM
LED_CC_OK: LED5MM
LED_CHK: LED5MM
LED_DREHZAHL: LED5MM
LED_G1, LED_G2, LED_G3, LED_G4, LED_G5: LED5MM
LED_HIB: LED5MM
LED_N: LED5MM
LED_OIL: LED5MM
LED_RES: LED5MM
LED_SPD: LED5MM
LED_START: LED5MM
LED_SWP: LED5MM
LED_TMP: LED5MM
LED_WRN: LED5MM
PAD1: 1,6/0,9
PAD_2_RPM_FREQUENZZäHLER2, PAD_2_SPEED_FREQUENZZäHLER1, PAD_6V_TEST, PAD_10V_TEST, PAD_12V_IN: 1,6/0,9
PAD_GND: 1,6/0,9
PAD_RESERVE_SPANNUNG: 1,6/0,9
Q1, Q2, Q3, Q4: BSP452T1; SOT223
Q5, Q6, Q7: IRF540; TO220BV
Q8: BC548; TO92-EBC
Q9, Q10, Q12, Q13: BSS138; SOT23
R1, R76: 100; 0207/10
R2, R15: 39; 0207/10
R3, R14, R18, R19, R20, R21, R22, R30, R31, R32, R33, R34, R35, R36, R37, R39, R40, R45, R46, R50, R51, R57, R58, R66, R67, R69, R89, R90, R91, R92, R93, R94, R95: 10k; 0207/10
R4, R38: 22k; 0207/10
R5, R6, R13, R41, R64: 100k; 0207/10
R7, R42, R43, R47, R48, R49, R52, R53, R54, R59, R60, R61, R65, R70, R71, R72, R73, R74, R75, R77, R78, R79, R80, R81, R82, R83, R84, R85, R86, R87, R88: 2.2k; 0207/10
R11, R62: R_fmax; 0207/10
R12, R63: R_fmin=inf; 0207/10
R16: 1.05k; 0207/10
R17: 210; 0207/10
R23: 3k; 0207/10
R24: 1k; 0207/10
R25: 2.8k; 0207/10
R26: 2k; 0207/10
R44: 618.5; 0207/10
R55: 270; 0207/10
R56: 3k81; 0207/10
R68: 30k; 0207/10
RPM_BOT: 1,6/0,9
RPM_TOP: 1,6/0,9
RVAR_DREHZAHL: PC16SV
RVAR_TACHO: PC16SV
S1: Therm Tank voll; B3F-40XX
S2: Therm Tank leer; B3F-40XX
S3: Schliesser Tank leer; B3F-40XX
S4: ABS; B3F-40XX
S5: Ladekontroll; B3F-40XX
S6: Oil Temp; B3F-40XX
S7: Oil Press; B3F-40XX
S8: Choke; B3F-40XX
S9: Bulb Test; B3F-40XX
S10: FernLicht; B3F-40XX
S11: BLinkerRechts; B3F-40XX
S12: BlinkerLinks; B3F-40XX
S14: CK102X06
SPD_BOT: 1,6/0,9
SPD_TOP: 1,6/0,9
SV1, SV4, SV6, SV7: MA12-1
SV2, SV3, SV5, SV8: MA13-1
U$1, U$2, U$3, U$4: FIDUCIAL; FIDUCIAL_1MM
X1, X2, X3, X4: F25H
X5: F09H

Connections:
+3V3: C3.1, C5.1, IC1.10 (SCL), IC1.16 (VCC), IC3.16 (VDD), IC6.10 (SCL), IC6.16 (VCC), IC8.16 (VCC), IC9.16 (VCC), IC10.16 (VCC), IC11.16 (VDD), IC12.14 (VDD), IC14.16 (VCC), IC15.14 (VCC), IC20.16 (VDD), IC21.5 (I0), IC21.14 (VDD), LED_DREHZAHL.A, R3.2, R4.1, R18.2, R19.2, R20.2, R21.2, R22.2, R30.2, R37.2, R38.2, R42.2, R70.2, R71.2, R72.2, R73.2, R74.2, R75.2, R80.2, R81.2, R82.2, R83.2, R84.2, R86.2, R87.2, R89.2, R90.2, R91.2, R92.2, R93.2, R94.2, R95.2, RVAR_DREHZAHL.1E, RVAR_TACHO.1E, S14.C
+5V: IC13.8 (V+), IC16.8 (V+), IC18.8 (V+), R46.2, R51.2, R58.2
+12V: Q1.4 (V+), Q2.4 (V+), Q3.4 (V+), Q4.4 (V+), R66.2, S4.1 (S), S10.1 (S), S10.2 (S1), S11.1 (S), S11.2 (S1), S12.1 (S), S12.2 (S1)
ALT: D1.1 (+), LED_ALT.K (C)
ALT1: D4.1 (+), R92.1
BMW1_12V: PAD_12V_IN.1, SV5.1, X2.1
BMW1_12V1: SV2.1, X1.1
BMW2_C: Q13.3 (D), SV5.2, X2.2
BMW2_C1: IC5.18 (O1), SV2.2, X1.2
BMW3_B: Q12.3 (D), SV5.3, X2.3
BMW3_B1: IC5.17 (O2), SV2.3, X1.3
BMW4_A: Q10.3 (D), SV5.4, X2.4
BMW4_A1: IC5.16 (O3), SV2.4, X1.4
BMW5_START: LED_START.A, SV5.5, X2.5
BMW5_START1: IC7.6 (I6), SV2.5, X1.5
BMW6_ZP: SV5.6, X2.6
BMW6_ZP1: SV2.6, X1.6
BMW7_RES: PAD_RESERVE_SPANNUNG.1, R1.2, R2.2, S3.1 (S), S3.2 (S1), SV5.7, X2.7
BMW7_RES1: Q7.D, R68.2, R76.2, SV2.7, X1.7
BMW8_ABS: S4.3, S4.4 (P1), SV5.8, X2.8
BMW8_ABS1: Q1.1 (OUT), SV2.8, X1.8
BMW9_ALT: S5.3, S5.4 (P1), SV5.9, X2.9
BMW9_ALT1: IC5.15 (O4), SV2.9, X1.9
BMW10_TMP: S6.3, S6.4 (P1), SV5.10, X2.10
BMW10_TMP1: IC5.14 (O5), SV2.10, X1.10
BMW11_OIL: S7.3, S7.4 (P1), SV5.11, X2.11
BMW11_OIL1: IC5.13 (O6), SV2.11, X1.11
BMW12_CHK: S8.3, S8.4 (P1), SV5.12, X2.12
BMW12_CHK1: IC5.12 (O7), SV2.12, X1.12
BMW14_BT: S9.3, S9.4 (P1), SV6.12, X2.14
BMW14_BT1: IC5.11 (O8), SV1.12, X1.14
BMW15_HIB: S10.3, S10.4 (P1), SV6.11, X2.15
BMW15_HIB1: Q2.1 (OUT), SV1.11, X1.15
BMW16_RPM: Q8.C, R66.1, SV6.10, X2.16
BMW16_RPM1: SV1.10, X1.16
BMW17_>: S11.3, S11.4 (P1), SV6.9, X2.17
BMW17_>1: Q3.1 (OUT), SV1.9, X1.17
BMW19_<: S12.3, S12.4 (P1), SV6.7, X2.19
BMW19_<1: Q4.1 (OUT), SV1.7, X1.19
BMW21_SPDBACK: SV6.5, X2.21
BMW21_SPDBACK1: SV1.5, X1.21
BMW22_SPD: C2.1, R14.2, SV6.4, X2.22
BMW22_SPD1: SV1.4, X1.22
BMW24_10V: PAD_10V_TEST.1, R23.2, SV6.6, X2.20
BMW24_10V1: SV1.6, X1.20
DISABLE_MANUAL: DISABLE_MANUAL_TOP.1, IC3.5 (EIN), IC21.6 (I1), R30.1
DISABLE_MANUAL_BOT: DISABLE_MANUAL_BOT.1, IC1.13 (G), IC6.13 (G), R37.1
GND: C3.2, C5.2, D2.A, D3.A, IC1.8 (GND), IC3.3 (D6), IC3.4 (D7), IC3.8 (VSS), IC5.9 (GND), IC6.8 (GND), IC7.9 (GND), IC8.8 (GND), IC9.8 (GND), IC10.8 (GND), IC11.8 (VSS), IC12.6 (I1), IC12.7 (VSS), IC12.9 (I1), IC13.4 (V-), IC14.6 (INH), IC14.7 (VEE), IC14.8 (GND), IC14.9 (C), IC15.7 (GND), IC16.4 (V-), IC18.4 (V-), IC20.8 (VSS), IC21.7 (VSS), LED_6V_HIGH.K (C), LED_6V_LOW.K (C), LED_6V_OK.K (C), LED_10V_HIGH.K (C), LED_10V_LOW.K (C), LED_10V_OK.K (C), LED_CC_HIGH.K (C), LED_CC_LOW.K (C), LED_CC_OK.K (C), PAD_GND.1, Q1.2 (GND), Q2.2 (GND), Q3.2 (GND), Q4.2 (GND), Q5.S, Q6.S, Q7.S, Q8.E, Q9.2 (S), Q10.2 (S), Q12.2 (S), Q13.2 (S), R5.2, R6.2, R7.2, R11.1, R12.1, R13.2, R14.1, R17.1, R24.1, R26.1, R31.2, R32.2, R33.2, R34.2, R35.2, R36.2, R40.1, R41.2, R45.1, R50.1, R57.1, R62.1, R63.1, R64.2, R65.2, R69.2, R77.2, R78.2, R79.2, R85.2, R88.2, RVAR_DREHZAHL.1A, RVAR_TACHO.1A, S1.3, S1.4 (P1), S2.3, S2.4 (P1), S3.3, S3.4 (P1), SV1.3, SV1.8, SV2.13, SV3.12, SV5.13, SV6.3, SV6.8, SV8.12, X1.13, X1.18, X1.23, X2.13, X2.18, X2.23, X3.12, X4.12
unnamed: R2.1, S2.1 (S), S2.2 (S1)
unnamed: R1.1, S1.1 (S), S1.2 (S1)
unnamed: LED_>.K (C), R65.1
unnamed: LED_<>.K (C), R77.1
unnamed: LED_<.K (C), R78.1
unnamed: IC1.15 (QA), IC5.1 (I1)
unnamed: IC1.1 (QB), IC5.2 (I2)
unnamed: IC1.2 (QC), IC5.3 (I3)
unnamed: IC11.5 (INH), IC20.5 (INH), IC21.4 (O), R13.1, R64.1
unnamed: IC14.12 (X0), JP2.3, SPD_BOT.1
unnamed: IC21.1 (I0), R6.1, RPM_TOP.1
unnamed: IC3.9 (Q0), Q10.1 (G)
unnamed: IC3.6 (Q2), Q13.1 (G)
unnamed: IC1.3 (QD), Q7.G
unnamed: IC1.4 (QE), Q5.G
unnamed: IC1.9 (QH*), IC6.14 (SER)
unnamed: IC1.12 (RCK), IC6.12 (RCK)
unnamed: S5.1 (S), S5.2 (S1), S6.1 (S), S6.2 (S1), S7.1 (S), S7.2 (S1), S8.1 (S), S8.2 (S1), S9.1 (S), S9.2 (S1)
unnamed: IC8.9 (QH), IC9.10 (SER)
unnamed: Q6.D, R15.1
unnamed: IC1.6 (QG), IC5.4 (I4)
unnamed: IC5.5 (I5), IC6.15 (QA)
unnamed: IC5.6 (I6), IC6.1 (QB)
unnamed: IC5.7 (I7), IC6.2 (QC)
unnamed: IC5.8 (I8), IC6.3 (QD)
unnamed: IC6.4 (QE), Q1.3 (IN)
unnamed: IC6.5 (QF), Q2.3 (IN)
unnamed: IC6.6 (QG), Q3.3 (IN)
unnamed: IC6.7 (QH), Q4.3 (IN)
unnamed: C1.2, IC11.7 (CX)
unnamed: C1.1, IC11.6 (CX)
unnamed: IC11.11 (R1), R11.2
unnamed: IC11.12 (R2), R12.2
unnamed: C2.2, IC21.10 (O)
unnamed: IC1.5 (QF), Q6.G
unnamed: LED_G1.A, R70.1
unnamed: IC11.9 (VCOIN), RVAR_TACHO.1S
unnamed: IC21.8 (I0), R5.1, SPD_TOP.1
unnamed: LED_WRN.A, R87.1
unnamed: 2.5VTOAD2.1, CC_VOLTAGE_TOP.1, D2.C, IC18.3 (+IN), IC18.6 (-IN), LED_CC.K (C), R17.2
unnamed: IC16.5 (+IN), R16.1, R50.2
unnamed: 2.5VTOAD1.1, 6V_VOLTAGE_TOP.1, IC16.3 (+IN), IC16.6 (-IN), R25.1, R26.2
unnamed: IC14.14 (X), JP2.1
unnamed: IC9.9 (QH), IC10.10 (SER)
unnamed: IC3.11 (D1), R31.1, S14.C2
unnamed: IC3.12 (D2), R32.1, S14.C3
unnamed: IC3.13 (D3), R33.1, S14.C4
unnamed: IC3.1 (D4), R34.1, S14.C5
unnamed: IC3.2 (D5), R35.1, S14.C6
unnamed: IC3.10 (D0), R36.1
unnamed: IC14.10 (B), IC14.11 (A), JP1.1, R41.1
unnamed: IC14.15 (Y), JP3.3
unnamed: Q9.3 (D), R43.1
unnamed: IC14.13 (X1), JP1.3, RPM_BOT.1
unnamed: IC12.8 (I0), R39.1, R40.2
unnamed: LED_ABS.K (C), R85.1
unnamed: LED_HIB.K (C), R88.1
unnamed: LED_DREHZAHL.K (C), R43.2
unnamed: IC13.5 (+IN), R44.1, R45.2
unnamed: IC13.2 (-IN), R44.2, R46.1
unnamed: 2.5VTOAD.1, 10V_VOLTAGE_TOP.1, IC13.3 (+IN), IC13.6 (-IN), R23.1, R24.2
unnamed: IC16.2 (-IN), R16.2, R51.1
unnamed: IC13.1 (OUT), IC15.1 (I0), R48.2
unnamed: IC13.7 (OUT), IC15.2 (I1), R47.2
unnamed: LED_10V_LOW.A, R47.1
unnamed: LED_10V_HIGH.A, R48.1
unnamed: LED_10V_OK.A, R49.1
unnamed: 10V_OK_TOP.1, IC15.3 (O), R49.2
unnamed: IC11.4 (VCOOUT), IC21.9 (I1)
unnamed: IC15.4 (I0), IC16.1 (OUT), R53.2
unnamed: IC15.5 (I1), IC16.7 (OUT), R52.2
unnamed: LED_6V_LOW.A, R52.1
unnamed: LED_6V_HIGH.A, R53.1
unnamed: LED_6V_OK.A, R54.1
unnamed: 6V_OK_TOP.1, IC15.6 (O), R54.2
unnamed: LED_CC.A, R55.2
unnamed: IC18.5 (+IN), R56.1, R57.2
unnamed: IC18.2 (-IN), R56.2, R58.1
unnamed: C4.2, IC20.7 (CX)
unnamed: IC15.9 (I0), IC18.1 (OUT), R60.2
unnamed: IC15.10 (I1), IC18.7 (OUT), R59.2
unnamed: LED_CC_LOW.A, R59.1
unnamed: LED_CC_HIGH.A, R60.1
unnamed: LED_CC_OK.A, R61.1
unnamed: CC_VOLTAGE_OK_TOP.1, IC15.8 (O), R61.2
unnamed: C4.1, IC20.6 (CX)
unnamed: IC20.11 (R1), R62.2
unnamed: IC20.12 (R2), R63.2
unnamed: IC20.4 (VCOOUT), IC21.2 (I1)
unnamed: LED_SWP.K (C), R79.1
unnamed: PAD_6V_TEST.1, R25.2, SV6.2, X2.24
unnamed: SV1.2, X1.24
unnamed: LED_START.K (C), R7.1
unnamed: IC20.9 (VCOIN), RVAR_DREHZAHL.1S
unnamed: Q5.D, R76.1
unnamed: IC21.3 (O), R67.1
unnamed: Q8.B, R67.2
unnamed: LED_G2.A, R71.1
unnamed: D3.C, R68.1, R69.1
unnamed: LED_G3.A, R72.1
unnamed: LED_G4.A, R73.1
unnamed: LED_G5.A, R74.1
unnamed: LED_N.A, R75.1
unnamed: LED_CHK.A, R80.1
unnamed: LED_OIL.A, R81.1
unnamed: LED_TMP.A, R82.1
unnamed: LED_ALT.A, R83.1
unnamed: LED_RES.A, R84.1
unnamed: LED_SPD.A, R42.1
unnamed: LED_BT.A, R86.1
unnamed: SV1.1, X1.25
unnamed: SV6.1, X2.25
unnamed: IC3.7 (Q1), Q12.1 (G)
RPM_4070N: IC12.10 (O), IC14.1 (Y1)
SPD_4070N: IC12.4 (O), IC14.2 (Y0), JP3.1
SPI_CLK: IC1.11 (SCK), IC6.11 (SCK)
WAGO1_BAT: SV8.1, X3.1
WAGO1_BAT1: IC7.4 (I4), SV3.1, X4.1
WAGO2_CC: R55.1, SV8.2, X3.2
WAGO2_CC1: SV3.2, X4.2
WAGO3_G1: LED_G1.K (C), SV8.3, X3.3
WAGO3_G1.: R18.1, SV3.3, X4.3
WAGO4_G2: LED_G2.K (C), SV8.4, X3.4
WAGO4_G2.: R3.1, SV3.4, X4.4
WAGO5_G3: LED_G3.K (C), SV8.5, X3.5
WAGO5_G3.: R19.1, SV3.5, X4.5
WAGO6_G4: LED_G4.K (C), SV8.6, X3.6
WAGO6_G4.: R20.1, SV3.6, X4.6
WAGO7_G5: LED_G5.K (C), SV8.7, X3.7
WAGO7_G5.: R21.1, SV3.7, X4.7
WAGO8_N: LED_N.K (C), SV8.8, X3.8
WAGO8_N1: R22.1, SV3.8, X4.8
WAGO9_>: LED_>.A, SV8.9, X3.9
WAGO9_>1: IC7.1 (I1), SV3.9, X4.9
WAGO10_<>: LED_<>.A, SV8.10, X3.10
WAGO10_<>1: IC7.2 (I2), SV3.10, X4.10
WAGO11_<: LED_<.A, SV8.11, X3.11
WAGO11_<1: IC7.3 (I3), SV3.11, X4.11
WAGO13_SWP: LED_SWP.A, SV8.13, X3.13
WAGO13_SWP1: IC7.5 (I5), SV3.13, X4.13
WAGO14_CHK: LED_CHK.K (C), SV7.12, X3.14
WAGO14_CHK1: R89.1, SV4.12, X4.14
WAGO15_OIL: LED_OIL.K (C), SV7.11, X3.15
WAGO15_OIL1: R90.1, SV4.11, X4.15
WAGO16_TMP: LED_TMP.K (C), SV7.10, X3.16
WAGO16_TMP1: R91.1, SV4.10, X4.16
WAGO17_ALT: D1.2 (-), SV7.9, X3.17
WAGO17_ALT1: D4.2 (-), SV4.9, X4.17
WAGO18_RES: LED_RES.K (C), SV7.8, X3.18
WAGO18_RES1: R93.1, SV4.8, X4.18
WAGO19_ABS: LED_ABS.A, SV7.7, X3.19
WAGO19_ABS1: IC7.7 (I7), SV4.7, X4.19
WAGO20_BT: LED_BT.K (C), SV7.6, X3.20
WAGO20_BT1: R95.1, SV4.6, X4.20
WAGO21_WRN: LED_WRN.K (C), SV7.5, X3.21
WAGO21_WRN1: R94.1, SV4.5, X4.21
WAGO22_HIB: LED_HIB.A, SV7.4, X3.22
WAGO22_HIB1: IC7.8 (I8), SV4.4, X4.22
WAGO23_SPD: LED_SPD.K (C), PAD_2_SPEED_FREQUENZZäHLER1.1, R4.2, SV7.3, X3.23
WAGO23_SPD1: IC12.5 (I0), R38.1, SV4.3, X4.23
WAGO24_RPM: PAD_2_RPM_FREQUENZZäHLER2.1, Q9.1 (G), SV7.2, X3.24
WAGO24_RPM1: R39.2, SV4.2, X4.24
WAGO25_START: SV7.1, X3.25
WAGO25_START1: SV4.1, X4.25

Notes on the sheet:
Zündugsplus Choke Öldrucklampe Temperaturlampe Ladekontrolllampe Tankgeber (100hm) ABS-Lampe Lampentest Warnlampe Fernlichtlampe Geschwindigkeitssignal neu RPM
DauerPlus Konstant-Strom für LEDs Gang 1 Gang 2 Gang 3 Gang 4 Gang 5 Neutrallampe Blinker rechts Blinker zusammen Blinker links Masse
DauerPlus Batterie 12V (rot weiss) Ganganzeige Signal C (gelb weiss) Ganganzeige Signal B (gelb schwarz) Ganganzeige Signal A (gelb dunkelblau) 12V/350mA zum Starknopf (schwarz grün) Zündungsplus 12V (grün schwarz) Reservelampe (weiss) ABS Leuchte (blau) Ladekontrollleuchte (schaltet auf Masse) (vi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
Masse (braun) Lampentest (schaltet auf Masse)(weiss blau) Fernlichtlampe (12V) (weiss) Drehzahl Zündspule (schwarz blau) Blinker rechts (blau scharz) Masse (braun) Blinker links (blau rot) nicht angeschlossen Tachosiganl zum Blinrelais (balu grün) Tachogeber (gelb) Masse Tachobeger (braun) Tachobel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
Start
10V
Dezimal to Binär Decoder
data
clock
OE_ set to 5V:high imp
latch
thermistor:tank leer
thermistor:tank voll
Schliesser:tank leer
Schliesser:tank voll (default)
Startknopf +12V
15Bit werden gebraucht von 16Bit
Spannung an Reserve
2.5V an AD Wandler=6V auf BEP
Spannungsteiler 6V auf 2.5V
Set to 0 to disable manual gear shift(all 4028 outputs=0) and enable arduino steering
SPI_MOSI
SPI_Clock
SPI_SELoutputs
L:X0 (Speed) selected on common in
common in
speed in
RPM in
common out
speed out
Buffer
RPM out
Analog Umschalter
nur 2 der 4 Eingänge werden gebraucht 1. common+ Select oder 2. RPM + speed in
6 eingänge total
3 ausgänge multiplexer data-->MISO clock and strobe could be shared with input mux
2 (optionale) ausgänge AD Wandler
2 ausgänge 1. speed + RPM oder 2 nur common out (Select ist bei Input)
2 Strom 1. GND 2. 5V (optional)
Stromversorgung (12V + GND)

Board: 2 copper layers, 225 parts (0 on the bottom side), 212 nets, no tracks yet.

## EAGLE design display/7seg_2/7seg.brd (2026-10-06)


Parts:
A: 1,6/0,9
B: 1,6/0,9
C: 1,6/0,9
DIS1: HD-H103; HDSP-M
GND: 1,6/0,9
IC1: 4511D; SO16
R1, R2, R3, R4, R5, R6, R7: 1k; R0805
R8, R9, R10: 100k; R0805
VCC: 1,6/0,9

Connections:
GND: DIS1.3 (CC), DIS1.8 (CC), IC1.5 (LE), IC1.6 (ID), IC1.8 (VSS)
unnamed: IC1.13 (A), R1.1
unnamed: DIS1.7 (A), R1.2
unnamed: IC1.12 (B), R2.1
unnamed: DIS1.6 (B), R2.2
unnamed: IC1.11 (C), R3.1
unnamed: DIS1.4 (C), R3.2
unnamed: IC1.10 (D), R4.1
unnamed: DIS1.2 (D), R4.2
unnamed: IC1.9 (E), R5.1
unnamed: DIS1.1 (E), R5.2
unnamed: IC1.15 (F), R6.1
unnamed: DIS1.9 (F), R6.2
unnamed: IC1.14 (G), R7.1
unnamed: DIS1.10 (G), R7.2
unnamed: A.1, IC1.7 (IA), R8.2
unnamed: B.1, IC1.1 (IB), R9.2
unnamed: C.1, IC1.2 (IC), R10.2
VCC: IC1.3 (LT), IC1.4 (BI), IC1.16 (VDD), R8.1, R9.1, R10.1



Board: 2 copper layers, 160.0 x 100.0 mm, 17 parts (2 on the bottom side), 19 nets.

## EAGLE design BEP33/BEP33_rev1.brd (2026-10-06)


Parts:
FID1, FID2: FIDUCIAL; FIDUCIAL_1MM
FID1B, FID2B: FIDUCIALFIDUCIAL_1MM_WITH_SOLDERMASK; FIDUCIAL_1MM_WITH_SOLDERMASK

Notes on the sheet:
Standard panel Fiducial
panel Fiducial with solder mask around fiducial

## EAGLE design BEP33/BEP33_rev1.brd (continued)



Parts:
1, 2: 2081-1132; 12-PIN
6V, 10V: TPSB2.0; B2.0
C2: 10u; C1206
C15, C101: 4.7u; C0805
C63: C-EUC1812K; C1812K
C102, C110: 100nF; C0805
C103, C104: 100nF,; C0805
C105, C106: 100nF.; C0805
C107, C108: 100u; C1206
C109: 2.2nF; C0805
D1, D2, D74: SS12; DO-214AC_SLIM
D4: Zen11; SOD-123_MINI-SMA
D101: Zen15; DO214AA
D102, D103: 1N4007,; DO-214AC
D104: SM6TDO214AA_BI; DO214AA_BI
D105, D106: 1N4007.; DO-214AC
D107, D110: 1N5817; DO-214AC_SLIM
D108, D109: 1N5817.; DO-214AC_SLIM
D112: 1N4007; DO-214AC
FID101, FID102, FID103, FID104: FIDUCIAL; FIDUCIAL_1MM
IC101: LM2904; SO08
IC102: 78L06; SOT89_ROUND
IC104: 78L10; SOT89_ROUND
IC105: 4028; SO16
IC107: ULN2004; SO16
IC108: LM339; SO14
IC109: 317TO202H_NOHOLE; TO220H_NOHOLE
IC110: 555; SO08
IC111: 4538; SO16
JP101, JP102, JP103, JP104: JP2EJP2_SMALLPADS; JP2_SMALLPADS
JP105: JP2E_ORIG; JP2_ORIG_SMALLPADS
LED101, LED102, LED103, LED104, LED105, LED106: LEDLD260; LD260
Q1, Q3, Q106, Q107: J1; SOT-23
Q2, Q104, Q105: BA; SOT89
Q101, Q102: BA.; SOT89
Q103: MY; SOT89
R1, R2, R3, R10, R109, R110, R111, R125, R130, R135, R141: 104; R0805
R4, R12, R13, R138: 100; R0805
R5, R9, R102, R106, R134: 13; R1206
R6, R119, R133: 2201; R0805
R8, R105, R116, R126: 4701; R0805
R101, R112, R115, R128: 102; R0805
R103, R104: R_user; R0805
R107, R108, R113, R114, R120, R124, R132, R146: 1002; R0805
R117, R122, R123, R140, R145: 2702; R0805
R121, R131: 1502; R0805
R127, R129, R136, R137: 47; V235/17_1MM
R142: (1000); R0805
R143: (101); R0805
R144: (1002); R0805
SJ101: SJ
SJMP: SJ
START: TPSB2.0; B2.0
TP1, TP2, TP3, TP4, TP5, TP6, TP7, TP8, TP9, TP10, TP11, TP12, TP13, TP16, TP17, TP18, TP19, TP21, TP22, TP23, TP25, TP26: TPSB2.0; B2.0
TP24: TPSB1,27; B1,27
X101: CON_BMWV2; 24-PIN_V2
X102: 22-23-2021
X103: 22-23-2051

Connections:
+10V: 10V.TP, C102.1, IC104.1 (OUT), IC110.4 (R), IC110.8 (V+), IC111.3 (CD), IC111.5 (B), IC111.13 (CD), IC111.16 (VDD), R10.2, R145.2; also elsewhere on the board
+12V: 2.1, C2.1, D101.C, IC102.3 (IN), IC104.3 (IN), IC105.16 (VDD), IC107.9 (CD+), JP101.2, R12.2, R13.2, R102.1, R106.1, R109.2, R110.2, R111.2, R135.1, TP12.TP, X103.1; also elsewhere on the board
+12V1: 2.11, Q103.2 (C), R119.1, TP26.TP
GND: 1.12, C2.2, C15.1, C101.2, C102.2, C103.2, C104.2, C105.2, C106.1, C107.2, C108.2, C109.1, C110.2, D4.A, D101.A, D104.A, D105.1 (+), IC101.4 (V-), IC102.2 (GND), IC102.2@1 (GND), IC104.2 (GND), IC104.2@1 (GND), IC105.8 (VSS), IC105.11 (D), IC107.8 (GND), IC108.12 (GND), IC110.1 (GND), IC111.1 (T1), IC111.8 (VSS), IC111.15 (T1), Q1.2 (S), Q3.2 (S), Q107.2 (S), R4.1, R5.2, R6.2, R101.2, R103.2, R104.2, R107.1, R114.1, R123.1, R132.1, R136.1, R137.1, R141.2, R143.2, X101.13, X101.18, X101.23, X102.1, X103.5; also elsewhere on the board
unnamed: 2.9, D107.1 (+), D108.1 (+), JP102.1, JP103.2, TP24.TP
unnamed: IC105.10 (A), R3.1, R3.2, R111.1, X101.4, X103.2
unnamed: IC105.13 (B), R2.1, R2.2, R110.1, X101.3, X103.3
unnamed: 2.7, LED101.A, TP22.TP, X101.8
unnamed: Q101.3 (E), R102.2
unnamed: Q2.1 (B), R8.1
unnamed: IC101.2 (-IN), R107.2
unnamed: R127.2, R129.1
unnamed: Q102.3 (E), R106.2
unnamed: D105.2 (-), Q104.2 (C), START.TP, X101.5
unnamed: 2.2, D109.2 (-), LED102.K (C), TP16.TP, X101.12
unnamed: 2.3, D108.2 (-), LED103.K (C), TP17.TP, X101.11
unnamed: 2.4, D107.2 (-), LED104.K (C), TP18.TP, X101.10
unnamed: IC109.3 (VI), Q105.2 (C)
unnamed: IC108.6 (-IN), IC108.8 (-IN), R120.1
unnamed: IC105.12 (C), R1.1, R1.2, R109.1, X101.2, X103.4
unnamed: IC105.15 (Q3), IC107.5 (I5)
unnamed: 2.8, D110.2 (-), LED106.K (C), TP23.TP, X101.14
unnamed: 1.9, D102.1 (+), TP9.TP, X101.17
unnamed: 1.11, D103.1 (+), TP11.TP, X101.19
unnamed: IC111.9 (!Q), IC111.11 (B), R146.2
unnamed: D104.C, R105.2, X101.22
unnamed: C101.1, IC101.3 (+IN), R105.1
unnamed: 1.6, IC107.13 (O4), TP6.TP
unnamed: 1.7, IC107.14 (O3), TP7.TP
unnamed: D1.2 (-), Q104.3 (E), R12.1, R13.1
unnamed: 2.6, JP105.2, TP21.TP
unnamed: JP101.1, R119.2
unnamed: C105.1, IC108.9 (+IN), R122.2, R123.2
unnamed: C106.2, IC108.14 (OUT), R126.2
unnamed: Q3.3 (D), R8.2
unnamed: LED101.K (C), R143.1
unnamed: IC109.1 (ADJ), R120.2, R134.1, X101.7
unnamed: Q105.1 (B), R126.1
unnamed: IC105.2 (Q2), IC107.7 (I7)
unnamed: 1.3, IC107.11 (O6), TP3.TP
unnamed: 1.5, IC107.12 (O5), TP5.TP
unnamed: LED102.A, LED103.A, LED104.A, LED105.A, LED106.A, R142.1
unnamed: R140.2, X101.16
unnamed: Q104.1 (B), R128.2
unnamed: IC105.3 (Q0), IC107.1 (I1), IC107.2 (I2), Q1.1 (G), Q106.1 (G)
unnamed: C107.1, R125.1, R130.2
unnamed: C108.1, IC108.4 (-IN), IC108.10 (-IN), R130.1
unnamed: IC108.5 (+IN), IC108.11 (+IN), R131.1, R132.2, R133.2
unnamed: Q107.3 (D), R138.2
unnamed: IC111.6 (Q), Q3.1 (G)
unnamed: IC105.1 (Q4), IC107.4 (I4)
unnamed: R115.1, X101.21
unnamed: IC107.16 (O1), Q106.3 (D), R9.1
unnamed: 2.10, TP25.TP, X101.15
unnamed: D106.1 (+), R127.1
unnamed: 2.5, D106.2 (-), LED105.K (C), TP19.TP, X101.9
unnamed: IC105.14 (Q1), IC107.6 (I6)
unnamed: Q101.1 (B), Q102.1 (B), Q102.2 (C), R101.1, R103.1, R104.1, X102.2
unnamed: 1.8, R9.2, TP8.TP
unnamed: 1.2, Q101.2 (C), TP2.TP
unnamed: IC108.13 (OUT), JP105.1, Q107.1 (G), R135.2
unnamed: IC105.6 (Q5), IC107.3 (I3)
unnamed: IC109.2 (VO), R134.2
unnamed: IC110.5 (CV), R144.2
unnamed: 1.4, IC107.10 (O7), TP4.TP
unnamed: 1.1, D2.2 (-), TP1.TP
unnamed: IC108.7 (+IN), R121.1, R122.1
unnamed: Q106.2 (S), R4.2
unnamed: Q103.1 (B), R6.1, R116.2
unnamed: IC110.3 (Q), IC111.4 (A), IC111.12 (A), R144.1
unnamed: D112.1 (+), R140.1
unnamed: IC107.15 (O2), R128.1
unnamed: C110.1, IC111.14 (T2), R145.1
unnamed: 2.12, R146.1, TP13.TP
unnamed: D2.1 (+), X101.1
unnamed: IC101.1 (OUT), R108.2
unnamed: 1.10, D102.2 (-), D103.2 (-), JP104.1, SJ101.1, TP10.TP
unnamed: JP104.2, R136.2, R137.2, SJ101.2
unnamed: D109.1 (+), JP102.2
unnamed: C103.1, R108.1, R112.1
unnamed: IC101.5 (+IN), Q1.3 (D), R112.2, R117.2
unnamed: D110.1 (+), JP103.1
unnamed: JP105.3, R138.1
unnamed: Q103.3 (E), R5.1
unnamed: IC101.6 (-IN), R113.1, R114.2
unnamed: C109.2, D4.C, D112.2 (-), IC110.2 (TR), IC110.6 (THR), R141.1
unnamed: C15.2, IC111.2 (T2), R10.1
unnamed: Q2.2 (C), R129.2, SJMP.2
unnamed: IC101.7 (OUT), R115.2, R116.1, R117.1
unnamed: IC108.2 (OUT), R133.1
unnamed: IC108.1 (OUT), R124.2, R125.2
V+: D1.1 (+), Q2.3 (E), Q105.3 (E), SJMP.1, X101.6; also elsewhere on the board
VCC: 6V.TP, C104.1, IC101.8 (V+), IC102.1 (OUT), IC108.3 (V+), R113.2, R121.2, R124.1, R131.2, R142.2; also elsewhere on the board

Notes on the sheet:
6V regulated for Opamps
current source 96mA
ZündungsPlus
Zündugsplus Choke Öldrucklampe Temperaturlampe Ladekontrolllampe Tankgeber (100hm) ABS-Lampe Lampentest Warnlampe Fernlichtlampe Geschwindigkeitssignal Menütaster
DauerPlus Konstant-Strom für LEDs Gang 1 Gang 2 Gang 3 Gang 4 Gang 5 Neutrallampe Blinker rechts Blinker zusammen Blinker links Masse
DauerPlus Batterie 12V (rot weiss) Ganganzeige Signal C (gelb weiss) Ganganzeige Signal B (gelb schwarz) Ganganzeige Signal A (gelb dunkelblau) 12V/350mA zum Starknopf (schwarz grün) Zündungsplus 12V (grün schwarz) Reservelampe (weiss) ABS Leuchte (blau) Ladekontrollleuchte (schaltet auf Masse) (vi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
Masse (braun) Lampentest (schaltet auf Masse)(weiss blau) Fernlichtlampe (12V) (weiss) Drehzahl Zündspule (schwarz blau) Blinker rechts (blau scharz) Masse (braun) Blinker links (blau rot) nicht angeschlossen Tachosiganl zum Blinrelais (balu grün) Tachogeber (gelb) Masse Tachobeger (braun) Tachobel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
4.7V
Stromquelle für Gang LEDs. Für mehr als 12mA muss ein Widerstand "R_user" eingelötet werden. Für weniger muss der 1kOhm SMD Widerstand neben R_user entfernt werden I = 12V/1kOhm(default)+12V/R_user I= 12mA (default) + 12V/R_user Beispiel: R_user Strom in LEDs 1 kOhm 22-26mA ohne 11-13mA
Gang 1
Gang 2
Gang 3
Gang 4
Gang 5
Variante "eine LED leuchtet"
Variante "alle LEDs bis und mit Gang X leuchten"
Klemmleisten Ausgang:
Klemmleisten Ausgang:
an Zündungsplus anhängen (Neutral leuchtet wenn Gang 0 eingelegt und Zündschlüssel steckt )
an Ausgang "Neutrallampe" anhängen
Neutrallampe für eigene Ganganzeige
Externe Beschaltung
Anzeige:
nicht bestückt
rising edge trigger A
BAR
RES
BL resistors
Standard panel Fiducial
panel Fiducial with solder mask around fiducial
non retriggerable
retriggerable



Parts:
6V3, 10V3: TPSB2.0; B2.0
7, 8: 2081-1132; 12-PIN
C27, C28: 100u; C1206
C29, C36: 100nF,; C0805
C30, C37: 4.7u; C0805
C31, C32: 100nF.; C0805
C33: 2.2nF; C0805
C34, C35: 100nF; C0805
C38: 10u; C1206
D32, D33: 1N4007,; DO-214AC
D34, D39: 1N4007.; DO-214AC
D35, D38: 1N5817; DO-214AC_SLIM
D36, D37: 1N5817.; DO-214AC_SLIM
D40: 1N4007; DO-214AC
D41: Zen15; DO214AA
D42: SM6TDO214AA_BI; DO214AA_BI
D43, D44: SS12; DO-214AC_SLIM
D45: Zen11; SOD-123_MINI-SMA
FID11, FID12, FID13, FID14: FIDUCIAL; FIDUCIAL_1MM
IC19: 4028; SO16
IC20: 317TO202H_NOHOLE; TO220H_NOHOLE
IC21: ULN2004; SO16
IC22: LM339; SO14
IC23: 78L06; SOT89_ROUND
IC24: 555; SO08
IC25: 4538; SO16
IC26: 78L10; SOT89_ROUND
IC27: LM2904; SO08
JP11, JP13, JP14, JP15: JP2EJP2_SMALLPADS; JP2_SMALLPADS
JP12: JP2E_ORIG; JP2_ORIG_SMALLPADS
LED13, LED14, LED15, LED16, LED17, LED18: LEDLD260; LD260
Q24, Q27, Q32: BA; SOT89
Q25, Q26: BA.; SOT89
Q28: MY; SOT89
Q29, Q30, Q31, Q33: J1; SOT-23
R166, R168, R199, R200: 47; V235/17_1MM
R167, R190, R191, R213, R216: 13; R1206
R169, R170, R171, R176, R177, R195, R196, R210, R211, R212, R218: 104; R0805
R172, R182, R193, R217: 4701; R0805
R173, R174, R179, R181, R203, R204, R207, R208: 1002; R0805
R175, R178: 1502; R0805
R180, R202, R214: 2201; R0805
R183, R192, R198, R201, R206: 2702; R0805
R184, R186, R189, R205: 102; R0805
R185, R209: R_user; R0805
R187: (101); R0805
R188: (1000); R0805
R194, R215, R219, R220: 100; R0805
R197: (1002); R0805
SJ3: SJ
SJMP3: SJ
START3: TPSB2.0; B2.0
TP70, TP71, TP72, TP73, TP74, TP75, TP76, TP77, TP78, TP79, TP80, TP81, TP82, TP83, TP84, TP85, TP86, TP87, TP89, TP90, TP91, TP92: TPSB2.0; B2.0
TP88: TPSB1,27; B1,27
X7: CON_BMWV2; 24-PIN_V2
X8: 22-23-2051
X9: 22-23-2021

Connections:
+10V: 10V3.TP, C34.1, IC24.4 (R), IC24.8 (V+), IC25.3 (CD), IC25.5 (B), IC25.13 (CD), IC25.16 (VDD), IC26.1 (OUT), R201.2, R218.2; also elsewhere on the board
+12V: 8.1, C38.1, D41.C, IC19.16 (VDD), IC21.9 (CD+), IC23.3 (IN), IC26.3 (IN), JP11.2, R169.2, R170.2, R171.2, R190.1, R191.1, R195.1, R219.2, R220.2, TP91.TP, X8.1; also elsewhere on the board
+12V4: 8.11, Q28.2 (C), R202.1, TP90.TP
GND: 7.12, C27.2, C28.2, C29.2, C30.2, C31.2, C32.1, C33.1, C34.2, C35.2, C36.2, C37.1, C38.2, D39.1 (+), D41.A, D42.A, D45.A, IC19.8 (VSS), IC19.11 (D), IC21.8 (GND), IC22.12 (GND), IC23.2 (GND), IC23.2@1 (GND), IC24.1 (GND), IC25.1 (T1), IC25.8 (VSS), IC25.15 (T1), IC26.2 (GND), IC26.2@1 (GND), IC27.4 (V-), Q29.2 (S), Q31.2 (S), Q33.2 (S), R173.1, R179.1, R183.1, R184.2, R185.2, R187.2, R196.2, R199.1, R200.1, R208.1, R209.2, R213.2, R214.2, R215.1, X7.13, X7.18, X7.23, X8.5, X9.1; also elsewhere on the board
unnamed: R166.2, R168.1
unnamed: 8.9, D35.1 (+), D36.1 (+), JP13.1, JP14.2, TP88.TP
unnamed: IC19.10 (A), R171.1, R212.1, R212.2, X7.4, X8.2
unnamed: IC19.13 (B), R170.1, R211.1, R211.2, X7.3, X8.3
unnamed: D39.2 (-), Q24.2 (C), START3.TP, X7.5
unnamed: IC19.12 (C), R169.1, R210.1, R210.2, X7.2, X8.4
unnamed: 8.7, LED17.A, TP86.TP, X7.8
unnamed: 8.2, D37.2 (-), LED13.K (C), TP81.TP, X7.12
unnamed: 8.3, D36.2 (-), LED14.K (C), TP82.TP, X7.11
unnamed: 8.4, D35.2 (-), LED15.K (C), TP83.TP, X7.10
unnamed: 8.8, D38.2 (-), LED18.K (C), TP87.TP, X7.14
unnamed: 7.9, D32.1 (+), TP78.TP, X7.17
unnamed: 7.11, D33.1 (+), TP80.TP, X7.19
unnamed: D42.C, R172.2, X7.22
unnamed: C30.1, IC27.3 (+IN), R172.1
unnamed: IC22.1 (OUT), R176.2, R181.2
unnamed: C27.1, R176.1, R177.2
unnamed: C28.1, IC22.4 (-IN), IC22.10 (-IN), R177.1
unnamed: IC22.5 (+IN), IC22.11 (+IN), R178.1, R179.2, R180.2
unnamed: C31.1, IC22.9 (+IN), R183.2, R192.2
unnamed: C32.2, IC22.14 (OUT), R182.2
unnamed: Q27.1 (B), R182.1
unnamed: IC19.2 (Q2), IC21.7 (I7)
unnamed: 7.5, IC21.12 (O5), TP74.TP
unnamed: IC19.1 (Q4), IC21.4 (I4)
unnamed: 8.10, TP89.TP, X7.15
unnamed: 8.5, D34.2 (-), LED16.K (C), TP84.TP, X7.9
unnamed: D34.1 (+), R166.1
unnamed: IC19.6 (Q5), IC21.3 (I3)
unnamed: 7.4, IC21.10 (O7), TP73.TP
unnamed: IC20.1 (ADJ), R167.1, R174.2, X7.7
unnamed: IC22.6 (-IN), IC22.8 (-IN), R174.1
unnamed: 7.2, Q26.2 (C), TP71.TP
unnamed: 7.1, D44.2 (-), TP70.TP
unnamed: R198.2, X7.16
unnamed: IC19.15 (Q3), IC21.5 (I5)
unnamed: 7.6, IC21.13 (O4), TP75.TP
unnamed: 7.7, IC21.14 (O3), TP76.TP
unnamed: 8.6, JP12.2, TP85.TP
unnamed: LED17.K (C), R187.1
unnamed: LED13.A, LED14.A, LED15.A, LED16.A, LED18.A, R188.1
unnamed: Q24.1 (B), R189.2
unnamed: IC19.3 (Q0), IC21.1 (I1), IC21.2 (I2), Q30.1 (G), Q31.1 (G)
unnamed: IC19.14 (Q1), IC21.6 (I6)
unnamed: 7.3, IC21.11 (O6), TP72.TP
unnamed: Q25.1 (B), Q25.2 (C), Q26.1 (B), R184.1, R185.1, R209.1, X9.2
unnamed: Q26.3 (E), R191.2
unnamed: Q25.3 (E), R190.2
unnamed: IC22.7 (+IN), R175.1, R192.1
unnamed: IC27.2 (-IN), R173.2
unnamed: Q28.1 (B), R193.2, R214.1
unnamed: Q29.3 (D), R194.2
unnamed: IC20.2 (VO), R167.2
unnamed: IC20.3 (VI), Q27.2 (C)
unnamed: IC24.5 (CV), R197.2
unnamed: IC24.3 (Q), IC25.4 (A), IC25.12 (A), R197.1
unnamed: D40.1 (+), R198.1
unnamed: 7.10, D32.2 (-), D33.2 (-), JP15.1, SJ3.1, TP79.TP
unnamed: JP15.2, R199.2, R200.2, SJ3.2
unnamed: IC25.9 (!Q), IC25.11 (B), R203.2
unnamed: C35.1, IC25.14 (T2), R201.1
unnamed: JP11.1, R202.2
unnamed: IC21.15 (O2), R189.1
unnamed: 8.12, R203.1, TP92.TP
unnamed: D37.1 (+), JP13.2
unnamed: IC27.1 (OUT), R204.2
unnamed: C36.1, R204.1, R205.1
unnamed: IC27.5 (+IN), Q31.3 (D), R205.2, R206.2
unnamed: IC27.6 (-IN), R207.1, R208.2
unnamed: D38.1 (+), JP14.1
unnamed: JP12.3, R194.1
unnamed: IC22.13 (OUT), JP12.1, Q29.1 (G), R195.2
unnamed: R186.1, X7.21
unnamed: IC21.16 (O1), Q30.3 (D), R216.1
unnamed: D43.2 (-), R219.1, R220.1
unnamed: 7.8, R216.2, TP77.TP
unnamed: Q30.2 (S), R215.2
unnamed: D44.1 (+), X7.1
unnamed: Q28.3 (E), R213.1
unnamed: C33.2, D40.2 (-), D45.C, IC24.2 (TR), IC24.6 (THR), R196.1
unnamed: Q32.1 (B), R217.1
unnamed: Q33.3 (D), R217.2
unnamed: Q32.2 (C), R168.2, SJMP3.2
unnamed: IC27.7 (OUT), R186.2, R193.1, R206.1
unnamed: IC22.2 (OUT), R180.1
unnamed: IC25.6 (Q), Q33.1 (G)
unnamed: C37.2, IC25.2 (T2), R218.1
V+: D43.1 (+), Q24.3 (E), Q27.3 (E), Q32.3 (E), SJMP3.1, X7.6; also elsewhere on the board
VCC: 6V3.TP, C29.1, IC22.3 (V+), IC23.1 (OUT), IC27.8 (V+), R175.2, R178.2, R181.1, R188.2, R207.2; also elsewhere on the board

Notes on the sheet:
6V regulated for Opamps
current source 96mA
ZündungsPlus
Zündugsplus Choke Öldrucklampe Temperaturlampe Ladekontrolllampe Tankgeber (100hm) ABS-Lampe Lampentest Warnlampe Fernlichtlampe Geschwindigkeitssignal Menütaster
DauerPlus Konstant-Strom für LEDs Gang 1 Gang 2 Gang 3 Gang 4 Gang 5 Neutrallampe Blinker rechts Blinker zusammen Blinker links Masse
DauerPlus Batterie 12V (rot weiss) Ganganzeige Signal C (gelb weiss) Ganganzeige Signal B (gelb schwarz) Ganganzeige Signal A (gelb dunkelblau) 12V/350mA zum Starknopf (schwarz grün) Zündungsplus 12V (grün schwarz) Reservelampe (weiss) ABS Leuchte (blau) Ladekontrollleuchte (schaltet auf Masse) (vi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
Masse (braun) Lampentest (schaltet auf Masse)(weiss blau) Fernlichtlampe (12V) (weiss) Drehzahl Zündspule (schwarz blau) Blinker rechts (blau scharz) Masse (braun) Blinker links (blau rot) nicht angeschlossen Tachosiganl zum Blinrelais (balu grün) Tachogeber (gelb) Masse Tachobeger (braun) Tachobel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
4.7V
Stromquelle für Gang LEDs. Für mehr als 12mA muss ein Widerstand "R_user" eingelötet werden. Für weniger muss der 1kOhm SMD Widerstand neben R_user entfernt werden I = 12V/1kOhm(default)+12V/R_user I= 12mA (default) + 12V/R_user Beispiel: R_user Strom in LEDs 1 kOhm 22-26mA ohne 11-13mA
Gang 1
Gang 2
Gang 3
Gang 4
Gang 5
Variante "eine LED leuchtet"
Variante "alle LEDs bis und mit Gang X leuchten"
Klemmleisten Ausgang:
Klemmleisten Ausgang:
an Zündungsplus anhängen (Neutral leuchtet wenn Gang 0 eingelegt und Zündschlüssel steckt )
an Ausgang "Neutrallampe" anhängen
Neutrallampe für eigene Ganganzeige
Externe Beschaltung
Anzeige:
nicht bestückt
rising edge trigger A
BAR
RES
BL resistors
Standard panel Fiducial
panel Fiducial with solder mask around fiducial
non retriggerable
retriggerable



Board: 2 copper layers, 210.4 x 166.2 mm, 306 parts (50 on the bottom side), 181 nets.

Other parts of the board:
U$1, U$2, U$7, U$8: CE_10.00
